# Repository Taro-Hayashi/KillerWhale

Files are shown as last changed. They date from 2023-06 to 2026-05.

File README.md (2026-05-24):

# Killer Whale ビルドガイド スタートページ（[English](doc/README_EN.md)）

1. スタートページ（このページ）
2. [ベースユニットの組み立て](doc/右手用/2_ベースユニット.md)
3. [側面ユニットの組み立て](doc/右手用/3_側面ユニット_トラックボール.md)
4. [天面ユニットの組み立て](doc/右手用/4_天面ユニット.md)
5. [追加ユニットの組み立て](doc/右手用/5_追加ユニット.md)
6. [全体の組み立て](doc/右手用/6_全体の組み立て.md)
7. [カスタマイズ](doc/右手用/7_カスタマイズ.md)
8. [その他](doc/右手用/8_その他.md)

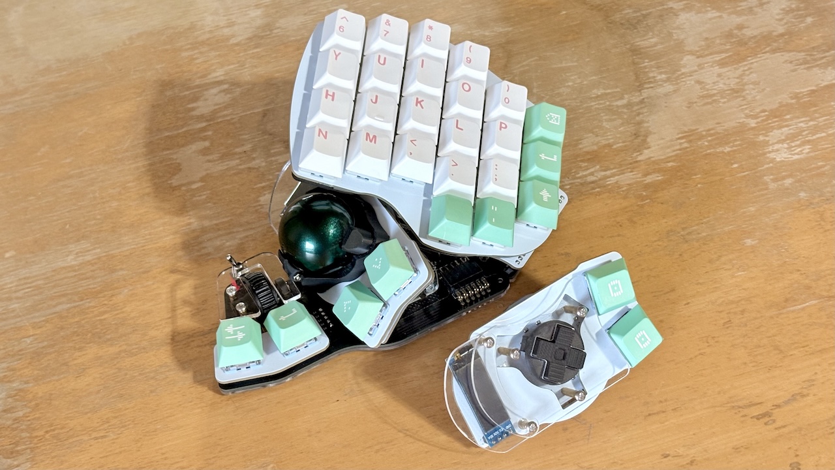
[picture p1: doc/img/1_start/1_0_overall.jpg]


> [!NOTE]
> 2025年5月下旬より一部の部品が3Dプリンター製に置き換わりました。写真や作例と差異がある場合があります。

大きな袋の中にスイッチプレートと6つの袋が入っています。
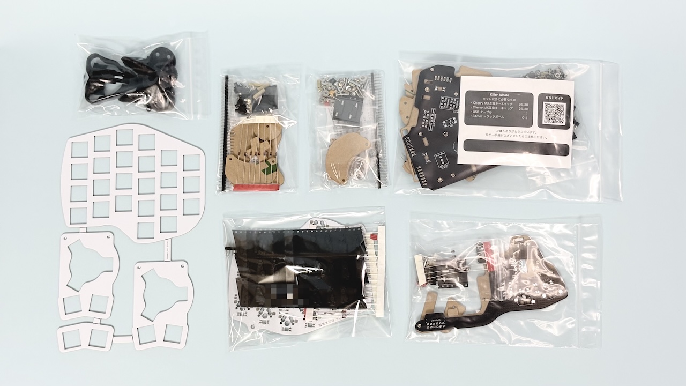
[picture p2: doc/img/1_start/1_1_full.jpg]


## キット以外に必要なもの（片手分）
|部品名|数||
|-|-|-|
|[キースイッチ](https://shop.yushakobo.jp/collections/all-switches)|26〜30|Cherry MX互換|
|[キーキャップ](https://shop.yushakobo.jp/collections/keycaps)|26〜30|Cherry MX互換|
|Type-C USBケーブル|1||
|34mm トラックボール|0~1|[遊舎工房](https://shop.yushakobo.jp/products/8020)、[Amazon](https://www.amazon.co.jp/gp/product/B07BDGSX5X)|

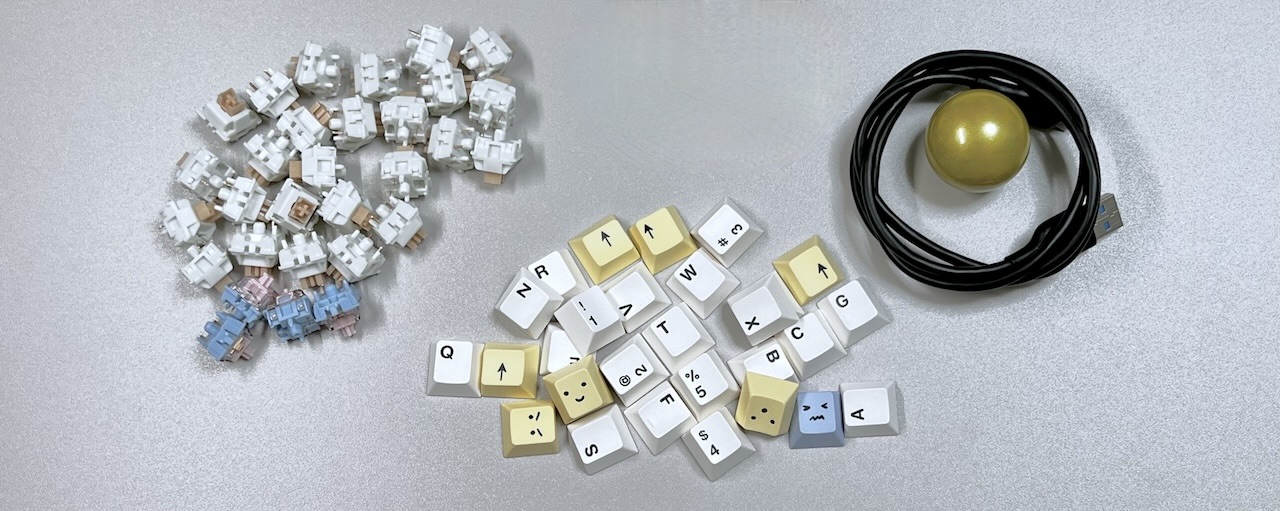
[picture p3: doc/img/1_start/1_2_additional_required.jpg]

### オプション（片手分）
<table>
    <tr>
      <td><a href="https://shop.yushakobo.jp/products/oled">OLEDモジュール</a></td>
      <td>1〜2</td>
      <td>通常は1個、予備の側面ユニットにも付けるならもう1個</td>
    </tr>
    <tr>
      <td>ピンソケット4ピン分</td>
      <td>1〜2</td>
      <td>OLEDモジュールを付け外しする場合</td>
    </tr>
    <tr>
      <td><a href="https://shop.yushakobo.jp/products/sk6812mini-e-10">LED（SK6812MINI-E)</a></td>
      <td>30〜36</td>
      <td>通常は33個、追加ユニットなしで30個、予備の側面ユニットに3個</td>
    </tr>
    <tr>
      <td><a href="https://shop.yushakobo.jp/products/trrs_cable">TRS、TRRSケーブル</a></td>
       <td>1</td>
      <td>2台を繋げて左右分割キーボードとして使用できます。  </td>
    </tr>
 </table>

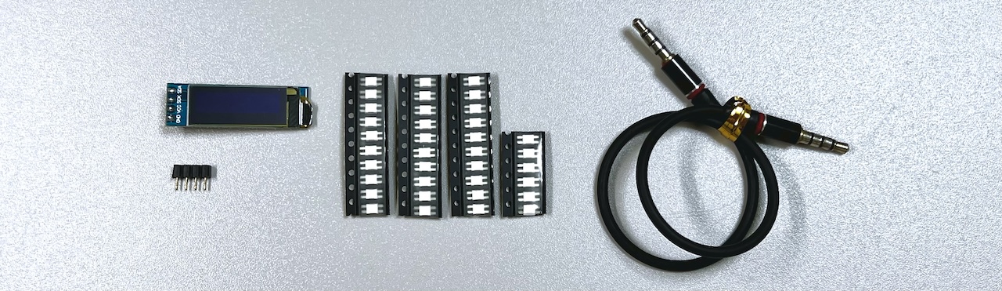
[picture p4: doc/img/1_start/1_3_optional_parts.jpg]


### 必要な工具
<table>
    <tr>
      <td>はんだごて</td>
    </tr>
    <tr>
      <td>はんだ</td>
    </tr>
    <tr>
      <td>ピンセット</td>
    </tr>
    <tr>
      <td>ニッパー</td>
    </tr>
    <tr>
      <td>カッター</td>
    </tr>
    <tr>
      <td>やすり</td>
    </tr>
    <tr>
      <td>精密ドライバー</td>
    </tr>
    <tr>
      <td>ナットをしめるもの（ラジオペンチ等）</td>
    </tr>
 </table>

### 別売ユニット
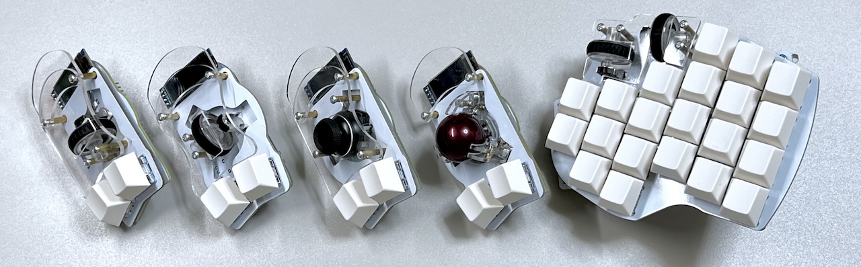
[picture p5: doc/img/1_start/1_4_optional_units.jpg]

- https://tarohayashi.booth.pm/items/4877491

### 別売3Dプリンター製部品
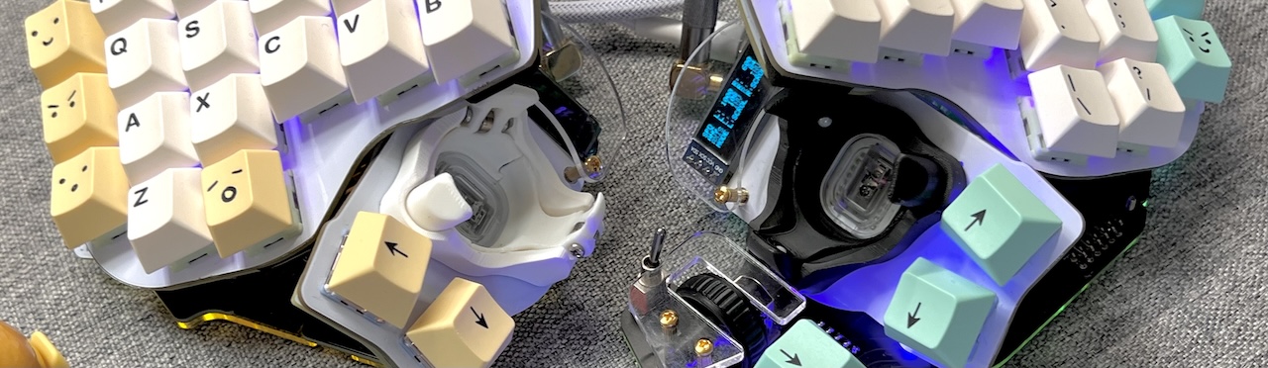
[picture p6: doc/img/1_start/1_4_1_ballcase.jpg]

- https://tarohayashi.booth.pm/items/6485486

### 3Dプリント品データ
- https://github.com/Taro-Hayashi/KillerWhale/blob/main/doc/3DP.md

### 色違いのアクリルプレート
<table>
    <tr>
        <td><a href="https://shop.yushakobo.jp/products/keyboard_acrylic_plate?variant=47873651245287">左手用</a></td>
        <td><a href="https://shop.yushakobo.jp/products/keyboard_acrylic_plate?variant=47873651278055">右手用</a></td>
        <td><a href="https://shop.yushakobo.jp/products/keyboard_acrylic_plate?variant=47873651310823">支柱</a></td>
    </tr>
 </table>

### そのほか対応しているもの
<table>
    <tr>
      <td><a href="https://shop.yushakobo.jp/products/31?variant=40815840067745">コンスルー20ピン 2.5mm</a></td>
    </tr>
    <tr>
      <td>ゲームボーイの十字キー</td>
    </tr>
    <tr>
      <td><a href="https://booth.pm/ja/items/5410034">3Dプリンター製ケース（Training&KBD様作）</a></td>
    </tr>
    <tr>
      <td><a href="https://nankatsukurouyo.myportfolio.com/killerwhale">トラックボールケース3Dプリントデータ（せう様作）</a></td>
    </tr>
    <tr>
      <td><a href="https://booth.pm/ja/items/5341402">Killer Whale Keyboard trackball case（NHRD様作）</a></td>
    </tr>
    <tr>
      <td><a href="https://booth.pm/ja/items/5676575">UndertowとUndertow Alterna</a></td>
    </tr>
 </table>

## 準備

### 3Dプリンター製部品の確認
以下の部品が入っている袋があることを確認します（ナット締め器が同梱されていることがあります）。
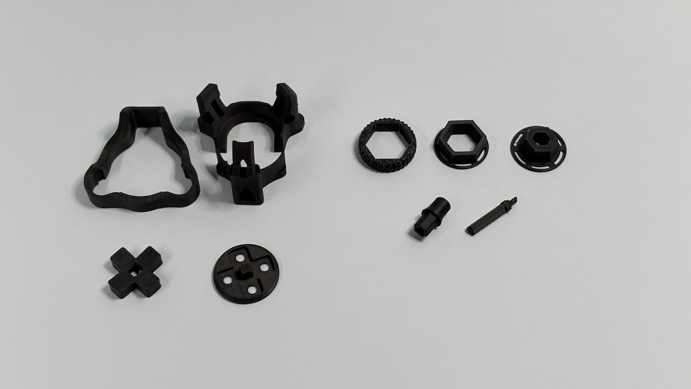
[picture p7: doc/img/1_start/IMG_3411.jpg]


### スイッチプレートの切り離し
スイッチプレートは繋がった状態で入っていて切り離して使います。
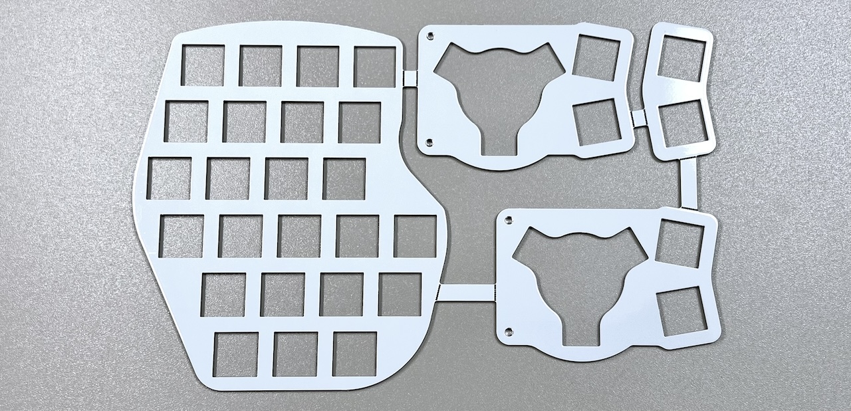
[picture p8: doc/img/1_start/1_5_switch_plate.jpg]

カッターで切れ目を入れ折って切り離します。
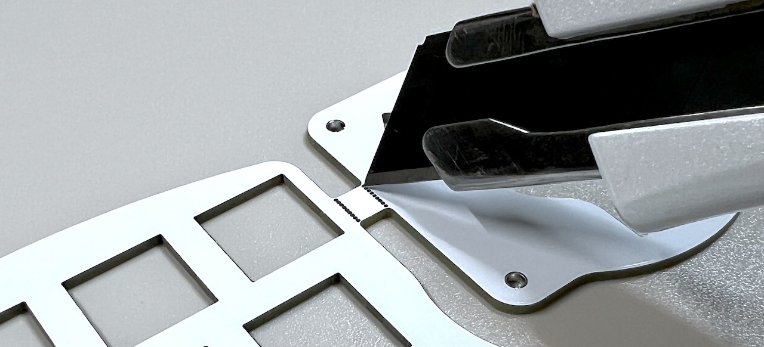
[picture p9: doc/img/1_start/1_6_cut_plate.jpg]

断面はやすりで綺麗にします。
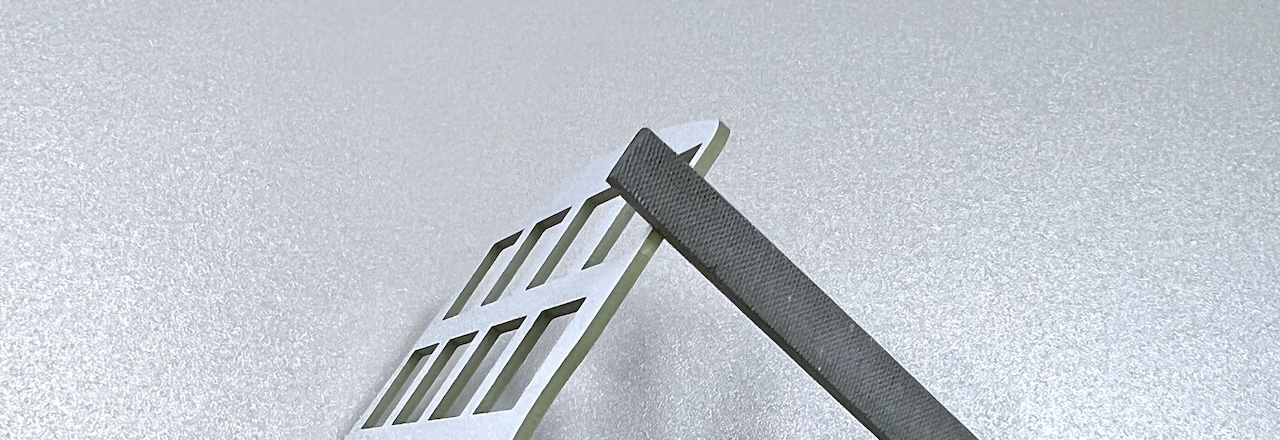
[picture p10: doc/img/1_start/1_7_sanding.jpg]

削った粉がコネクタ類やトラックボールのセンサーに入り込まないようにここで一度服を払ったり机の上の掃除をすると安心です。
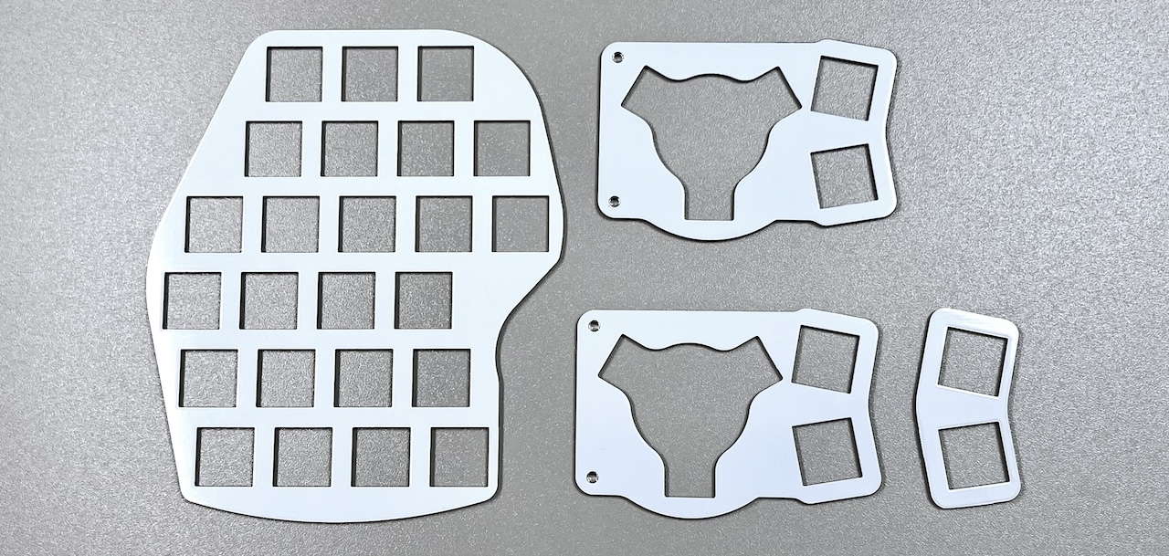
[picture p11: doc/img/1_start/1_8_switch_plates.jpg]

それぞれのユニットのビルドガイドでスイッチプレートとして使います。

## テスト用ファームウェアを書き込む
こちらのファイルをダウンロードしてください。
- [tarohayashi_killerwhale_solo_test.uf2
](https://github.com/Taro-Hayashi/KillerWhale/releases/latest/download/tarohayashi_killerwhale_solo_test.uf2)

Raspberry Pi PicoのBOOTSELボタン押しながらUSBケーブルでPCと接続すると、RPI-RP2というUSBメモリとして認識されます。
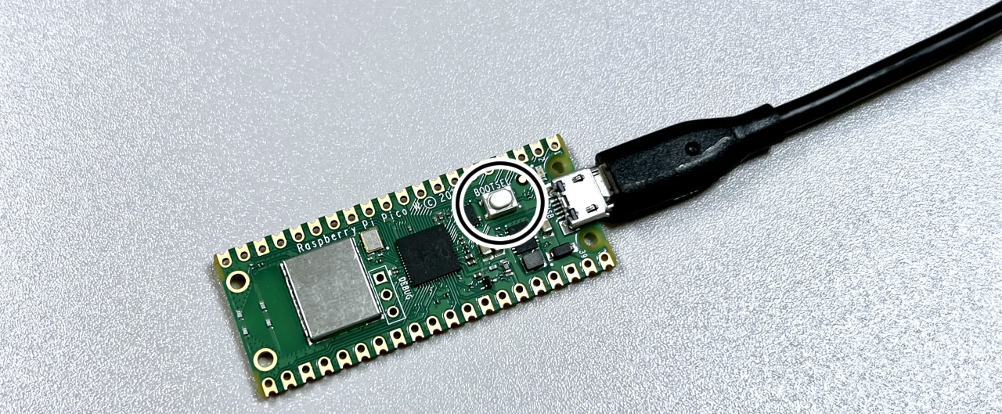
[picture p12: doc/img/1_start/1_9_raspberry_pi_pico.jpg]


ダウンロードしたファイルをドラッグ&ドロップしてドライブが自動的に消えたら成功です。
書き込みが終わったら一旦USBケーブルは外します。

### 左右を決める
キットを左右どちらで作るか決めてベースユニットの組み立てに進みます。
- [ベースユニット 左手用](doc/左手用/2_ベースユニット.md)
- [ベースユニット 右手用](doc/右手用/2_ベースユニット.md)

> [!NOTE]
> 左右のビルドガイドの違いは写真だけですが間違えやすいので合った側を見るのがおすすめです。

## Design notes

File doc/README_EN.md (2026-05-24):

# Killer Whale Build Manual First Page（[日本語](../README.md)）

1. Start Page
2. [BASE Unit](rightside/2_BASE.md)
3. [SIDE Unit](rightside/3_SIDE_TRACKBALL.md)
4. [TOP Unit](rightside/4_TOP.md)
5. [ADD Unit](rightside/5_ADD.md)
6. [Assemble](rightside/6_ASSEMBLE.md)
7. [Customize](rightside/7_CUSTOM.md)
8. [Misc](rightside/8_MISC.md)



> [!NOTE]
> Some parts have been replaced by 3D printer-made parts from late May 2025. There may be differences from photographs and examples.

There are 6 bag and switch plates included in the largest bag.


## Additionally Required (quantities for or one side)
<table>
    <tr>
      <td>MX switches</td>
       <td>between 26 and 30</td>
    </tr>
    <tr>
      <td>Keycaps</td>
      <td>between 26 and 30</td>
    </tr>
    <tr>
      <td>Type-C USB cable</td>
       <td>1</td>
    </tr>
    <tr>
      <td>34mm Trackball</td>
       <td>0 or 1</td>
    </tr>
 </table>


### Optional Parts (quantities for one side)
<table>
    <tr>
      <td>OLED Display module</td>
      <td>1 or 2</td>
      <td>Normally just one, but you can add one more to the side unit</td>
    </tr>
    <tr>
      <td>Pin socket 4pin</td>
      <td>1 or 2</td>
      <td>If you want to pull out OLED module.</td>
    </tr>
    <tr>
      <td>LEDs (SK6812MINI-E)</td>
      <td>Between 30 and 36</td>
      <td>Normally 33, or just 30 without the additional unit, and 3 more for the side unit</td>
    </tr>
    <tr>
      <td>TRS or TRRS Cable</td>
       <td>1</td>
       <td>Used to connect the left and right parts of the keyboard</td>
    </tr>
</table>



### Optional Units (sold separately)


https://tarohayashi.booth.pm/items/4877491

### Optional 3D Printed Parts (sold separately)


- https://tarohayashi.booth.pm/items/6485486

### 3D Printed Parts Data

https://github.com/Taro-Hayashi/KillerWhale/blob/main/doc/3DP_EN.md


https://github.com/Taro-Hayashi/KillerWhale/blob/main/doc/3DP_EN.md

### Optional Acrylic Plates
<table>
    <tr>
      <td><a href="https://shop.yushakobo.jp/products/keyboard_acrylic_plate?variant=47873651245287">LEFT Side</a></td>
    </tr>
    <tr>
      <td><a href="https://shop.yushakobo.jp/products/keyboard_acrylic_plate?variant=47873651278055">RIGHT Side</a></td>
    </tr>
    <tr>
      <td><a href="https://shop.yushakobo.jp/products/keyboard_acrylic_plate?variant=47873651310823">Pillars</a></td>
    </tr>
 </table>

### 3D Printed Cases (made by Training&KBD)
- https://booth.pm/ja/items/5410034

### 3D Printed Trackball Case  (made by thw)
- https://nankatsukurouyo.myportfolio.com/killerwhale

### Killer Whale Keyboard trackball case  (made by NHRD)
- https://nankatsukurouyo.myportfolio.com/killerwhale

### Undertow
- https://booth.pm/ja/items/5676575

### Required tools and consumables
<table>
    <tr>
      <td>Soldering iron</td>
    </tr>
    <tr>
      <td>Solder</td>
    </tr>
    <tr>
      <td>Tweezers</td>
    </tr>
    <tr>
      <td>Nipper</td>
    </tr>
    <tr>
      <td>Cutter</td>
    </tr>
    <tr>
      <td>File (for sanding)</td>
    </tr>
    <tr>
      <td>Precision screwdriver (cross/Philipps type)</td>
    </tr>
    <tr>
      <td>Tool for tightening nuts (radio pliers, M2 spanner)</td>
    </tr>
 </table>

## Preparations
### Confirmation of parts made by 3D printer
Make sure the following components are included in one of the bag.
]
### Detach the switch plates
Switch plates are initially attached, and must be separated.

Make a cut with a cutter, and separate by bending the plates.

Sand the side with a file.

After sanding, make sure to clean your bench and brush off residues from you clothes to prevent them from getting inside connectors or trackball sensor.

Switch plates will be used in the build guide of each unit.

## Write Testing firmware
Download the following uf2 file.
- [tarohayashi_killerwhale_solo_test.uf2
](https://github.com/Taro-Hayashi/KillerWhale/releases/latest/download/tarohayashi_killerwhale_solo_test.uf2)

Connect the Raspberry Pi Pico to the PC while holding down the BOOTSEL button, it will be recognized as a USB memory device called RPI-RP2.



After downloading the uf2 file, drag and drop the file to the USB drive. If the drive disappears, flashing was successful.
After flashing, disconnect the USB cable.

### Decide to build left or right side
Decide if you build the left or right side of the keyboard and proceed to BASE Unit page.
- [BASE Unit LEFT Side](leftside/2_BASE.md)
- [BASE Unit RIGHT Side](rightside/2_BASE.md)

> [!NOTE]
> The only differences between the left and right build guides are the pictures, but since it is easy to make mistakes, it is recommended to follow the right build guide.

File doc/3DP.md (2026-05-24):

# Killer Whale 3Dプリンター製パーツ（[English](3DP_EN.md)）

# ボールケース

印刷用のモデルと送付のために分割したモデルがあります。

## 組み立て方
ベアリングの場合は10mmのM2ネジとナットでベアリングを固定します。
メインボードに10mmのM3ネジとナットでケースを固定します。
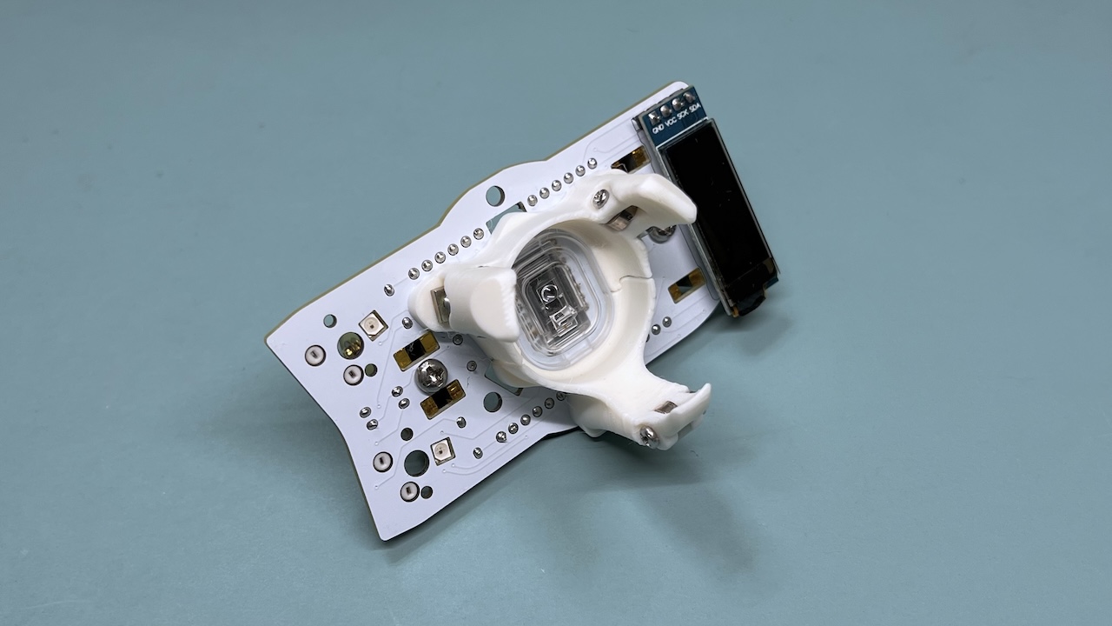
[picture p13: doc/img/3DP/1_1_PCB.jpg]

スイッチプレートを取り付けます。
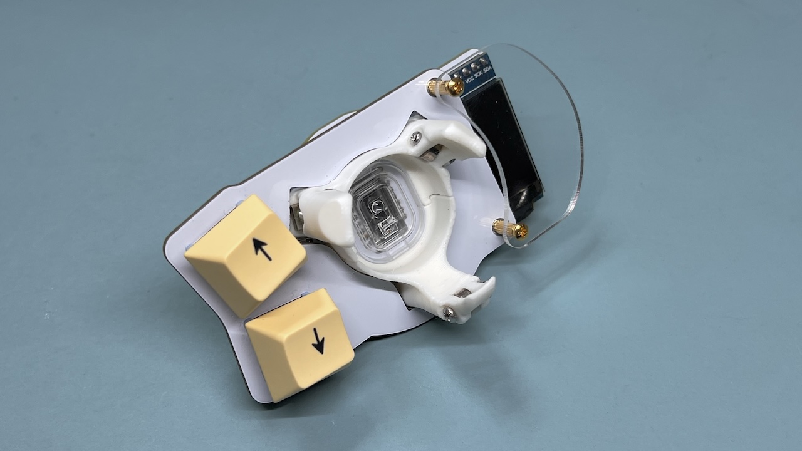
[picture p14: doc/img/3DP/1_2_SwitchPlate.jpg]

カバーを被せます。
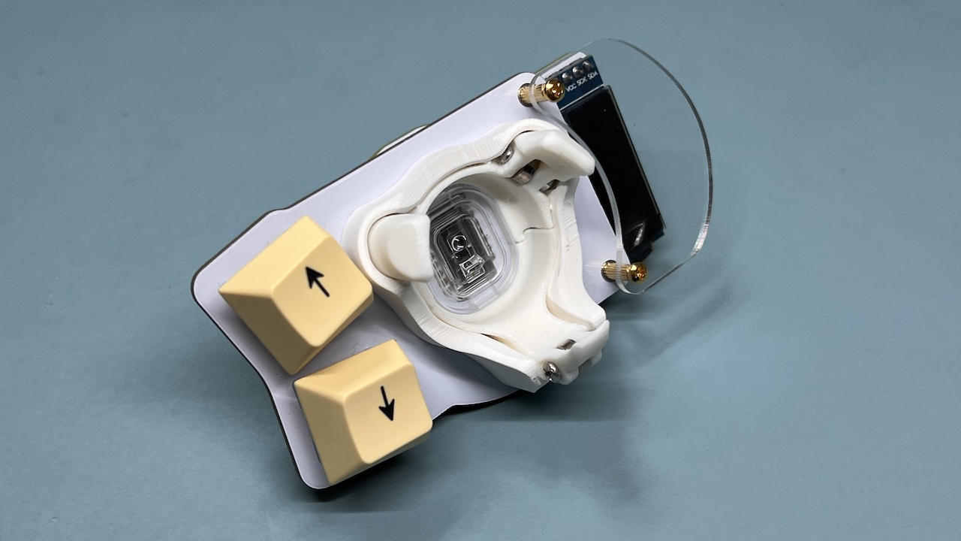
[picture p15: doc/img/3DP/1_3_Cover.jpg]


## ファイル内容
### ベアリング方式

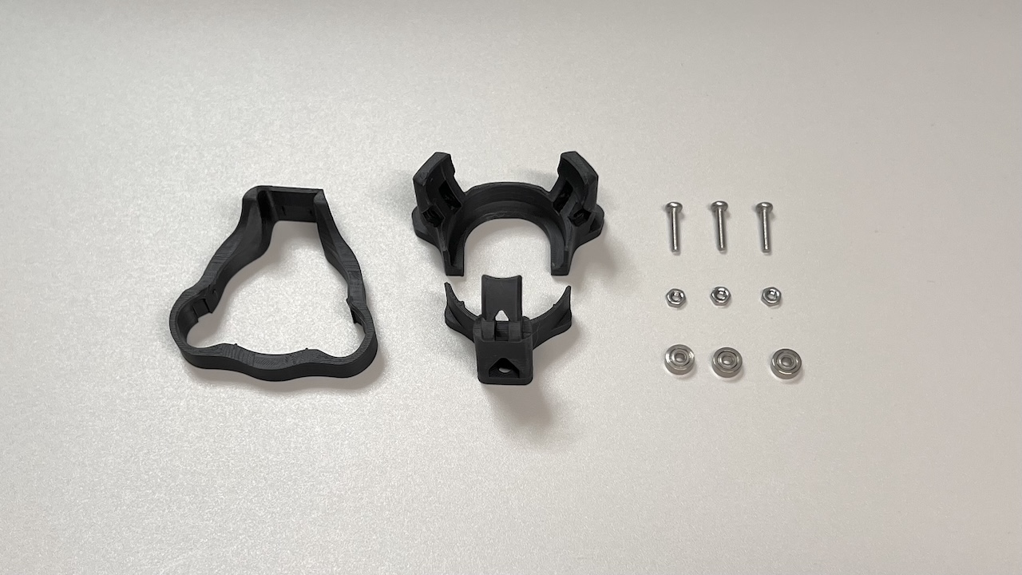
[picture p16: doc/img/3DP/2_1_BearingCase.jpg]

https://github.com/Taro-Hayashi/KillerWhale/tree/main/stl/Ballcase_34mm_Bearing
|ファイル名||
|-|-|
|Integrated.stl|一体型データ|
|Separated #1.stl|分割データ|
|Separated #2.stl||
|Cover.stl|スイッチプレートカバー|

|部品名||
|-|-|
|M2ねじ|10mm|
|M2ナット||
|ベアリング|2x6x2.5|

### 支持球方式

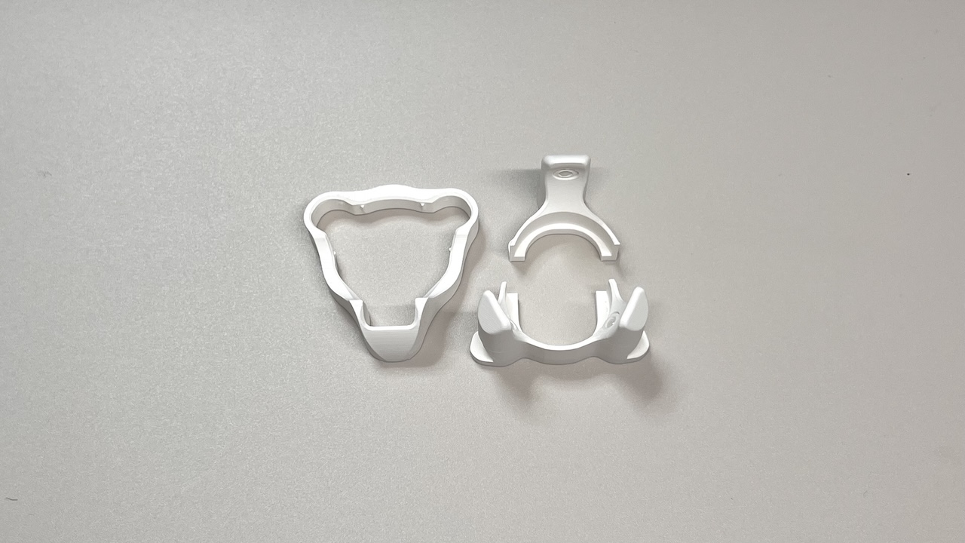
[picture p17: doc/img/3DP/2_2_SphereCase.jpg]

https://github.com/Taro-Hayashi/KillerWhale/tree/main/stl/Ballcase_34mm_Sphere

|ファイル名||
|-|-|
|Integrated.stl|一体型データ|
|Separated #1.stl|分割データ|
|Separated #2.stl||
|Cover.stl|スイッチプレートカバー|

### ボールユニット
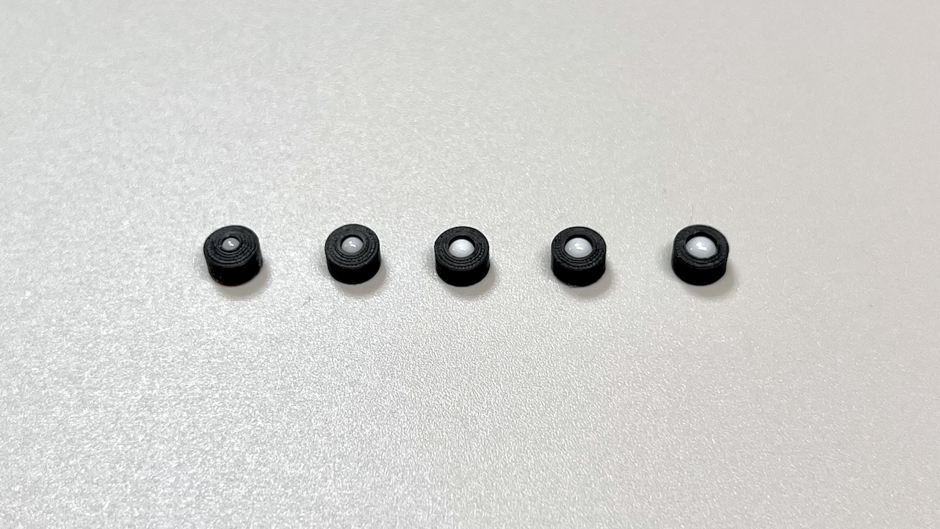
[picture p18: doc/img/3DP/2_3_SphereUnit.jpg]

https://github.com/Taro-Hayashi/KillerWhale/tree/main/stl/Sphere_Unit
|ファイル名||
|-|-|
|2mm.stl||
|2.5mm.stl||
|3mm.stl||
|3.175mm.stl||
|3.5mm 0.2mm nozzle.stl|0.2mmノズル向けモデル|
|3.5mm 0.4mm nozzle.stl|0.4mmノズル向けモデル|

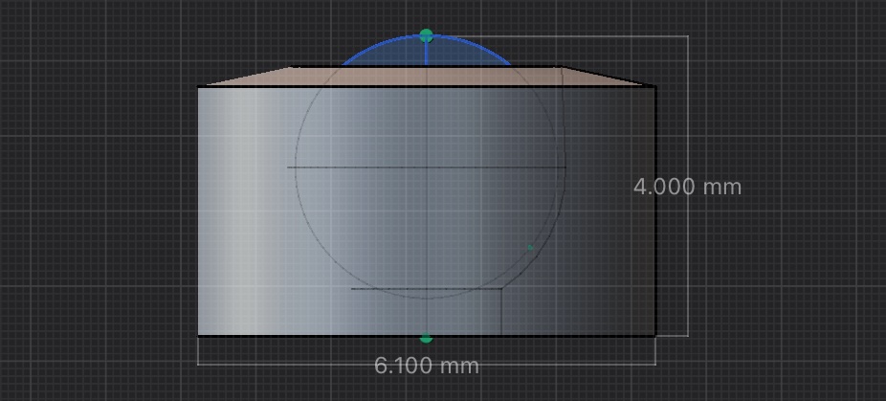
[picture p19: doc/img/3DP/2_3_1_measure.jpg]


# 十字キー
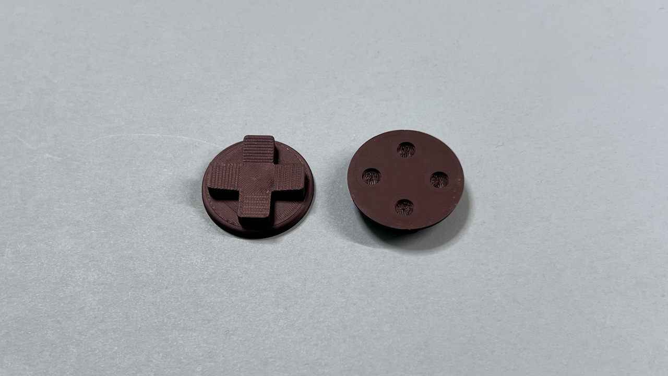
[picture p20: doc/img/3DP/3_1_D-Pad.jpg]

https://github.com/Taro-Hayashi/KillerWhale/tree/main/stl/D-Pad
|ファイル名||
|-|-|
|D-Pad.stl||

# ホイール
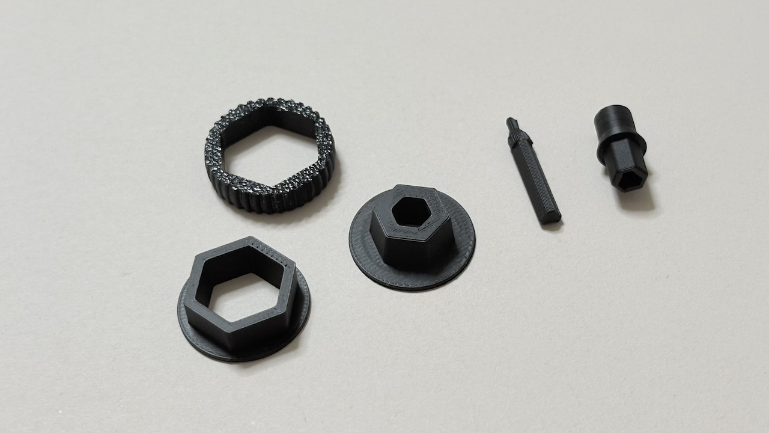
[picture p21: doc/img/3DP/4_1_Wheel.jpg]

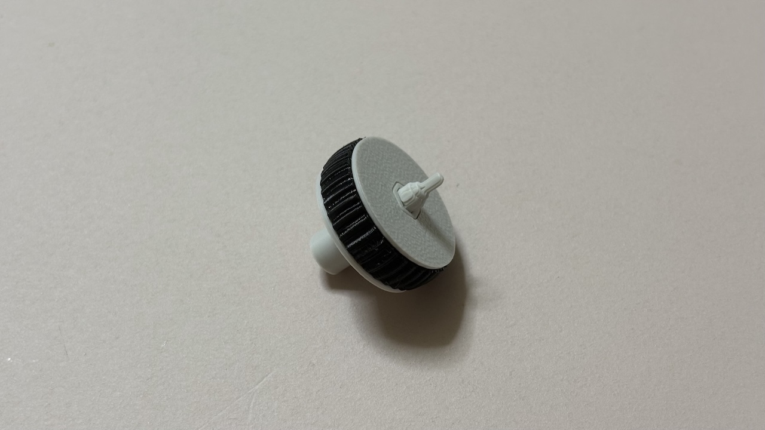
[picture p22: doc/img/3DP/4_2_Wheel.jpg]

https://github.com/Taro-Hayashi/KillerWhale/tree/main/stl/Wheel
|ファイル名||
|-|-|
|Wheel.stl||
|Shaft.stl||

# ジョイスティックキャップ
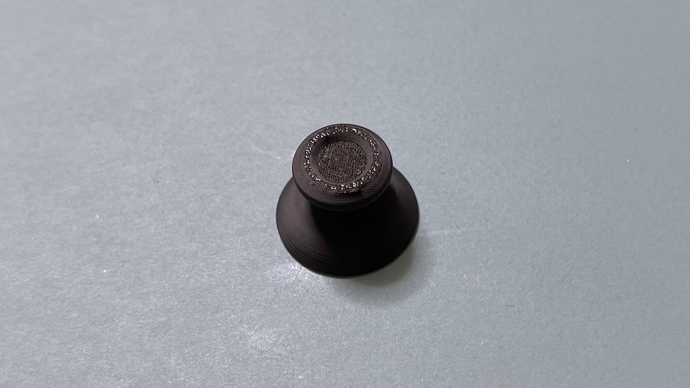
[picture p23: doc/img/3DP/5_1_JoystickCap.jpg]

https://github.com/Taro-Hayashi/KillerWhale/tree/main/stl/Joystick
|ファイル名||
|-|-|
|Joystick.stl||

## 販売サイト
- https://tarohayashi.booth.pm/items/6485619

<p xmlns:cc="http://creativecommons.org/ns#" xmlns:dct="http://purl.org/dc/terms/"><a property="dct:title" rel="cc:attributionURL" href="https://github.com/Taro-Hayashi/KillerWhale/tree/main/doc/3DP.md">Killer Whale 3Dプリント部品</a> by <a rel="cc:attributionURL dct:creator" property="cc:attributionName" href="https://x.com/w_vwbw">Taro Hayashi</a> is licensed under <a href="https://creativecommons.org/licenses/by/4.0/?ref=chooser-v1" target="_blank" rel="license noopener noreferrer" style="display:inline-block;">CC BY 4.0</a></p>

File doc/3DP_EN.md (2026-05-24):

# Killer Whale 3D Printed Parts（[日本語](3DP.md)）

# Ballcase
There are models for printing and split models for sending.

## How to assemble
Secure the bearing case with 10 mm M2 screws and nuts.
Secure the case to the mainboard with 10 mm M3 screws and nuts.

Install switch plate.

Covering.


## File contents
### Bearing case


https://github.com/Taro-Hayashi/KillerWhale/tree/main/stl/Ballcase_34mm_Bearing
|Filename|
|-|
|Integrated.stl|
|Separated #1.stl|
|Separated #2.stl|
|Cover.stl|

|Parts||
|-|-|
|M2 screws|10mm|
|M2 nuts||
|Bearings|2x6x2.5|

### Ceramic ball case


https://github.com/Taro-Hayashi/KillerWhale/tree/main/stl/Ballcase_34mm_Sphere

|Filename|
|-|
|Integrated.stl|
|Separated #1.stl|
|Separated #2.stl|
|Cover.stl|

### Sphere Unit

https://github.com/Taro-Hayashi/KillerWhale/tree/main/stl/Sphere_Unit
|Filename|
|-|
|2mm.stl|
|2.5mm.stl|
|3mm.stl|
|3.175mm.stl|
|3.5mm 0.2mm nozzle.stl|
|3.5mm 0.4mm nozzle.stl|

# D-Pad

https://github.com/Taro-Hayashi/KillerWhale/tree/main/stl/D-Pad
|Filename|
|-|
|D-Pad.stl|
# Wheel


https://github.com/Taro-Hayashi/KillerWhale/tree/main/stl/Wheel
|Filename|
|-|
|Wheel.stl|
|Shaft.stl|
# Joystick Cap

https://github.com/Taro-Hayashi/KillerWhale/tree/main/stl/Joystick
|Filename|
|-|
|Joystick.stl|

<p xmlns:cc="http://creativecommons.org/ns#" xmlns:dct="http://purl.org/dc/terms/"><a property="dct:title" rel="cc:attributionURL" href="https://github.com/Taro-Hayashi/KillerWhale/tree/main/doc/3DP_EN.md">Killer Whale 3D Printed Parts</a> by <a rel="cc:attributionURL dct:creator" property="cc:attributionName" href="https://x.com/w_vwbw">Taro Hayashi</a> is licensed under <a href="https://creativecommons.org/licenses/by/4.0/?ref=chooser-v1" target="_blank" rel="license noopener noreferrer" style="display:inline-block;">CC BY 4.0</a></p>

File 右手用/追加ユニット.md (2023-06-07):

# Killer Whale 追加ユニット 右手用ビルドガイド （[左手用](../左手用/ベースユニット.md)）

1. [スタートページ](../README.md)
2. [ベースユニットの組み立て](../右手用/ベースユニット.md)
3. 追加ユニットの組み立て（このページ）
5. [側面ユニットの組み立て](../右手用/側面ユニット.md)
6. [天面ユニットの組み立て](../右手用/天面ユニット.md)
7. [カスタマイズ](../右手用/カスタマイズ.md)

## 内容品
追加ユニットの袋に入っているものです。
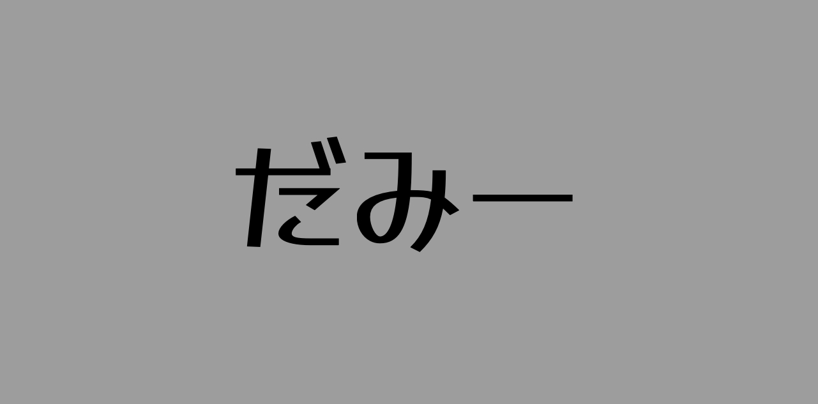
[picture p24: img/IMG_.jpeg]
ダミーキャプション ベース部品
  
||部品名|数||
|-|-|-|-|
|1|メインボード|1|FR4|
|2|ボトムプレート|1|アクリル|
|3|保護プレート|1|アクリル|
|4|M2バインドねじ|2|6mm|
|5|M2スペーサー（短）|1|8mm|
|6|M2スペーサー（長）|2|16mm|
|7|M2ネジ（黒）(短）|3|6mm|
|8|M2ネジ（黒）(長）|3|8mm|
|9|M2ワッシャー（黒）|||
|10|M2スプリングワッシャー（黒）|4|
|11|M2ナット（黒）|4|
|12|ダイオード|5||
|13|L字ピンヘッダ|1||
|14|ホイールエンコーダー|1||
|15|ホイール|1||
|16|トグルスイッチ|1||
|17|MXスイッチソケット|2||

## はんだ付け
追加ユニットは表裏両方に部品を実装するので気をつけてください。
表側にはんだ付けするもの: ホイールエンコーダー、トグルスイッチ、L字ピンヘッダ
裏側にはんだ付けするもの: ダイオード、MXスイッチソケット、（オプション）LED

### （オプション）LED部品のはんだ付け（裏側）
追加ユニットには3箇所、すべて裏側にはんだ付けします。基板の角のマークとLEDの足の切り欠きの方向が一致するようにします。
ダミーキャプション
2個は丸い発光面がが向こう向き、間の一つはこちら向きになります。
ダミーキャプション

### ダイオードのはんだ付け（裏側）
縦に並んだ5箇所にダイオードを差し、マスキングテープで固定します。
ダミーキャプション
裏返したらはんだ付けして足を切ります（自信がある人は先に足を切ってはんだ付けすると綺麗に仕上がります）。
ダミーキャプション

### MXスイッチソケットのはんだ付け（裏側）
ピンセットで固定してハンダごてに乗せたはんだを流し込みます。
ダミーキャプション
両側をはんだしてずれなくなったらピンセットからはんだに持ち替えて追加で流し込みしましょう。表面積が広く多めのはんだが必要です。

### L字ピンヘッダのはんだ付け（表側）
マスキングテープで固定して裏側をはんだ付けします。
ダミーキャプション

### ホイールエンコーダーのはんだ付け（表側）
エンコーダーの裾のプレートを少し広げます（ショートを防ぐため）。
ダミーキャプション
基板の四角マークに合わせてホイールを差し込みマスキングテープで垂直に固定したら、裏面をはんだ付けします。
ダミーキャプション
まず3つの細いピンをはんだ付けして、傾きを補正しながらクリップ状のピンをはんだ付けすると固定しやすいです。
ダミーキャプション

### トグルスイッチのはんだ付け
表から差して裏ではんだ付けします。手のひらと逆向きに傾けてオフの状態にしておくと安全です。

ダミーキャプション
追加ユニットのはんだ付けは以上です。

## 組み立て
### アクリルプレートの取り付け
M2ねじ（黒）計6本にワッシャー(黒）を通します。
ダミーキャプション
追加ユニットの裏にボトムプレートをあててM2ねじ（黒）（短）をホイールエンコーダーの反対側のネジ穴に通します。
ダミーキャプション
表はM2スペーサー（長）とM2スペーサー（短）で止めます。中央にM2スペーサー（短）を使ってください。
ダミーキャプション
ホイールをホイールエンコーダーに差し込み、保護プレートを載せてM2バインドネジで固定します。
ダミーキャプション

側面ユニットの組み立てに進んでください。
4. [側面ユニットの組み立て](../右手用/側面ユニット.md)

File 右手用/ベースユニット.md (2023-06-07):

# Killer Whale ベースユニット 右手用ビルドガイド （[左手用](../左手用/ベースユニット.md)）

1. [スタートページ](../README.md)
2. ベースユニットの組み立て（このページ）
3. [追加ユニットの組み立て](../右手用/追加ユニット.md)
4. [側面ユニットの組み立て](../右手用/側面ユニット_トラックボール.md)
5. [天面ユニットの組み立て](../右手用/天面ユニット.md)
6. [カスタマイズとトラブルシューティング](../右手用/カスタマイズとトラブルシューティング.md)

## 内容品
ベースユニットの袋に入っているものです。
ダミーキャプション ベース部品  
||部品名|数||
|-|-|-|-|
|1|メインボード|1|FR4|
|2|ボトムプレート|1|アクリル|
|3|側面ユニット支柱|4|アクリル|
|4|天面ユニット支柱|4|アクリル|
|5|M2なべネジ|12|10mm|
|6|M2ワッシャー|24||
|7|M2スプリングワッシャー|12||
|8|M2スペーサー|12|3mm|
|9|M2ネジ（黒）|4|8mm|
|10|M2ワッシャー（黒）|8||
|11|M2スプリングワッシャー（黒）|4|
|12|M2ナット（黒）|4|
|13|M3なべネジ|11|10mm|
|14|M3ワッシャー|11||
|15|M3四角ナット|11||
|16|TRRSジャック|2||
|17|ピンヘッダ|2||
|18|ピンソケット|2||
|19|L字ピンソケット|1||
|20|ジャンパー|6||

以下はLED用の小さい部品で専用の小袋に入っています
<table>
    <tr>
      <td>21</td>
      <td>MOSFET</td>
      <td>1</td>
      <td>BSS138</td>
    </tr>
    <tr>
      <td>22</td>
      <td>抵抗</td>
      <td>2</td>
      <td>10kΩ</td>
    </tr>
 </table>

ベースユニットには全ての部品を表面に実装します。
ダミーキャプション
### Raspberry Pi Picoのはんだ付け
ピンヘッダを20ピンずつニッパーで切り差し込みます。
ダミーキャプション
左右でRaspberry Pi Picoの裏表が変わるのでGP0,VBUSの位置を確認して合わせてください。
ダミーキャプション
表裏両面をはんだ付けします。
ダミーキャプション

### L字ピンソケットのハンダ付け
マスキングテープを使って水平になるように固定して、裏側をはんだ付けします。
ダミーキャプション

### TRRSジャックのはんだ付け
2箇所取り付け位置があり好きな方だけはんだ付けしても両方はんだ付けしても、2台を接続する予定がない場合は取り付けなくても問題ありません。
ダミーキャプション

### ジャンパーピンのはんだ付け
ジャンパーピンを3ピンを二つ、4ピンを二つ切り出し、枠で囲われたところにはんだ付けします。 
マスキングテープを突き破るように固定すると垂直に付けやすいです。
ダミーキャプション
ここは取り付けるサイドユニットの種類にはんだ付けしてください。  
ダミーキャプション
ピンヘッダーは余分に入っているので全部つけてしまっても問題ありません。  
ダミーキャプション
3箇所にジャンパーピンを6つ差し込み、どのように組み立てるかを選びます。  
右手側、追加ユニットを付け、側面ユニットがトラックボールの場合は以下のようになります。
ダミーキャプション

### （オプション）LED部品のはんだ付け
LED用小袋内のMOSFETと抵抗を取り付けます。部品が小さいのでピンセットを使いやけどをしないように注意してください。
ダミーキャプション BSS138  
LEDには向きがあります。丸い発光面が裏向きになり、基板の角のマークとLEDの足の切り欠きの方向が一致するようにします。
ダミーキャプション LED
ベースユニットには3箇所取り付けます。
ダミーキャプション LED場所
USBケーブルを接続して発光するかどうかチェックしましょう
ダミーキャプション

ベースユニットのはんだ付けは以上です。

## 支柱の取り付け

### 支柱の組み立て
支柱は8パーツ4組あります。
ダミーキャプション
前準備としてなべねじ12本にワッシャーを通します。切れ目が入っているのはスプリングワッシャーで、別の機会に使います。
ダミーキャプション
ワッシャー、スプリングワッシャーはナットがゆるむことを防止するために使っています。無くしてしまったりした場合は使わなくても組み立てには問題ありません。
  
ワッシャーを通したなべねじを支柱パーツの片側に通し、スペーサーで止めます。
ダミーキャプション
スリットに四角ナットを斜めにして立てます。小さいパーツは2箇所、中くらいのパーツは3箇所、大きいパーツは4箇所スリットがあります。
ダミーキャプション
反対側の支柱パーツをねじに通して、四角ナットをはさみこみます。
ダミーキャプション
ワッシャー、スプリングワッシャーの順にネジに入れ、ナットで固定します。
ダミーキャプション
最後にドライバーでネジを少し締めるとより強固になります。

### ベースユニットの組み立て
ねじ（黒）4本にワッシャー（黒）を通します。
ダミーキャプション
ベースユニットにボトムプレートをあてて、裏面からネジを差し込みます。
ダミーキャプション
表面にワッシャー、スプリングワッシャーの順に通し、ナットで締めます。
ダミーキャプション

### 支柱の取り付け
M3なべねじ5本にワッシャーを通します。
ダミーキャプション
表面に支柱を立てて裏面からねじ止めします。取り付ける場所、方向は画像を参考にしてください。
ダミーキャプション ベース、

残りの部品はこの後の工程で使うので小皿に入れる等して保管してください。  
追加ユニットは親指用のホイール、トグルスイッチ、キーを追加するユニットで、必須ではありません。取り付けない場合は側面ユニットの組み立てまで飛ばしてください。

3. [追加ユニットの組み立て](../右手用/追加ユニット.md)
4. [側面ユニットの組み立て](../右手用/側面ユニット.md)

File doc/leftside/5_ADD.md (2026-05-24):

# Killer Whale ADD Unit LEFT Side Build Manual （[RIGHT Side](../rightside/5_ADD.md)）

1. [Start Page](../README_EN.md)
2. [BASE Unit](../leftside/2_BASE.md)
3. [SIDE Unit](../leftside/3_SIDE_TRACKBALL.md)
4. [TOP Unit](../leftside/4_TOP.md)
5. ADD Unit LEFT Side
6. [Assembly](../leftside/6_ASSEMBLE.md)
7. [Customizations](../leftside/7_CUSTOM.md)
8. [Misc](../leftside/8_MISC.md)

## Contents

||types|quantities||
|-|-|-|-|
|1|Main board|1|FR4|
|2|Switch plate|1|FR4|
|3|Bottom plate|1|Acrylic|
|4|Cover plate|1|Acrylic|
|5|M2 middle screws|2|6mm|
|6|M2 short spacer|1|8mm|
|7|M2 long spacers|2|16mm|
|8|M2 short screws|2|4mm|
|9|M2 long screws|5|8mm|
|10|M2 black washers|6|
|11|M2 black spring washers|3|
|12|M2 black nuts|3|
|13|Diodes|5||
|14|Angle pin header|1||
|15|Wheel encoder|1||
|17|Toggle switch|1||
|18|MX Hotswap sockets|2||
|19|Rubber feet|2||

The following 3D printed parts are also used.
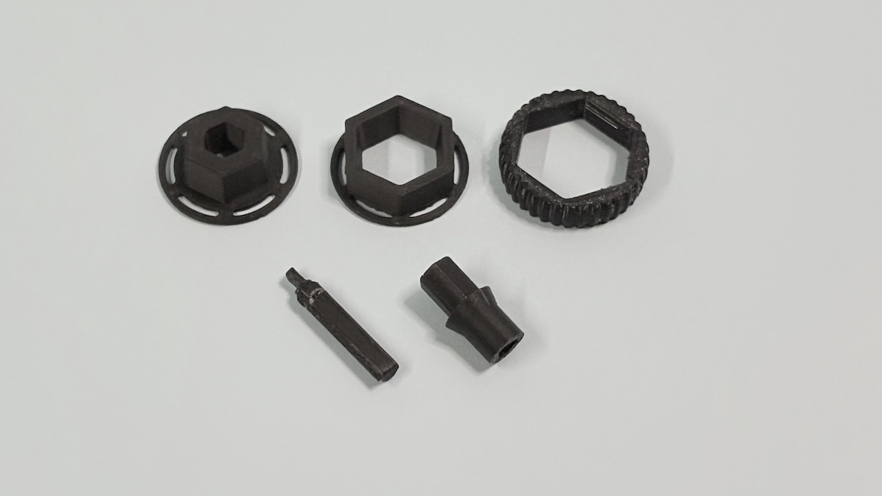
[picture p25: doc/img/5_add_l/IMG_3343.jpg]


## Soldering
Keep in mind that components will be placed on both sides of the ADD unit.


### Soldering of the LEDs (optional, back side)
On the ADD unit, LEDs are soldered from the back side of the PCB, at 3 different locations.

For 2 of the LEDs, the round LED should be facing away from the side where soldering is done, and the one in the middle has the opposite orientation.

### Soldering of the diodes (back side)
Insert the diodes from the back side of the PCB, solder from the front side and cut the legs.


### Soldering of MX hotswap socket (back side)
Solder the MX hotswap sockets while keeping them in place with tweezers.


### Soldering of the angle pin header (front side)
Insert the pin header from the front side of the PCB, solder from the back side of the PCB.

> [!WARNING]
> The side of the soldering has been changed.



### Soldering of the wheel encoder (front side)
 To avoid any short circuit slightly bend the plate at the base of the wheel encoder.

Align the printing on the board with the pin orientation and solder on the reverse side.


### Soldering of the toggle switch (front side)
Insert from the from the front side of the PCB and solder from the back side.


This is the last soldering step for the ADD unit.

## Assembly
### Assembly of the acrylic plate
Thread the M2 black washer onto 1 long M2 screw.


Place the bottom plate on the back of the additional unit and fasten the M2 short spacer with the M2 long screw.
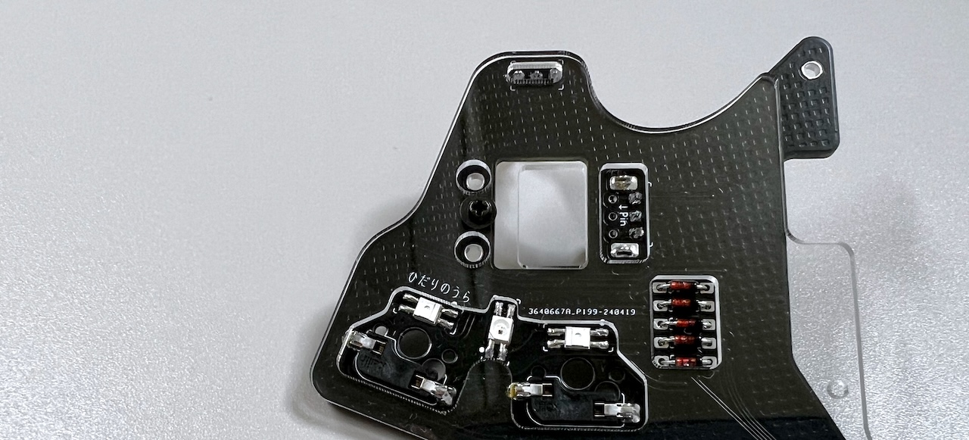
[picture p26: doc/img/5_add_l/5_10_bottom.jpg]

Fasten M2 long spacers with M2 short screws on either side of it.


Combine the wheel parts. Be careful with the direction of the axis of the thinner one.

It may require a little force. The medium axis can come from either direction.


Insert the wheel in the encoder, place the protective acrylic plate and secure it with M2 middle screws.

Attach the switches to the switch plate, and insert the assembly into the MX sockets.

Proceed with the overall assembly

6. [Overall assembly](../leftside/6_ASSEMBLE.md)

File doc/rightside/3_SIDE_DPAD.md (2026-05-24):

# Killer Whale SIDE Unit D-Pad RIGHT Side Build Manual （[LEFT SIDE](../leftside/3_SIDE_DPAD.md)）

1. [Start Page](../README_EN.md)
2. [BASE Unit](../rightside/2_BASE.md)
3. SIDE Unit
   - [Trackball](../rightside/3_SIDE_TRACKBALL.md)
   - D-Pad RIGHT Side
   - [Wheel (sold separately)](../rightside/3_SIDE_WHEEL.md)
   - [Joystick (sold separately)](../rightside/3_SIDE_JOYSTICK.md)
4. [TOP Unit](../rightside/4_TOP.md)
5. [ADD Unit](../rightside/5_ADD.md)
6. [Assembly](../rightside/6_ASSEMBLE.md)
7. [Customizations](../rightside/7_CUSTOM.md)
8. [Misc](../rightside/8_MISC.md)

## Contents

||types|quantities||
|-|-|-|-|
|1|Mainboard|1|FR4|
|2|Switch plate|1|FR4|
|3|Cover plate|2|Acrylic|
|5|M2 short screws|5|4mm|
|6|M2 middle screws|5|6mm|
|9|M2 short spacers|2|5mm|
|10|M2 long spacers|3|12mm|
|11|Diodes|8|1N4148|
|12|MX hotswap sockets|2||
|13|Mute switches|4|
|14|Pin header|1||

The following 3D printed parts are also used.


## Soldering
Note that components will be placed on both sides of the side unit.

The PCB side with text in Japanese is the back side.

### Soldering of the LEDs (optional)
Solder the 3 LEDs. The round LED should be facing away from the side where soldering is done.


### Soldering of MX hotswap socket (back side)
From the back side of the unit, solder the MX hotswap sockets while keeping them in place with tweezers.


### Soldering of the diodes (back side)
Diodes are directional components. Make sure to align the lines with markings on the PCB.

Insert the diodes in the 4 locations on the back side of the PCB, and solder from the front side of the PCB, and cut the diode legs.


### Soldering of pin headers (back side)
Cut out four sets of 6 pins from the 40 pin headers.


Insert the pin headers from the back side and solder.
> [!WARNING]
> Insert the long side of the pins. In case you did it the other way around, cut the long side in order to match the length of the short side.



### Soldering of OLED Display (optional, front side)
If you want to make the OLED module removable, solder a 4pin socket on the surface.


Solder the pin headers to the OLED module.

If the OLED module is to be soldered directly, solder it to the main board at this time.

### Mute switch
### Soldering of the Kailh mute switches (front side)
Insert the switches from the front side of the PCB and solder from the back side.



## Intermediate assembly and soldering of sockets

### Assembling the switch plate

If the switch plate is tagged, fold it and then sand it.

Attach the M2 long spacers and M2 short screws to the switch plate.
> [!NOTE]
> The switch plate has an orientation (lower and top part).



Attach the protection acrylic sheets to the spacers with M2 middle screws.

Put the large protection acrylic sheet on top.


### Connecting to the BASE unit
Attach long M2 spacers with M2 short screws to the SIDE unit.

> [!NOTE]
> There should be one spacer on the bottom side of the SIDE unit and two to the top, forming an equilateral triangle.



If this is the first SIDE unit that you have built, remove two sets of 6 pins from the remaining BASE unit pin headers, and insert them in the pin sockets of the SIDE unit.



Place the SIDE unit on the supports and secure it with the M3 screws excessed in base unit.
> [!CAUTION]
> Make sure that the legs of the pin sockets are inside the long through-holes of the BASE unit.



Solder the pin sockets from the back side of the BASE unit.

This is the last soldering step for the SIDE unit.

In case you plan on using the OLED module, insert it in the pin socket.


Attach MX switches to the switch plate, and insert them in the MX sockets, so that the D pad is in the middle.



Confirm that everything is working by connecting the unit to a computer with a USB cable.
> [!NOTE]
> The LEDs will not work until the TOP (and ADD) units are completed.

If the keys and ball are working, proceed with the TOP unit assembly
There are two types of top unit: the one included in the package, and a top unit with wheels sold separately.

4. [TOP Unit](../rightside/4_TOP.md)
   - [TOP Unit with wheel (sold separately)](../rightside/4_TOP_WHEEL.md)

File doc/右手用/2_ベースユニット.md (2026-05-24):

# Killer Whale ベースユニット 右手用ビルドガイド （[左手用](../左手用/2_ベースユニット.md)）

1. [スタートページ](../../README.md)
2. ベースユニットの組み立て（右手用）（このページ）
3. [側面ユニットの組み立て](../右手用/3_側面ユニット_トラックボール.md)
4. [天面ユニットの組み立て](../右手用/4_天面ユニット.md)
5. [追加ユニットの組み立て](../右手用/5_追加ユニット.md)
6. [全体の組み立て](../右手用/6_全体の組み立て.md)
7. [カスタマイズ](../右手用/7_カスタマイズ.md)
8. [その他](../右手用/8_その他.md)

## 内容品

||部品名|数||
|-|-|-|-|
|1|メインボード|1|FR4|
|2|ボトムプレート|1|アクリル|
|3|側面ユニット支柱|4|アクリル|
|4|天面ユニット支柱|4|アクリル|
|5|M2ネジ|12|10mm|
|6|M2ワッシャー|24||
|7|M2スプリングワッシャー|12||
|8|M2ナット|12||
|9|M2スペーサー|12|3mm|
|10|M3ネジ|11|10mm|
|11|M3四角ナット|11||
|12|M2ネジ（黒）|4|8mm|
|13|M2ワッシャー（黒）|8||
|14|M2スプリングワッシャー（黒）|4|
|15|M2ナット（黒）|4|
|16|TRRSジャック|2||
|17|ピンソケット|2||
|18|L字ピンソケット|1||
|19|ピンヘッダ|2||
|20|ジャンパー|6||
|21|ゴム足|4||
|22|MOSFET|1|BSS138|
|23|抵抗|2|10k|
|24|Raspberry Pico（Type-C、互換品）|1||

## はんだ付け
ベースユニットには全ての部品を表に実装します。

### Raspberry Pi Picoのはんだ付け
ピンヘッダを20ピンずつニッパーで切ります。

メインボードに差し込み、Raspberry Pi Picoをのせます。

> [!WARNING]
> 左右でRaspberry Pi Picoの裏表が変わるのでGP0,VBUSの位置を確認して合わせます。  
> ビルドガイドの写真はMicro-USBですがType-C版が同梱されています。




表裏両面をはんだ付けします。

長い方のピンはニッパーで短くします。

### L字ピンソケットのハンダ付け
L字ピンソケットを差し込み裏側ではんだ付けします。


### TRRSジャックのはんだ付け
TRRSジャックを差し込み裏側ではんだ付けします。


### ジャンパーピンの取り付け
ピンヘッダーを3ピンを2つ、4ピンを8つ切り出します。


短い方をホールに差して長い方を表側にします。

3箇所にジャンパーピンを6つ差し込み、どのように組み立てるかを選びます。

それぞれ左右どちらか、追加ユニットを接続するか、側面ユニットの種類がどれかに対応しています。

### （オプション）LED部品のはんだ付け
MOSFETと抵抗を取り付けます。部品が小さいのでピンセットを使いやけどをしないように注意します。
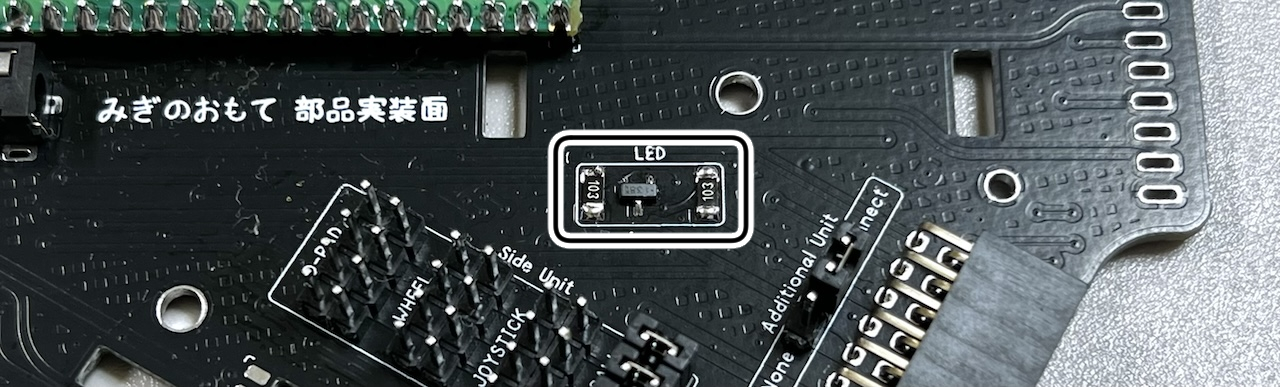
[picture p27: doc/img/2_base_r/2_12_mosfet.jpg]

LEDには向きがあります。  丸い発光面が向こう向きになり、基板の角のマークとLEDの足の切り欠きの方向が一致するようにします。

ベースユニットには3箇所取り付けます。

一度USBケーブルを接続して発光するかチェックします。

## 支柱の取り付け

### 支柱の組み立て
支柱は8パーツ4組あります。

前準備としてM2ネジ12本にワッシャーを通します。

ワッシャーを通したM2ネジを支柱パーツの片側に通し、スペーサーで止めます。
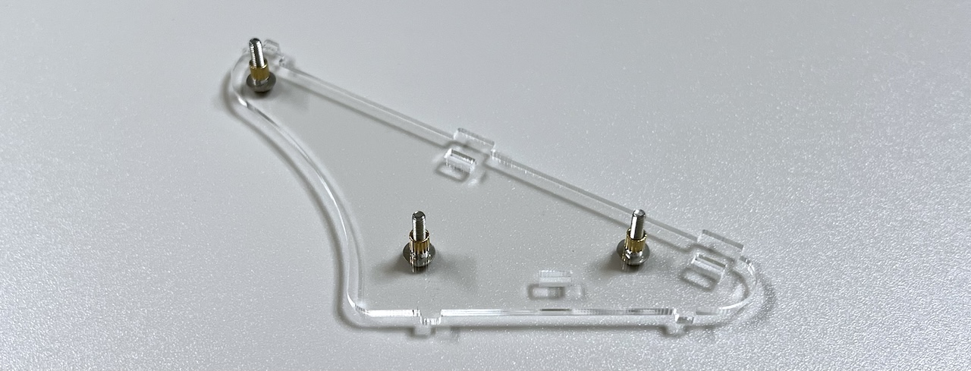
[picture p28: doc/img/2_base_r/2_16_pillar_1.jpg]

スリットに四角ナットを斜めにして立てます。  小さいパーツは2箇所、中くらいのパーツは3箇所、大きいパーツは4箇所スリットがあります。

反対側の支柱パーツをネジに通し、ワッシャー、スプリングワッシャーの順に入れてナットで固定します。

4種類作り終えたところです。


### 支柱の取り付け
表面に支柱を立てて裏面からM3ネジで止めます。
> [!NOTE]
> あとで一度外すので強く締めすぎないようにします。



組み立てる予定の側面ユニットの説明に進みます。
残りの部品はこの後の工程で使うので保管します。

3. 側面ユニットの組み立て
   - [トラックボール](../右手用/3_側面ユニット_トラックボール.md)
   - [十字キー](../右手用/3_側面ユニット_十字キー.md)
   - [（別売）ホイール 縦/横](../右手用/3_側面ユニット_ホイール.md)
   - [（別売）ジョイスティック](../右手用/3_側面ユニット_ジョイスティック.md)

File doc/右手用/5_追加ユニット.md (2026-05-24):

# Killer Whale 追加ユニット 右手用ビルドガイド （[左手用](../左手用/5_追加ユニット.md)）

1. [スタートページ](../../README.md)
2. [ベースユニットの組み立て](../右手用/2_ベースユニット.md)
3. [側面ユニットの組み立て](../右手用/3_側面ユニット_トラックボール.md)
4. [天面ユニットの組み立て](../右手用/4_天面ユニット.md)
5. 追加ユニットの組み立て（右手用）（このページ）
6. [全体の組み立て](../右手用/6_全体の組み立て.md)
7. [カスタマイズ](../右手用/7_カスタマイズ.md)
8. [その他](../右手用/8_その他.md)

## 内容品

||部品名|数||
|-|-|-|-|
|1|メインボード|1|FR4|
|2|スイッチプレート|1|FR4|
|3|ボトムプレート|1|アクリル|
|4|保護プレート|1|アクリル|
|5|M2ネジ（短）|2|4mm|
|6|M2ネジ（中）|2|6mm|
|7|M2ネジ（長）|5|8mm|
|8|M2ワッシャー（黒）|4|
|9|M2スプリングワッシャー（黒）|3|
|10|M2ナット（黒）|3|
|11|M2スペーサー（短）|1|8mm|
|12|M2スペーサー（長）|2|16mm|
|13|トグルスイッチ|1||
|14|L字ピンヘッダ|1||
|15|ホイールエンコーダー|1||
|17|MXスイッチソケット|2||
|18|ダイオード|5||
|19|ゴム足|2||

以下の3Dプリンター製部品も使います。


## はんだ付け
追加ユニットは表裏両方に部品をはんだ付けします。


### （オプション）LEDのはんだ付け（裏側）
追加ユニットには3箇所、すべて裏側にはんだ付けします。

2個は丸い発光面がが向こう向き、間の一つはこちら向きになります。

### ダイオードのはんだ付け（裏側）
裏面から差し、表ではんだ付けして足を切ります。


### MXスイッチソケットのはんだ付け（裏側）
ピンセットで押し付けながらハンダごてに乗せたはんだを流し込みます。


### L字ピンヘッダのはんだ付け（表側）
表面から差し、裏側をはんだ付けします。

> [!WARNING]
> ここまでのはんだ付けと裏表が変わっています。



### ホイールエンコーダーのはんだ付け（表側）
ショートを防ぐためエンコーダーの裾のプレートを少し広げます。

基板の印刷とピンの方向を合わせて裏面ではんだ付けします。


### トグルスイッチのはんだ付け
表から差して裏ではんだ付けします。



追加ユニットのはんだ付けは以上です。

## 組み立て
### アクリルプレートの取り付け
M2ネジ（長）1本にワッシャー（黒）を通します。


追加ユニットの裏にボトムプレートをあててM2スペーサー（短）をM2ネジ（長）で止めます。



その左右にM2ネジ（短）でM2スペーサー（長）を止めます。


ホイールの部品を組み合わせます。細い方の軸は方向に気をつけてください。

少し力が要ることがあります。中くらいの軸はどちらからでも大丈夫です。


ホイールをホイールエンコーダーに差し込み、保護プレートを載せてM2ネジ（中）で固定します。


キースイッチをスイッチプレートに取り付けて、追加ユニットのMXスイッチソケットに差し込みます。


全体の組立てに進みます。

6. [全体の組み立て](../右手用/6_全体の組み立て.md)

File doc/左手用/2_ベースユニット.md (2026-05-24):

# Killer Whale ベースユニット 左手用ビルドガイド （[右手用](../右手用/2_ベースユニット.md)）

1. [スタートページ](../../README.md)
2. ベースユニットの組み立て（左手用）（このページ）
3. [側面ユニットの組み立て](../左手用/3_側面ユニット_トラックボール.md)
4. [天面ユニットの組み立て](../左手用/4_天面ユニット.md)
5. [追加ユニットの組み立て](../左手用/5_追加ユニット.md)
6. [全体の組み立て](../左手用/6_全体の組み立て.md)
7. [カスタマイズ](../左手用/7_カスタマイズ.md)
8. [その他](../左手用/8_その他.md)

## 内容品

||部品名|数||
|-|-|-|-|
|1|メインボード|1|FR4|
|2|ボトムプレート|1|アクリル|
|3|側面ユニット支柱|4|アクリル|
|4|天面ユニット支柱|4|アクリル|
|5|M2ネジ|12|10mm|
|6|M2ワッシャー|24||
|7|M2スプリングワッシャー|12||
|8|M2ナット|12||
|9|M2スペーサー|12|3mm|
|10|M3ネジ|11|10mm|
|11|M3四角ナット|11||
|12|M2ネジ（黒）|4|8mm|
|13|M2ワッシャー（黒）|8||
|14|M2スプリングワッシャー（黒）|4|
|15|M2ナット（黒）|4|
|16|TRRSジャック|2||
|17|ピンソケット|2||
|18|L字ピンソケット|1||
|19|ピンヘッダ|2||
|20|ジャンパー|6||
|21|ゴム足|4||
|22|MOSFET|1|BSS138|
|23|抵抗|2|10k|
|24|Raspberry Pico（Type-C、互換品）|1||

## はんだ付け
ベースユニットには全ての部品を表に実装します。

### Raspberry Pi Picoのはんだ付け
ピンヘッダを20ピンずつニッパーで切ります。

メインボードに差し込み、Raspberry Pi Picoをのせます。
> [!WARNING]
> 左右でRaspberry Pi Picoの裏表が変わるのでGP0,VBUSの位置を確認して合わせます。  
> ビルドガイドの写真はMicro-USBですがType-C版が同梱されています。




表裏両面をはんだ付けします。

長い方のピンはニッパーで短くします。

### L字ピンソケットのハンダ付け
L字ピンソケットを差し込み裏側ではんだ付けします。


### TRRSジャックのはんだ付け
TRRSジャックを差し込み裏側ではんだ付けします。


### ジャンパーピンの取り付け
ピンヘッダーを3ピンを2つ、4ピンを8つ切り出します。


短い方をホールに差して長い方を表側にします。

3箇所にジャンパーピンを6つ差し込み、どのように組み立てるかを選びます。
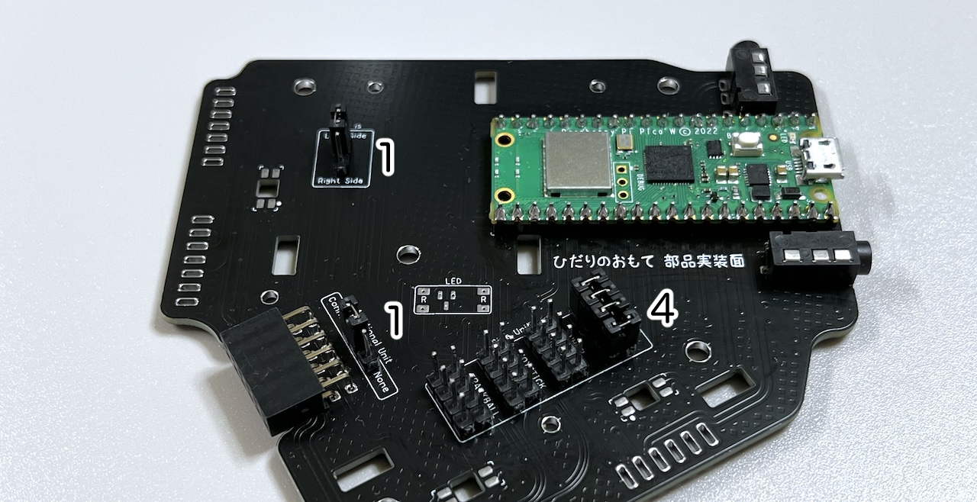
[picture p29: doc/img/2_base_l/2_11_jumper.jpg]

それぞれ左右どちらか、追加ユニットを接続するか、側面ユニットの種類がどれかに対応しています。

### （オプション）LED部品のはんだ付け
MOSFETと抵抗を取り付けます。部品が小さいのでピンセットを使いやけどをしないように注意します。

LEDには向きがあります。  丸い発光面が向こう向きになり、基板の角のマークとLEDの足の切り欠きの方向が一致するようにします。

ベースユニットには3箇所取り付けます。

一度USBケーブルを接続して発光するかチェックします。

## 支柱の取り付け

### 支柱の組み立て
支柱は8パーツ4組あります。

前準備としてM2ネジ12本にワッシャーを通します。

ワッシャーを通したM2ネジを支柱パーツの片側に通し、スペーサーで止めます。

スリットに四角ナットを斜めにして立てます。  小さいパーツは2箇所、中くらいのパーツは3箇所、大きいパーツは4箇所スリットがあります。

反対側の支柱パーツをネジに通し、ワッシャー、スプリングワッシャーの順に入れてナットで固定します。

4種類作り終えたところです。


### 支柱の取り付け
表面に支柱を立てて裏面からM3ネジで止めます。
> [!NOTE]
> あとで一度外すので強く締めすぎないようにします。



組み立てる予定の側面ユニットの説明に進みます。
残りの部品はこの後の工程で使うので保管します。

3. 側面ユニットの組み立て
   - [トラックボール](../左手用/3_側面ユニット_トラックボール.md)
   - [十字キー](../左手用/3_側面ユニット_十字キー.md)
   - [（別売）ホイール 縦/横](../左手用/3_側面ユニット_ホイール.md)
   - [（別売）ジョイスティック](../左手用/3_側面ユニット_ジョイスティック.md)

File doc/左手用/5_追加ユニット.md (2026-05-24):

# Killer Whale 追加ユニット 左手用ビルドガイド （[右手用](../右手用/5_追加ユニット.md)）

1. [スタートページ](../../README.md)
2. [ベースユニットの組み立て](../左手用/2_ベースユニット.md)
3. [側面ユニットの組み立て](../左手用/3_側面ユニット_トラックボール.md)
4. [天面ユニットの組み立て](../左手用/4_天面ユニット.md)
5. 追加ユニットの組み立て（左手用）（このページ）
6. [全体の組み立て](../左手用/6_全体の組み立て.md)
7. [カスタマイズ](../左手用/7_カスタマイズ.md)
8. [その他](../左手用/8_その他.md)

## 内容品

||部品名|数||
|-|-|-|-|
|1|メインボード|1|FR4|
|2|スイッチプレート|1|FR4|
|3|ボトムプレート|1|アクリル|
|4|保護プレート|1|アクリル|
|5|M2ネジ（短）|2|4mm|
|6|M2ネジ（中）|2|6mm|
|7|M2ネジ（長）|5|8mm|
|8|M2ワッシャー（黒）|4|
|9|M2スプリングワッシャー（黒）|3|
|10|M2ナット（黒）|3|
|11|M2スペーサー（短）|1|8mm|
|12|M2スペーサー（長）|2|16mm|
|13|トグルスイッチ|1||
|14|L字ピンヘッダ|1||
|15|ホイールエンコーダー|1||
|17|MXスイッチソケット|2||
|18|ダイオード|5||
|19|ゴム足|2||

以下の3Dプリンター製部品も使います。


## はんだ付け
追加ユニットは表裏両方に部品をはんだ付けします。


### （オプション）LEDのはんだ付け（裏側）
追加ユニットには3箇所、すべて裏側にはんだ付けします。

2個は丸い発光面がが向こう向き、間の一つはこちら向きになります。

### ダイオードのはんだ付け（裏側）
裏面から差し、表ではんだ付けして足を切ります。


### MXスイッチソケットのはんだ付け（裏側）
ピンセットで押し付けながらハンダごてに乗せたはんだを流し込みます。


### L字ピンヘッダのはんだ付け（表側）
表面から差し、裏側をはんだ付けします。

> [!WARNING]
> ここまでのはんだ付けと裏表が変わっています。



### ホイールエンコーダーのはんだ付け（表側）
ショートを防ぐためエンコーダーの裾のプレートを少し広げます。

基板の印刷とピンの方向を合わせて裏面ではんだ付けします。


### トグルスイッチのはんだ付け
表から差して裏ではんだ付けします。



追加ユニットのはんだ付けは以上です。

## 組み立て
### アクリルプレートの取り付け
M2ネジ（長）1本にワッシャー（黒）を通します。


追加ユニットの裏にボトムプレートをあててM2スペーサー（短）をM2ネジ（長）で止めます。



その左右にM2ネジ（短）でM2スペーサー（長）を止めます。


ホイールの部品を組み合わせます。細い方の軸は方向に気をつけてください。

少し力が要ることがあります。中くらいの軸はどちらからでも大丈夫です。


ホイールをホイールエンコーダーに差し込み、保護プレートを載せてM2ネジ（中）で固定します。


キースイッチをスイッチプレートに取り付けて、追加ユニットのMXスイッチソケットに差し込みます。


全体の組立てに進みます。

6. [全体の組み立て](../左手用/6_全体の組み立て.md)

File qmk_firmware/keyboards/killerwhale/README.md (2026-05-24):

# Killer Whale
- Manual: https://github.com/Taro-Hayashi/KillerWhale/blob/main/README.md
- Yushakobo: https://shop.yushakobo.jp/products/7948
  


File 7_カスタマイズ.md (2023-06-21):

## 2台を接続する
#### ※左右間のケーブルを着け外しする前にUSBケーブルを抜いてください

左手用、右手用を一つずつTRSケーブルかTRRSケーブルで繋げると左右分割キーボードとして使用できます。  
ダミーキャプション  
差し込み口は2つありますが、どちらを使用しても大丈夫です。  

##　トラックボールの方向、速度を変える

## キーマップのカスタマイズ
### 通常のキーの割り当て
### ホイールのキーの割り当て

### 特殊なキーの割り当て
#### Mod-Tap

#### Tap-Hold

#### トラックボールの方向、速度を変更するキー

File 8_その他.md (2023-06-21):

## ファームウェアまとめ（最終更新日: 2023/6/22）
完成後にファームウェアを入れ替えたくなった場合はこちらからもダウンロード可能です。  
- 単体使用 左右共用 [tarohayashi_killerwhale_solo_default.uf2
](https://github.com/Taro-Hayashi/KillerWhale/releases/download/0.21.3/tarohayashi_killerwhale_solo_default.uf2)
- 左右分割 左手ボール [tarohayashi_killerwhale_duo_ballleft.uf2
](https://github.com/Taro-Hayashi/KillerWhale/releases/download/0.21.3/tarohayashi_killerwhale_duo_ballleft.uf2)
- 左右分割 右手ボール [tarohayashi_killerwhale_duo_ballright.uf2
](https://github.com/Taro-Hayashi/KillerWhale/releases/download/0.21.3/tarohayashi_killerwhale_duo_ballright.uf2)
- 左右分割 両手ボール [tarohayashi_killerwhale_duo_default.uf2
](https://github.com/Taro-Hayashi/KillerWhale/releases/download/0.21.3/tarohayashi_killerwhale_duo_default.uf2)

## VIA用JSONファイル
- 単体使用向け [killer_whale_solo.json
](https://github.com/Taro-Hayashi/KillerWhale/releases/download/0.21.3/killer_whale_solo.json)
- 左右分割向け [killer_whale_duo.json
](https://github.com/Taro-Hayashi/KillerWhale/releases/download/0.21.3/killer_whale_duo.json)
### ファームウェアのコード（予定地）
- https://github.com/Taro-Hayashi/qmk_firmware/tree/tarohayashi/keyboards/tarohayashi/killerwhale/- 

### Q&A
- 側面/追加ユニットのLEDが光らない
- 側面ユニットのキー以外の機能が動かない
- キーマップが左右逆
  
    ジャンパーの指定が間違っている可能性がありますのでご確認ください。  
  
- ジョイスティックが動かない

    左右分割キーボードとして使う場合、ジョイスティックはUSBケーブルを繋いだ側だけが動作します。  

- カーソルがカクつく

    左右分割向けのファームウェアで片手のみの利用だとカーソルが飛ぶ現象を確認しています。  単体使用向けのファームウェアをダウンロードしてインストールしてください、

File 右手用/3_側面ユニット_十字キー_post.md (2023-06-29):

# Killer Whale 十字キー側面ユニット 右手用ビルドガイド （[左手用](../左手用/3_側面ユニット_十字キー.md)）

1. [スタートページ](../README.md)
2. [ベースユニットの組み立て](../右手用/2_ベースユニット.md)
3. 側面ユニットの組み立て
   - [トラックボール](../右手用/3_側面ユニット_トラックボール.md)
   - 十字キー（右手用）（このページ）
   - [（別売）ホイール 縦/横](../右手用/3_側面ユニット_ホイール.md)
   - [（別売）ジョイスティック](../右手用/3_側面ユニット_ジョイスティック.md)
4. [天面ユニットの組み立て](../右手用/4_天面ユニット.md)
5. [追加ユニットの組み立て](../右手用/5_追加ユニット.md)
6. [全体の組み立て](../右手用/6_全体の組み立て.md)
7. [カスタマイズ](../右手用/7_カスタマイズ.md)
8. [その他](../右手用/8_その他.md)

## 内容品 
    
||部品名|数||
|-|-|-|-|
|1|メインボード|1|FR4|
|2|スイッチプレート|1|FR4|
|3|保護プレート|2|アクリル|
|4|十字キー用プレート|2|アクリル|
|5|M2バインドネジ（短）|5|6mm|
|6|M2ネジ（長）|1|10mm|
|7|M2ワッシャー|1||
|8|M2スプリングワッシャー|1||
|9|M2ナット|1||
|10|M2ネジ（黒）|5|4mm|
|11|M2スペーサー（短）|2|5mm|
|12|M2スペーサー（長）|3|10（銀）or 12mm（茶）|
|13|ピンヘッダ|1||
|14|ダイオード|8|1N4148|
|15|Kailhミュートスイッチ|4|
|16|MXスイッチソケット|2||

メインボード、保護プレートには縦と横で違いがあります。  適宜読み替えてください。  
## はんだ付け
側面ユニットは表裏両方に部品を実装するので気をつけてください。  
  
左右の記載がある方が裏面です。
### （オプション）LEDのはんだ付け
LEDは3個取り付けます。すべてはんだ付けする面から見て丸い発光面が向こう向きです。  
  

### MXスイッチソケットのはんだ付け（裏面）
裏面にピンセットで押し付けながらハンダごてに乗せたはんだを流し込みます。  
  
両側をはんだしてずれなくなったらピンセットからはんだに持ち替えて追加で流し込みしましょう。  表面積が広く多めのはんだが必要です。  
### ダイオードのはんだ付け（裏面）
ダイオードには向きがあります。線と基板のマークの方向を合わせてください。 
 
8箇所に裏からダイオードを差し、マスキングテープで固定します。  
  
表ではんだ付けして足を切ります。  
  

### ピンヘッダーのはんだ付け（裏面）
40ピンヘッダーから6ピンを4本切り出し、裏面にピンヘッダーを立ててはんだ付けします。
長い方を差し込んでください。反対にした場合は短い方と同程度まで切ってください。
  
### （オプション）OLEDモジュールのはんだ付け（表面）
表面にOLED用ソケットをはんだ付けします。  
  
付け外しを考えないのであれば、OLEDモジュールを直接はんだ付けしてしまうのも良いと思います。

OLEDモジュールにはOLED用ピンヘッダをはんだ付けします。  
  
まだ差し込まず別々に保管してください。  
### 十字キーのスイッチのはんだ付け（表面）
表面から差し込んで裏面ではんだ付けします。  
  

## 組み立て
側面ユニットには上下があります。  右手用はOLED用ソケットが下側、左手用は上側です。  
  
### スイッチプレートの組み立て
スイッチプレートにM2スペーサー（短2）をM2ネジ（黒）で取り付けます。  
  
スイッチプレートも上下があるので気をつけてください。  
  
スペーサーに保護プレート2種を、M2バインドネジで取り付けます。 
  
付属のスペーサーが銀色の場合は穴が空いている大きい方が下で、スペ
  

### ベースユニットへの取り付け
側面ユニットにM2スペーサー（長）をM2ネジ（黒）で取り付けます。  
  
下側はスペーサーが一本、上側に2本で正三角形を作るように立てます。  
   
初めて側面ユニットを作る場合、ベースユニットで余ったピンソケットから6ピンを2つ切り出して側面ユニットのピンソケットに差し込みます。
  
ベースユニットのM3ネジ２本にワッシャーを通します。  
   
支柱に側面ユニットを差し込み、M3ネジで止めます。  ベースユニットの縦長のスルーホールにピンソケットの足が入るようにしてください。  
ダミーキャプション  
ベースユニットの裏面でピンソケットをはんだ付けします。  多めにはんだを流して表面までしっかりはんだ付けされるようにしてください。  
  
これで側面ユニットのはんだ付けは終わりです。  

OLEDモジュールを使う場合はここでピンソケットに差し込みます。  
  

十字キー用プレートをM2ネジ（長）とワッシャー、スプリングワッシャー、ナットで固定します。  
  

十字キーを挟み込むようにして、スイッチプレートにキースイッチを取り付けてMXソケットに差し込みます。  
  
保護プレートをM2バインドネジで固定したら完成です。  
 
USBケーブルを差し動作確認してみましょう。  LEDは天面ユニットを取り付けるまで光りません。  
問題がなくキーが反応したら天面ユニットの組み立てに進んでください。  

同梱されているものと、別売のホイール付きの2種類があります。  
  
4. [天面ユニットの組み立て](../右手用/4_天面ユニット.md)
   - [（別売）ホイール付き天面ユニット](../右手用/4_ホイール付き天面ユニット.md)

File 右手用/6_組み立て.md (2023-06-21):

# Killer Whal　組み立て 右手用ビルドガイド （[左手用](../左手用/6_組み立て.md)）

1. [スタートページ](../README.md)
2. [ベースユニットの組み立て](../右手用/2_ベースユニット.md)
3. [追加ユニットの組み立て](../右手用/3_追加ユニット.md)
4. [側面ユニットの組み立て](../右手用/4_側面ユニット_トラックボール.md)
5. 天面ユニットの組み立て（右手用）（このページ）
   - [（別売予定）ホイール付き天面ユニットの組み立て](../右手用/5_ホイール付き天面ユニット.md)
6. [カスタマイズ](../右手用/7_カスタマイズ.md)
7. [その他](../右手用/8_その他.md)

##　組み立て
### ボトムプレートの取り付け
底面のM3ネジをはずして天面ユニットを一度外します。  
同様に側面ユニットも取り外します。  
ダミーキャプション  

表面でピンソケットのはんだ付けを少し盛ります。  
ダミーキャプション  

ねじ（黒）4本にワッシャー（黒）を通します。  
ダミーキャプション  
ベースユニットにボトムプレートをあてて、裏面からネジを差し込みます。  
ダミーキャプション  
表面にワッシャー、スプリングワッシャーの順に通し、ナットで締めます。  
ダミーキャプション  
ゴム足を4つ貼りました。  

### 追加ユニットの取り付け
M2ねじ（黒）（長）にワッシャー（黒）を通します。  
ダミーキャプション  
画像のようにスライドさせてL字ピンヘッダをL字ピンソケットに差し込みます。  
ダミーキャプション 矢印あり  
アクリルとFR4のプレートがうまく噛み合うはずなので無理に力を加えないようにします。  
3箇所のネジ穴にM2ねじ（黒）（長）を通してワッシャー黒、スプリングワッシャー黒、ナットの順で止めます。  
ダミーキャプション 矢印あり  
ゴム足を貼りました。  
ダミーキャプション ベース、  
USBを繋いで動作を確認します。  LEDは天面ユニットを取り付けるまで光りません。  ホイールのスクロール方向は後から変更できます。  

### 天面ユニットの取り付け
スイッチプレートの四角にキースイッチを取り付けてMXソケットに差し込みます。  
ダミーキャプション  
全てのスイッチを取り付けたらキーキャップを取り付けて完成です。  
ダミーキャプション  
お疲れ様でした。  

USBケーブルを差し動作確認してみましょう。  標準では以下のようなキーマップになっています。  
ダミーキャプション  

ゴム足を貼りました。  
ダミーキャプション ベース、

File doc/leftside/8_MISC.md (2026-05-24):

# Killer Whale Misc

1. [First Page](../README_EN.md)
2. [BASE Unit](../leftside/2_BASE.md)
3. [SIDE Unit](../leftside/3_SIDE_TRACKBALL.md)
4. [TOP Unit](../leftside/4_TOP.md)
5. [ADD Unit](../leftside/5_ADD.md)
6. [Assemble](../leftside/6_ASSEMBLE.md)
7. [Customize](../leftside/7_CUSTOM.md)
8. Misc

## Firmware

- SOLO [tarohayashi_killerwhale_solo_via.uf2
](https://github.com/Taro-Hayashi/KillerWhale/releases/latest/download/tarohayashi_killerwhale_solo_via.uf2)
- DUO [tarohayashi_killerwhale_duo_ballleft.uf2
](https://github.com/Taro-Hayashi/KillerWhale/releases/latest/download/tarohayashi_killerwhale_duo_via.uf2)

- SOLO for testing [tarohayashi_killerwhale_solo_default.uf2
](https://github.com/Taro-Hayashi/KillerWhale/releases/latest/download/tarohayashi_killerwhale_solo_default.uf2)
- DUO for testing [tarohayashi_killerwhale_duo_default.uf2
](https://github.com/Taro-Hayashi/KillerWhale/releases/latest/download/tarohayashi_killerwhale_duo_default.uf2)

## Special Keys
|Key name on remap|Function|
|-|-|
|CMD / CTL|Control key for Windows, Command key for Apple products|
|Undo|Ctrl/Cmd + Z|
|Redo|Shift + Ctrl/Cmd + Z|
|Copy|Ctrl/Cmd + C|
|Cut|Ctrl/Cmd + X|
|Paste|Ctrl/Cmd + V|
|Scale Up|Ctrl/Cmd + +|
|Scale Down|Ctrl/Cmd + -|
|Scale Reset|Ctrl/Cmd + 0|
|Captcha|Shift + Win + S / Shift + Cmd + 4|
|Save|Ctrl/Cmd + S|
|Save As|Shift + Ctrl/Cmd + S|
|Next Tab|Ctrl + Tab|
|Prev Tab|Shift + Ctrl + Tab|
|Close Tab|Ctrl/Cmd + W|
|Restore Tab|Shift + Ctrl/Cmd + T|
|Speed + Left|Increase speed and sensitivity on the left hand side|
|Speed - Left|Decrease speed and sensitivity on the left hand side|
|Speed + Right|Increase speed and sensitivity on the right hand side|
|Speed - Right|Decrease speed and sensitivity on the right hand side|
|Angle + Left|Increase angle on the left hand side|
|Angle - Left|Decrease angle on the left hand side|
|Invert X Left|Invert one axis on the left hand side|
|Mode Change Left|Change input mode on the left hand side|
|Angle + Right|Increase angle on the right hand side|
|Angle - Right|Decrease angle on the right hand side|
|Invert X Right|Invert one axis on the right hand side|
|Mode Change Right|Change input mode on the right hand side|
|Invert Scroll|Invert Scroll Direction|
|Scroll Mode|Scrolling with trackball/joystick only as long as it is pressed|
|Toggle Auto Mouse|Toggle auto mouse function|
|OLED Mode|Switching OLED display content|
|USER 0|ESC when tapped, scroll when hold|
|USER 1|Tab when tapped, scroll when hold|
|USER 2|lang1 when tapped, scroll when hold|
|USER 3|lang2 when tapped, scroll when hold|
|USER 4|Slowdown trackball/joystick only as long as it is pressed|
|USER 5|ESC when tapped, slowdown trackball/joystick when hold|
|USER 6|Tab when tapped, slowdown trackball/joystick when hold|
|USER 7|lang1 when tapped, slowdown trackball/joystick when hold|
|USER 8|lang2 when tapped, slowdown trackball/joystick when hold|
|USER 9|Left click when tapped, slowdown trackball/joystick when hold|
|USER 10|Right click when tapped, slowdown trackball/joystick when hold|
|USER 11|Center click when tapped, slowdown trackball/joystick when hold|
|USER 12|Trackball/joystick moves cursor only as long as it is pressed|
|USER 13|Trackball/joystick input keys only as long as it is pressed|
|USER 14|Exclude diagonal input on D-Pad and input key mode|
|USER 15|Toggle RGB layer function|
|USER 16|Reset joystick calibration|
|USER 17|Key to Input Gamepad Up|
|USER 18|Key to Input Gamepad Down|
|USER 19|Key to Input Gamepad Left|
|USER 20|Key to Input Gamepad Right|
|USER 21|Game mode when hold|
|USER 22|Reduce range to ignore small values (default: 50)||
|USER 23|Expand range to ignore small values (max: 200)|
|USER 24|Reduce range to ignore large values (default: 0)|
|USER 25|Expand range to ignore large values (max: 200)|

## Firmware Codes
- [qmk_firmware](../../qmk_firmware/keyboards/killerwhale)

## Acrylic and switch plates
- https://github.com/Taro-Hayashi/KillerWhale/releases/download/0.27.1/killer_whale_plates.zip

## Sales
- Yushakobo https://shop.yushakobo.jp/en/products/7948
- BOOTH https://tarohayashi.booth.pm/items/5771739

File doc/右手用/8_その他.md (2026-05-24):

# Killer Whale その他 右手用ビルドガイド （[左手用](../左手用/8_その他.md)）

1. [スタートページ](../../README.md)
2. [ベースユニットの組み立て](../右手用/2_ベースユニット.md)
3. [側面ユニットの組み立て](../右手用/3_側面ユニット_トラックボール.md)
4. [天面ユニットの組み立て](../右手用/4_天面ユニット.md)
5. [追加ユニットの組み立て](../右手用/5_追加ユニット.md)
6. [全体の組み立て](../右手用/6_全体の組み立て.md)
7. [カスタマイズ](../右手用/7_カスタマイズ.md)
8. その他（このページ）

## ファームウェアまとめ
- 単体テスト用 [tarohayashi_killerwhale_solo_test.uf2
](https://github.com/Taro-Hayashi/KillerWhale/releases/latest/download/tarohayashi_killerwhale_solo_test.uf2)
- 単体用 [tarohayashi_killerwhale_solo_default.uf2
](https://github.com/Taro-Hayashi/KillerWhale/releases/latest/download/tarohayashi_killerwhale_solo_default.uf2)
- 左右分割テスト用 [tarohayashi_killerwhale_duo_test.uf2
](https://github.com/Taro-Hayashi/KillerWhale/releases/latest/download/tarohayashi_killerwhale_duo_test.uf2)
- 左右分割用 [tarohayashi_killerwhale_duo_default.uf2
](https://github.com/Taro-Hayashi/KillerWhale/releases/latest/download/tarohayashi_killerwhale_duo_default.uf2)

## 特別なキー一覧
### ショートカット
|Remap|||
|-|-|-|
|CMD / CTL|CMD_CTL|WindowsではControlキー、Apple製品ではCommandキー|
|Undo|UNDO|Ctrl/Cmd + Z|
|Redo|REDO|Shift + Ctrl/Cmd + Z|
|Copy|COPY|Ctrl/Cmd + C|
|Cut|CUT|Ctrl/Cmd + X|
|Paste|PASTE|Ctrl/Cmd + V|
|Scale Up|SC_UP|Ctrl/Cmd + +|
|Scale Down|SC_DOWN|Ctrl/Cmd + -|
|Scale Reset|SC_RESET|Ctrl/Cmd + 0|
|Captcha|CAPTCHA|Shift + Win + S / Shift + Cmd + 4|
|Save|SAVE|Ctrl/Cmd + S|
|Save As|SAVEAS|Shift + Ctrl/Cmd + S|
|Next Tab|NEXTTAB|Ctrl + Tab|
|Prev Tab|PREVTAB|Shift + Ctrl + Tab|
|Close Tab|CLOSETAB|Ctrl/Cmd + W|
|Restore Tab|RSTRTAB|Shift + Ctrl/Cmd + T|

### 設定キー
|Remap|||
|-|-|-|
|Speed + Left|L_SPD_I|左手側の速度、感度を上げる|
|Speed - Left|L_SPD_D|左手側の速度、感度を下げる|
|Speed + Right|R_SPD_I|右手側の速度、感度を上げる|
|Speed - Right|R_SPD_D|右手側の速度、感度を下げる|
|Angle + Left|L_ANG_I|左手側の角度を増やす|
|Angle - Left|L_ANG_D|左手側の角度を減らす|
|Invert X Left|L_INV|左手側の軸を片方反転させる|
|Mode Change Left|L_CHMOD|左手側の入力モードを変える|
|Angle + Right|R_ANG_I|右手側の角度を増やす|
|Angle - Right|R_ANG_D|右手側の角度を減らす|
|Invert X Right|R_INV|右手側の軸を片方反転させる|
|Mode Change Right|R_CHMOD|右手側の入力モードを変える|
|Invert Scroll|INV_SCRL|スクロール方向を反転する|
|Scroll Mode|MOD_SCRL|押している間だけトラックボール/ジョイスティックでスクロールできる|
|Toggle Auto Mouse|AUTO_MOUSE|オートマウス機能の切り替え|
|OLED Mode|OLED_MOD|OLEDの機能の切り替え|
|USER 0|QK_USER_0|短押しでESC、押している間スクロールモード|
|USER 1|QK_USER_1|短押しでTab、押している間スクロールモード|
|USER 2|QK_USER_2|短押しでかな、押している間スクロールモード|
|USER 3|QK_USER_3|短押しで英数、押している間スクロールモード|
|USER 4|QK_USER_4|押している間だけ減速モード|
|USER 5|QK_USER_5|短押しでESC、押している間減速モード|
|USER 6|QK_USER_6|短押しでTab、押している間減速モード|
|USER 7|QK_USER_7|短押しでかな、押している間減速モード|
|USER 8|QK_USER_8|短押しで英数、押している間減速モード|
|USER 9|QK_USER_9|短押しで左クリック、押している間減速モード|
|USER 10|QK_USER_10|短押しで右クリック、押している間減速モード|
|USER 11|QK_USER_11|短押しで中クリック、押している間減速モード|
|USER 12|QK_USER_12|押している間だけカーソル移動モード|
|USER 13|QK_USER_13|押している間だけ十字キー入力モード|
|USER 14|QK_USER_14|斜め入力防止のオンオフ|
|USER 15|QK_USER_15|RGBレイヤー機能のオンオフ|
|USER 16|QK_USER_16|ジョイスティックのキャリブレーションをリセット|
|USER 17|QK_USER_17|キーでゲームパッドの上を入力|
|USER 18|QK_USER_18|キーでゲームパッドの下を入力|
|USER 19|QK_USER_19|キーでゲームパッドの左を入力|
|USER 20|QK_USER_20|キーでゲームパッドの右を入力|
|USER 21|QK_USER_21|押している間だけゲームモード|
|USER 22|QK_USER_22|小さい値を無視する範囲を縮小（初期設定：50）|
|USER 23|QK_USER_23|小さい値を無視する範囲を拡大（最大値：200）|
|USER 24|QK_USER_24|大きい値を無視する範囲を縮小（ゲームモードのみ）（初期設定：0）|
|USER 25|QK_USER_25|大きい値を無視する範囲を拡大（ゲームモードのみ）（最大値：200）|

### ファームウェアのコード
- [qmk_firmware](../../qmk_firmware/keyboards/killerwhale)

### アクリルプレートとスイッチプレートのデータ
- https://github.com/Taro-Hayashi/KillerWhale/releases/download/0.27.1/killer_whale_plates.zip

### 保守部品の入手先
|部品名|入手先|
|-|-|
|ネジ、ワッシャー、ナット類|ホームセンター等|
|ゴム足|100円ショップ等|
|スペーサー|[札幌貿易](https://item.rakuten.co.jp/sapporo-boueki/c/0000000681/)|
|TRRSジャック|[秋月電子通商](https://akizukidenshi.com/catalog/g/gC-06070/)|
|ピンヘッダ|[秋月電子通商](https://akizukidenshi.com/catalog/g/gC-00167/)|
|ピンソケット|[秋月電子通商](https://akizukidenshi.com/catalog/g/gC-03138/)|
|L字ピンソケット|[秋月電子通商](https://akizukidenshi.com/catalog/g/gC-16795/)|
|L字ピンヘッダ|[秋月電子通商](https://akizukidenshi.com/catalog/g/gC-16794/)|
|ジャンパー|[秋月電子通商](https://akizukidenshi.com/catalog/g/gP-03687/)|
|ダイオード|[秋月電子通商](https://akizukidenshi.com/catalog/g/gI-00941/)|
|コンデンサーC1,C2|[秋月電子通商](https://akizukidenshi.com/catalog/g/gP-08155/)|
|コンデンサーC3|[秋月電子通商](https://akizukidenshi.com/catalog/g/gP-08154/)|
|レギュレーター|[秋月電子通商](https://akizukidenshi.com/catalog/g/gI-10491/)|
|トグルスイッチ|[秋月電子通商](https://akizukidenshi.com/catalog/g/gP-02399/)|
|ジョイスティック|[秋月電子通商](https://akizukidenshi.com/catalog/g/gP-15951/)|
|MOSFET|[秋月電子通商](https://akizukidenshi.com/catalog/g/gI-04232/)|
|抵抗R|[秋月電子通商](https://akizukidenshi.com/catalog/g/gR-11802/)|
|MXスイッチソケット|[遊舎工房](https://shop.yushakobo.jp/products/4291)|
|ホイールエンコーダー|[Amazon](https://www.amazon.co.jp/s?k=ホイールエンコーダー+11mm)|
|ベアリング|[モノタロウ](https://www.monotaro.com/s/?c=&q=Mr62zz)|

※書かれていないものはAli Expressで探すか、余らせていることがあるのでご連絡ください。

## Q&A
- 側面/追加ユニットのLEDが光らない
  - LEDは組み立て終わった状態で初めてすべて発光します。完成後に側面ユニットのみ発光しない場合はジャンパーの指定が間違っている可能性があります。
- 天面ユニットで3か所だけLEDの色が違う
  - RGBレイヤーありのファームウェアを使うとCapsLock、NumLock、ScrollLockやレイヤーの切り替えで発光パターンが変わります。
- 天面ユニットのLEDが一部しか発光しない。
   - LEDのはんだ付けが足りない可能性があります。光るLEDも含めて見直してみてください。
- 側面ユニットのキー以外の機能が動かない
- 分割キーボードでキーマップが左右逆
  - ジャンパーの指定が間違っている可能性があります。
- 分割キーボードでUSBを繋げない側が動かない
   - Raspberry Pi Picoの左右通信用のピンが壊れている可能性があります。
     こちらのテスト用ファームウェアを導入して画像の青どうし、黄色どうしをピンセット等で繋いでみて、"A"と入力されたら正常に動作しています。入力されなかった場合は故障していますので交換していただくか、左右別々にUSBに繋いでご利用いただくこともできます。
      - [tarohayashi_killerwhale_trrstest_test.uf2](https://github.com/Taro-Hayashi/KillerWhale/releases/download/0.23.0/tarohayashi_killerwhale_trrstest_default.uf2)
        
- ジョイスティックが動かない
  - 左右分割キーボードとして使う場合、ジョイスティックはUSBケーブルを繋いだ側だけが動作します。
- カーソルがカクつく
  - 左右分割向けのファームウェアで片手のみの利用だとカーソルが飛ぶ現象を確認しています。  単体使用向けのファームウェアをダウンロードしてインストールしてください。
- ファームウェアを入れ替えたらキーマップがおかしくなった
  - 前のファームウェアのキーマップが保存されている可能性があります。保存したキーマップやサンプルのキーマップを読み込んでください。
- 各種キーが効かない
- 設定が保存されない
- 発光パターンがおかしい
   - こちらのページの一番下の flash_nuke.uf2 を使うとRaspberry Pi Picoをリセットできるのでお試しください。
      - https://www.raspberrypi.com/documentation/microcontrollers/raspberry-pi-pico.html

## 販売サイト
- 遊舎工房 https://shop.yushakobo.jp/en/products/7948
- BOOTH https://tarohayashi.booth.pm/items/5771739

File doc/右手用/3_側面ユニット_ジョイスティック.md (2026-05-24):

# Killer Whale ジョイスティック側面ユニット 右手用ビルドガイド （[左手用](../左手用/3_側面ユニット_ジョイスティック.md)）

1. [スタートページ](../../README.md)
2. [ベースユニットの組み立て](../右手用/2_ベースユニット.md)
3. 側面ユニットの組み立て
   - [トラックボール](../右手用/3_側面ユニット_トラックボール.md)
   - [十字キー](../右手用/3_側面ユニット_十字キー.md)
   - [（別売）ホイール 縦/横](../右手用/3_側面ユニット_ホイール.md)
   - （別売）ジョイスティック（右手用）（このページ）
4. [天面ユニットの組み立て](../右手用/4_天面ユニット.md)
5. [追加ユニットの組み立て](../右手用/5_追加ユニット.md)
6. [全体の組み立て](../右手用/6_全体の組み立て.md)
7. [カスタマイズ](../右手用/7_カスタマイズ.md)
8. [その他](../右手用/8_その他.md)

## ご注意
左右分割キーボードとして使用する時、ジョイスティックはUSBを接続している側のみ動作します。
## 内容品

||部品名|数||
|-|-|-|-|
|1|メインボード|1|FR4|
|2|スイッチプレート|1|FR4|
|3|保護プレート|2|アクリル|
|4|M2ネジ（短）|5|4mm|
|5|M2ネジ（中）|5|6mm|
|6|M2スペーサー（短）|2|9mm|
|7|M2スペーサー（長）|3|16mm|
|8|ダイオード|5|1N4148|
|9|MXスイッチソケット|2||
|10|ジョイスティック|1||
|11|キャップ|1||
|12|ピンヘッダ|1||

### キット以外に必要なもの
|部品名|数||
|-|-|-|
|[キースイッチ](https://shop.yushakobo.jp/collections/all-switches)|2|Cherry MX互換|
|[キーキャップ](https://shop.yushakobo.jp/collections/keycaps)|2|Cherry MX互換|
|幅1cm以下の棒やすり||処理済みで必要ないことがあります|

### オプション
<table>
    <tr>
      <td><a href="https://shop.yushakobo.jp/products/oled">OLEDモジュール</a></td>
      <td>1</td>
    </tr>
    <tr>
      <td>ピンソケット4ピン</a></td>
      <td>1</td>
    </tr>
    <tr>
      <td><a href="https://shop.yushakobo.jp/products/sk6812mini-e-10">LED（SK6812MINI-E)</a></td>
      <td>3</td>
    </tr>
 </table>

## はんだ付け
側面ユニットは表裏両方に部品をはんだ付けします。

左右の記載がある方が裏面です。
### （オプション）LEDのはんだ付け
LEDは3個取り付けます。すべてはんだ付けする面から見て丸い発光面が向こう向きです。

### MXスイッチソケットのはんだ付け（裏面）
裏面にピンセットで押し付けながらハンダごてに乗せたはんだを流し込みます。


### ダイオードのはんだ付け（裏面）
ダイオードには向きがあります。線とメインボードのマークの方向を合わせます。

4箇所に裏からダイオードを差し、表ではんだ付けして足を切ります。


### ピンヘッダーのはんだ付け（裏面）
40ピンヘッダーから6ピンを4本切り出します。


裏面から差し込み、表面ではんだ付けして足を切ります。
> [!WARNING]
> 長い方を差し込みます。反対にした場合は短い方と同程度まで切ります。



### （オプション）OLEDモジュールのはんだ付け（表面）
OLEDモジュールを着脱可能にする場合は表面に4ピンソケットをはんだ付けします。


OLEDモジュールにはOLED用ピンヘッダをはんだ付けします。

直接はんだ付けする場合はここでメインボードにはんだ付けします。
### ジョイスティックのはんだ付け（表面）
表から差し込んで裏ではんだ付けします。


## 仮組みとソケットのはんだ付け
### スイッチプレートの組み立て

スイッチプレートにタグが付いている場合は折ってからやすりで削ります。



スイッチプレートにM2スペーサー（短）をM2ネジ（短）で取り付けます。
> [!NOTE]
> スイッチプレートには上下があります。



スペーサーに保護プレート2種をM2ネジ（中）で取り付けます。

大きい方を上にします。

### ベースユニットへの取り付け
側面ユニットにM2スペーサー（長）をM2ネジ（短）で取り付けます。

> [!NOTE]
> 下側に一つ、上側に2つ付け正三角形にします。



初めて側面ユニットを作る場合、ベースユニットで余ったピンソケットから6ピンを2つ切り出して側面ユニットのピンソケットに差し込みます。


支柱に側面ユニットを差し込み、ベースユニットのM3ネジで止めます。
> [!CAUTION]
> ベースユニットの縦長のスルーホールにピンソケットの足が入るようにします。


ベースユニットの裏面でピンソケットをはんだ付けします。

これで側面ユニットのはんだ付けは終わりです。

OLEDモジュールを使う場合はここでピンソケットに差し込みます。


ジョイスティックにキャップをはめて、スイッチプレートにキースイッチを取り付けてMXソケットに差し込みます。

保護プレートをM2ネジ（中）で固定します。

USBケーブルを差し動作を確認します。
> [!NOTE]
> 側面ユニットのLEDは天面ユニット（と追加ユニット）を取り付けるまで光りません。

## ゲームパッドのアナログスティックとしての利用について
ジョイスティック側面ユニットを使っている場合、従来の3つのモード（カーソル移動、スクロール、キー入力）に加えてゲームモードに切り替えガできます。

DirectInputのコントローラーとして認識されるのでXInputへの対応のゲームではXbox 360 Controller Emulator等をお使いください。

ゲームモードでもスティックが認識される角度の変更をすることができます。回転とX軸の反転を組み合わせて好みの方向に変えてください。また、スティックが反応する傾きの範囲も変更できるので感度や斜め入力のしやすさもある程度調整できます。

ゲームモードでのジョイスティックは自動でキャリブレーションを行っています。USBケーブルの接続後は大きく一周回すとすぐに正確な方向が入力できるようになります。

問題がなければ天面ユニットの組み立てに進みます。
同梱されているものと、別売のホイール付きの2種類があります。

4. [天面ユニットの組み立て](../右手用/4_天面ユニット.md)
   - [（別売）ホイール付き天面ユニット](../右手用/4_ホイール付き天面ユニット.md)

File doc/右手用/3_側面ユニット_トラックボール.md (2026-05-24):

# Killer Whale トラックボール側面ユニット 右手用ビルドガイド （[左手用](../左手用/3_側面ユニット_トラックボール.md)）

1. [スタートページ](../../README.md)
2. [ベースユニットの組み立て](../右手用/2_ベースユニット.md)
3. 側面ユニットの組み立て
   - トラックボール（右手用）（このページ）
   - [十字キー](../右手用/3_側面ユニット_十字キー.md)
   - [（別売）ホイール 縦/横](../右手用/3_側面ユニット_ホイール.md)
   - [（別売）ジョイスティック](../右手用/3_側面ユニット_ジョイスティック.md)
4. [天面ユニットの組み立て](../右手用/4_天面ユニット.md)
5. [追加ユニットの組み立て](../右手用/5_追加ユニット.md)
6. [全体の組み立て](../右手用/6_全体の組み立て.md)
7. [カスタマイズ](../右手用/7_カスタマイズ.md)
8. [その他](../右手用/8_その他.md)

## 内容品

||部品名|数||
|-|-|-|-|
|1|メインボード|1|FR4|
|2|スイッチプレート|1|FR4|
|3|保護プレート|1|アクリル|
|4|M2ネジ（短）|2|4mm|
|5|M2ネジ（中）|2|6mm|
|6|M2ネジ（長）|3|10mm|
|7|M3ネジ|3|10mm|
|8|M2ナット|3|
|9|M3四角ナット|3||
|10|M2スペーサー（長）|2|7mm or 8mm|
|11|ベアリング|3|2x6x2.5|
|12|コンデンサーC3|1|4.7uF|
|13|コンデンサーC1,C2|2|10uF|
|14|レギュレーター|1|UT7500L-18|
|15|MXスイッチソケット|2||
|16|ダイオード|4|1N4148|
|17|センサーとレンズ|1|PMW3360DM-T2QU / LM19-LSI|
|18|ピンヘッダ|1||

以下の3Dプリンター製部品も使います。


## はんだ付け
側面ユニットは表裏両方に部品をはんだ付けします。


左右の記載がある方が裏面です。
### （オプション）LEDのはんだ付け
LEDは3個取り付けます。すべてはんだ付けする面から見て丸い発光面が向こう向きです。


### MXスイッチソケットのはんだ付け（裏面）
裏面にピンセットで押し付けながらハンダごてに乗せたはんだを流し込みます。


### ダイオードのはんだ付け（裏面）
ダイオードには向きがあります。線とメインボードのマークの方向を合わせます。

4箇所に裏からダイオードを差し、表ではんだ付けして足を切ります。


### センサー類のはんだ付け（裏面）
裏面でメインボードの丸マークとチップの丸の位置を合わせて表面ではんだ付けします。
> [!NOTE]
> センサーのシールはまだ剥がさない方が安全です。



コンデンサーをはんだ付けします。106と書いてあるのがC1,C2で475がC3です。



レギュレーターを裏面から差し、メインボードの印刷どおり平面が下になるように折り曲げてはんだ付けします。


### ピンヘッダーのはんだ付け（裏面）
40ピンヘッダーから6ピンを4本切り出します。


裏面から差し込み、表面ではんだ付けして足を切ります。
> [!WARNING]
> 長い方を差し込みます。反対にした場合は短い方と同程度まで切ります。



### （オプション）OLEDモジュールのはんだ付け（表面）
OLEDモジュールを着脱可能にする場合は表面に4ピンソケットをはんだ付けします。


OLEDモジュールにはOLED用ピンヘッダをはんだ付けします。

直接はんだ付けする場合はここでメインボードにはんだ付けします。

## 仮組みとソケットのはんだ付け
### スイッチプレートの組み立て
スイッチプレートにタグが付いている場合は折ってからやすりで削ります。


スイッチプレートにM2スペーサー（長）をM2ネジ（短）で取り付けます。
> [!NOTE]
> スイッチプレートには上下があります。



スペーサーに保護プレートを、M2ネジ（中）で取り付けます。


### トラックボールケースの取り付け
センサーの保護フィルムをはがし、レンズを取り付けます。
> [!IMPORTANT]
> レンズには取り付け方向があります。



裏面に出ているレンズの足をはんだごてで熱して固定します。


ボールケース支柱の3箇所にベアリングを3本のネジと3個のナットで固定します。


ボールケース支柱を立て、スリットにM3角ナットを当てたら裏面からM3ネジで止めます。
> [!NOTE]
> 下側は支柱が一本、上側に2本で正三角形を作るように立てます。



### ベースユニットへの取り付け
初めて側面ユニットを作る場合、ベースユニットのピンソケットから6ピンを2つ切り出して側面ユニットのピンソケットに差し込みます。


支柱に側面ユニットを差し込み、ベースユニットのM3ネジで止めます。
> [!CAUTION]
> ベースユニットの縦長のスルーホールにピンソケットの足が入るようにします。


ベースユニットの裏面でピンソケットをはんだ付けします。

これで側面ユニットのはんだ付けは終わりです。

OLEDモジュールを使う場合はここでピンソケットに差し込みます。


スイッチプレートにキースイッチを取り付けてMXソケットに差し込み、カバーを取り付けます。


USBケーブルを差し動作を確認します。


> [!NOTE]
> 側面ユニットのLEDは天面ユニット（と追加ユニット）を取り付けるまで光りません。
> カーソルの方向や速度は後で調節できます。

問題がなければ天面ユニットの組み立てに進みます。
同梱されているものと、別売のホイール付きの2種類があります。

4. [天面ユニットの組み立て](../右手用/4_天面ユニット.md)
   - [（別売）ホイール付き天面ユニット](../右手用/4_ホイール付き天面ユニット.md)

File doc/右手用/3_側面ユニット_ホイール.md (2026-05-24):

# Killer Whale ホイール側面ユニット 縦/横 右手用ビルドガイド （[左手用](../左手用/3_側面ユニット_ホイール.md)）

1. [スタートページ](../../README.md)
2. [ベースユニットの組み立て](../右手用/2_ベースユニット.md)
3. 側面ユニットの組み立て
   - [トラックボール](../右手用/3_側面ユニット_トラックボール.md)
   - [十字キー](../右手用/3_側面ユニット_十字キー.md)
   - （別売）ホイール 縦/横（右手用）（このページ）
   - [（別売）ジョイスティック](../右手用/3_側面ユニット_ジョイスティック.md)
4. [天面ユニットの組み立て](../右手用/4_天面ユニット.md)
5. [追加ユニットの組み立て](../右手用/5_追加ユニット.md)
6. [全体の組み立て](../右手用/6_全体の組み立て.md)
7. [カスタマイズ](../右手用/7_カスタマイズ.md)
8. [その他](../右手用/8_その他.md)

## 内容品

||部品名|数||
|-|-|-|-|
|1|メインボード|1|FR4|
|2|スイッチプレート|1|FR4|
|3|保護プレート|2|アクリル|
|4|M2ネジ（短）|5|4mm|
|5|M2ネジ（中）|4|6mm|
|6|M2スペーサー（短1）|1|8mm|
|6|M2スペーサー（短2）|2|9mm|
|7|M2スペーサー（長）|2|16mm|
|8|MXスイッチソケット|2||
|9|ホイールエンコーダー|1||
|11|ダイオード|4|1N4148|
|12|ピンヘッダ|1||

以下の3Dプリンター製部品も使います。


※ホイールの縦と横でメインボード、保護プレートの違いがありますが大きく違いはありませんので適宜読み替えてください。

### キット以外に必要なもの
|部品名|数||
|-|-|-|
|[キースイッチ](https://shop.yushakobo.jp/collections/all-switches)|2|Cherry MX互換|
|[キーキャップ](https://shop.yushakobo.jp/collections/keycaps)|2|Cherry MX互換|
|幅1cm以下の棒やすり||整形済みで必要ないことがあります|

### オプション
<table>
    <tr>
      <td><a href="https://shop.yushakobo.jp/products/oled">OLEDモジュール</a></td>
      <td>1</td>
    </tr>
    <tr>
      <td>ピンソケット4ピン</a></td>
      <td>1</td>
    </tr>
    <tr>
      <td><a href="https://shop.yushakobo.jp/products/sk6812mini-e-10">LED（SK6812MINI-E)</a></td>
      <td>3</td>
    </tr>
 </table>

## はんだ付け
側面ユニットは表裏両方に部品をはんだ付けします。

左右の記載がある方が裏面です。
### （オプション）LEDのはんだ付け
LEDは3個取り付けます。すべてはんだ付けする面から見て丸い発光面が向こう向きです。

### MXスイッチソケットのはんだ付け（裏面）
裏面にピンセットで押し付けながらハンダごてに乗せたはんだを流し込みます。


### ダイオードのはんだ付け（裏面）
ダイオードには向きがあります。線とメインボードのマークの方向を合わせます。

4箇所に裏からダイオードを差し、表ではんだ付けして足を切ります。


### ピンヘッダーのはんだ付け（裏面）
40ピンヘッダーから6ピンを4本切り出します。


裏面から差し込み、表面ではんだ付けして足を切ります。
> [!WARNING]
> 長い方を差し込みます。反対にした場合は短い方と同程度まで切ります。



### （オプション）OLEDモジュールのはんだ付け（表面）
OLEDモジュールを着脱可能にする場合は表面に4ピンソケットをはんだ付けします。


OLEDモジュールにはOLED用ピンヘッダをはんだ付けします。    長い場合は短くカットしてください。

直接はんだ付けする場合はここでメインボードにはんだ付けします。

### ホイールエンコーダーのはんだ付け（表面）
ホイールエンコーダーを差し込み裏面をはんだ付けします。


## 仮組みとソケットのはんだ付け
### スイッチプレートの組み立て

スイッチプレートにタグが付いている場合は折ってからやすりで削ります。



スイッチプレートにM2スペーサー（短）をM2ネジ（短）で取り付けます。
> [!NOTE]
> スイッチプレートには上下があります。



スペーサーに保護プレート2種をM2ネジ（中）で取り付けます。

大きい方を上にします。
### ベースユニットへの取り付け
側面ユニットにM2スペーサー（長）をM2ネジ（短）で取り付けます。

> [!NOTE]
> 下側に一つ、上側に2つ付け正三角形にします。



初めて側面ユニットを作る場合、ベースユニットで余ったピンソケットから6ピンを2つ切り出して側面ユニットのピンソケットに差し込みます。


支柱に側面ユニットを差し込み、ベースユニットのM3ネジで止めます。
> [!CAUTION]
> ベースユニットの縦長のスルーホールにピンソケットの足が入るようにします。


ベースユニットの裏面でピンソケットをはんだ付けします。

これで側面ユニットのはんだ付けは終わりです。

OLEDモジュールを使う場合はここでピンソケットに差し込みます。


ホイールの部品を組み合わせます。細い方の軸は方向に気をつけてください。

少し力が要ることがあります。中くらいの軸はどちらからでも大丈夫です。


ホイールをはめて、スイッチプレートにキースイッチを取り付けてMXソケットに差し込みます。

保護プレートをM2ネジ（中）で固定します。

USBケーブルを差し動作を確認します。
> [!NOTE]
> 側面ユニットのLEDは天面ユニット（と追加ユニット）を取り付けるまで光りません。

問題がなければ天面ユニットの組み立てに進みます。
同梱されているものと、別売のホイール付きの2種類があります。

4. [天面ユニットの組み立て](../右手用/4_天面ユニット.md)
   - [（別売）ホイール付き天面ユニット](../右手用/4_ホイール付き天面ユニット.md)

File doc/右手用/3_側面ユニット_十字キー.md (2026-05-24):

# Killer Whale 十字キー側面ユニット 右手用ビルドガイド （[左手用](../左手用/3_側面ユニット_十字キー.md)）

1. [スタートページ](../../README.md)
2. [ベースユニットの組み立て](../右手用/2_ベースユニット.md)
3. 側面ユニットの組み立て
   - [トラックボール](../右手用/3_側面ユニット_トラックボール.md)
   - 十字キー（右手用）（このページ）
   - [（別売）ホイール 縦/横](../右手用/3_側面ユニット_ホイール.md)
   - [（別売）ジョイスティック](../右手用/3_側面ユニット_ジョイスティック.md)
4. [天面ユニットの組み立て](../右手用/4_天面ユニット.md)
5. [追加ユニットの組み立て](../右手用/5_追加ユニット.md)
6. [全体の組み立て](../右手用/6_全体の組み立て.md)
7. [カスタマイズ](../右手用/7_カスタマイズ.md)
8. [その他](../右手用/8_その他.md)

## 内容品

||部品名|数||
|-|-|-|-|
|1|メインボード|1|FR4|
|2|スイッチプレート|1|FR4|
|3|保護プレート|2|アクリル|
|5|M2ネジ（短）|5|4mm|
|6|M2ネジ（中）|5|6mm|
|9|M2スペーサー（短）|2|5mm
|10|M2スペーサー（長）|3|12mm|
|11|ダイオード|8|1N4148|
|12|MXスイッチソケット|2||
|13|ミュートスイッチ|4|
|14|ピンヘッダ|1||

以下の3Dプリンター製部品も使います。


## はんだ付け
側面ユニットは表裏両方に部品をはんだ付けします。

左右の記載がある方が裏面です。
### （オプション）LEDのはんだ付け
LEDは3個取り付けます。すべてはんだ付けする面から見て丸い発光面が向こう向きです。


### MXスイッチソケットのはんだ付け（裏面）
裏面にピンセットで押し付けながらハンダごてに乗せたはんだを流し込みます。


### ダイオードのはんだ付け（裏面）
ダイオードには向きがあります。線とメインボードのマークの方向を合わせます。

8箇所に裏からダイオードを差し、表ではんだ付けして足を切ります。


### ピンヘッダーのはんだ付け（裏面）
40ピンヘッダーから6ピンを4本切り出します。

裏面から差し込み、表面ではんだ付けして足を切ります。
> [!WARNING]
> 長い方を差し込みます。反対にした場合は短い方と同程度まで切ります。


### （オプション）OLEDモジュールのはんだ付け（表面）
OLEDモジュールを着脱可能にする場合は表面に4ピンソケットをはんだ付けします。

OLEDモジュールにはOLED用ピンヘッダをはんだ付けします。    長い場合は短くカットしてください

直接はんだ付けする場合はここでメインボードにはんだ付けします。。

### 十字キーのスイッチのはんだ付け（表面）
ミュートスイッチを表面から差し込んで裏面ではんだ付けします。


## 仮組みとソケットのはんだ付け
### スイッチプレートの組み立て

スイッチプレートにタグが付いている場合は折ってからやすりで削ります。



スイッチプレートにM2スペーサー（短）をM2ネジ（短）で取り付けます。
> [!NOTE]
> スイッチプレートには上下があります。



スペーサーに保護プレート2種をM2ネジ（中）で取り付けます。

大きい方を上にします。


### ベースユニットへの取り付け
側面ユニットにM2スペーサー（長）をM2ネジ（短）で取り付けます。

> [!NOTE]
> 下側に一つ、上側に2つ付け正三角形にします。



初めて側面ユニットを作る場合、ベースユニットで余ったピンソケットから6ピンを2つ切り出して側面ユニットのピンソケットに差し込みます。


支柱に側面ユニットを差し込み、ベースユニットのM3ネジで止めます。
> [!CAUTION]
> ベースユニットの縦長のスルーホールにピンソケットの足が入るようにします。


ベースユニットの裏面でピンソケットをはんだ付けします。

これで側面ユニットのはんだ付けは終わりです。

OLEDモジュールを使う場合はここでピンソケットに差し込みます。


十字キー用3Dプリンター部品を組み合わせます。


十字キーを挟み込むようにして、スイッチプレートにキースイッチを取り付けてMXソケットに差し込みます。

保護プレートをM2ネジ（中）で固定します。

USBケーブルを差し動作を確認します。
> [!NOTE]
> 側面ユニットのLEDは天面ユニット（と追加ユニット）を取り付けるまで光りません。

問題がなければ天面ユニットの組み立てに進みます。
同梱されているものと、別売のホイール付きの2種類があります。

4. [天面ユニットの組み立て](../右手用/4_天面ユニット.md)
   - [（別売）ホイール付き天面ユニット](../右手用/4_ホイール付き天面ユニット.md)

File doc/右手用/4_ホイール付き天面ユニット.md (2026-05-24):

# Killer Whale ホイール付き天面ユニット 右手用ビルドガイド （[左手用](../左手用/4_ホイール付き天面ユニット.md)）

1. [スタートページ](../../README.md)
2. [ベースユニットの組み立て](../右手用/2_ベースユニット.md)
3. [側面ユニットの組み立て](../右手用/3_側面ユニット_トラックボール.md)
4. [天面ユニットの組み立て](../右手用/4_天面ユニット.md)
   - （別売）ホイール付き天面ユニットの組み立て（右手用）（このページ）
5. [追加ユニットの組み立て](../右手用/5_追加ユニット.md)
6. [全体の組み立て](../右手用/6_全体の組み立て.md)
7. [カスタマイズ](../右手用/7_カスタマイズ.md)
8. [その他](../右手用/8_その他.md)
## 内容品

||部品名|数||
|-|-|-|-|
|1|メインボード|1|FR4|
|2|スイッチプレート|1|FR4|
|3|保護プレート|2|アクリル|
|4|M2ネジ（短）|6|4mm|
|5|M2ネジ（中）|4|6mm|
|6|M2スペーサー（短）|2|8mm|
|7|M2スペーサー（長）|4|16mm|
|8|ピンヘッダ|1||
|9|MXスイッチソケット|21||
|10|ダイオード|27||
|11|ホイールエンコーダー|2||

以下の3Dプリンター製部品も使います。
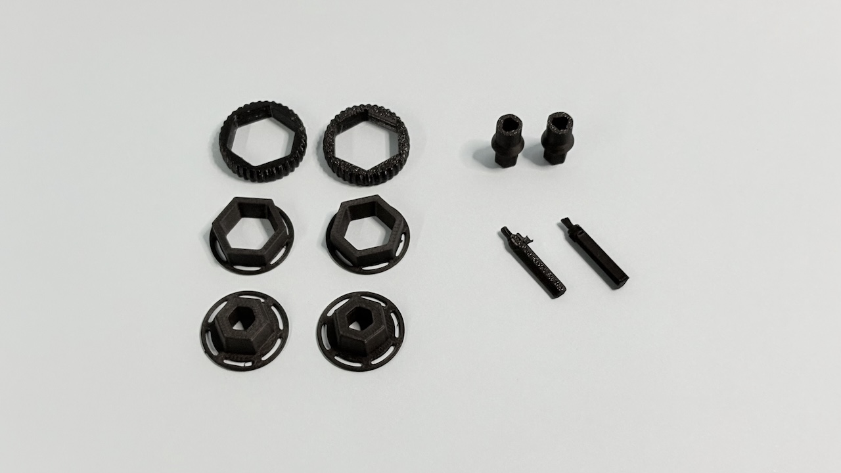
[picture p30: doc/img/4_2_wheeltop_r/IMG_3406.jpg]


### キット以外に必要なもの
|部品名|数||
|-|-|-|
|[キースイッチ](https://shop.yushakobo.jp/collections/all-switches)|21|Cherry MX互換|
|[キーキャップ](https://shop.yushakobo.jp/collections/keycaps)|21|Cherry MX互換|

## はんだ付け
ホイール付き天面ユニットは表裏両方に部品をはんだ付けします。


### （オプション）LEDのはんだ付け（裏面）
すべて発光面が向こう向きになります。

> [!CAUTION]
> 場所により向きが異なります。

### ダイオードのはんだ付け（裏面）
裏面にD1からD27までダイオードを差し、表ではんだ付けして足を切ります。

### MXスイッチソケットのはんだ付け（裏面）
裏面にピンセットで押し付けながらハンダごてに乗せたはんだを流し込みます。

両側をはんだしてずれなくなったらピンセットからはんだに持ち替えて追加で流し込みしましょう。  表面積が広く多めのはんだが必要です。

### ピンヘッダーのはんだ付け（裏面）
40ピンヘッダーから7ピンを2本切り出して裏面に立ててはんだ付けします。長い方を差し込みます。



### ホイールエンコーダーのはんだ付け（表面）
エンコーダーの裾のプレートを少し広げます（ショートを防ぐため）。

基板の四角マークに合わせてホイールエンコーダーを差し込み裏面をはんだ付けします。

M2ネジ（短）でスペーサー6つを止めます。真ん中に短いスペーサーを使います。


## 仮組みとソケットのはんだ付け
ベースユニットにピンソケットを取り付けていない場合、ベースユニットで余ったピンソケットから7ピンを2つ切り出して側面ユニットのピンソケットに差し込みます。


支柱に天面ユニットを差し込み、M3ネジで止めます。  ベースユニットの横長のスルーホールにピンソケットの足が入るようにします。

ベースユニットの裏面でピンソケットをはんだ付けします。

スイッチプレートを挟み込むようにキースイッチを取り付けます。


ホイールの部品を組み合わせます。細い方の軸は方向に気をつけてください。

少し力が要ることがあります。中くらいの軸はどちらからでも大丈夫です。


ホイールをホイールエンコーダーに差し込み、保護プレートをM2ネジ（中）で固定します。

USBを繋いで動作確認をします。

追加ユニットは必須ではありません。取り付ける場合は追加ユニットの説明に、取り付けない場合は全体の組立てに進みます。

5. [追加ユニットの組み立て](../右手用/5_追加ユニット.md)
6. [全体の組み立て](../右手用/6_全体の組み立て.md)

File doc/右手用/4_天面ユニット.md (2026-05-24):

# Killer Whale　天面ユニット 右手用ビルドガイド （[左手用](../左手用/4_天面ユニット.md)）

1. [スタートページ](../../README.md)
2. [ベースユニットの組み立て](../右手用/2_ベースユニット.md)
3. [側面ユニットの組み立て](../右手用/3_側面ユニット_トラックボール.md)
4. 天面ユニットの組み立て（右手用）（このページ）
   - [（別売）ホイール付き天面ユニットの組み立て](../右手用/4_ホイール付き天面ユニット.md)
5. [追加ユニットの組み立て](../右手用/5_追加ユニット.md)
6. [全体の組み立て](../右手用/6_全体の組み立て.md)
7. [カスタマイズ](../右手用/7_カスタマイズ.md)
8. [その他](../右手用/8_その他.md)

## 内容品
    
||部品名|数||
|-|-|-|-|
|1|メインボード|1|FR4|
|2|スイッチプレート|1|FR4|
|3|ダイオード|30||
|4|ピンヘッダ|1||
|5|MXスイッチソケット|24||

## はんだ付け
天面ユニットは全ての部品を裏に実装します。  
  

### （オプション）LEDのはんだ付け 

> [!CAUTION]
> 場所により向きが異なります。

  

### ダイオードのはんだ付け
D1からD30までダイオードを裏から差し、表ではんだ付けして足を切ります。  
 
### MXスイッチソケットのはんだ付け
ピンセットで押し付けながらハンダごてに乗せたはんだを流し込みます。  
 

### ピンヘッダーのはんだ付け
40ピンヘッダーから7ピンを2本切り出し、裏面に立ててはんだ付けします。長い方を差し込みます。   
   
 

### 仮組みとソケットのはんだ付け
初めて天面ユニットを作る場合、ベースユニットで余ったピンソケットから7ピンを2つ切り出して天面ユニットのピンソケットに差し込みます。  
   
 
支柱に天面ユニットを差し込み、M3ネジで止めます。

> [!NOTE]
> ベースユニットの横長のスルーホールにピンソケットの足が入るようにします。

 
ベースユニットの裏面でピンソケットをはんだ付けします。
 
スイッチプレートを挟み込むようにスイッチを取り付けたらUSBを繋いで動作確認をします。
  

追加ユニットは必須ではありません。取り付ける場合は追加ユニットの説明に、取り付けない場合は全体の組立てに進みます。  

5. [追加ユニットの組み立て](../右手用/5_追加ユニット.md)
6. [全体の組み立て](../右手用/6_全体の組み立て.md)

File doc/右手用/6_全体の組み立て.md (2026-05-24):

# Killer Whale　全体の組み立て 右手用ビルドガイド （[左手用](../左手用/6_全体の組み立て.md)）

1. [スタートページ](../../README.md)
2. [ベースユニットの組み立て](../右手用/2_ベースユニット.md)
3. [側面ユニットの組み立て](../右手用/3_側面ユニット_トラックボール.md)
4. [天面ユニットの組み立て](../右手用/4_天面ユニット.md)
5. [追加ユニットの組み立て](../右手用/5_追加ユニット.md)
6. 全体の組み立て（右手用）（このページ）
7. [カスタマイズ](../右手用/7_カスタマイズ.md)
8. [その他](../右手用/8_その他.md)

##　組み立て
### ボトムプレートの取り付け
底面のM3ネジをはずして、ピンソケットからピンヘッダーを抜きながら天面ユニットを外します。  
同様に側面ユニットも取り外します。  
  

ネジ（黒）4本にワッシャー（黒）を通します。  
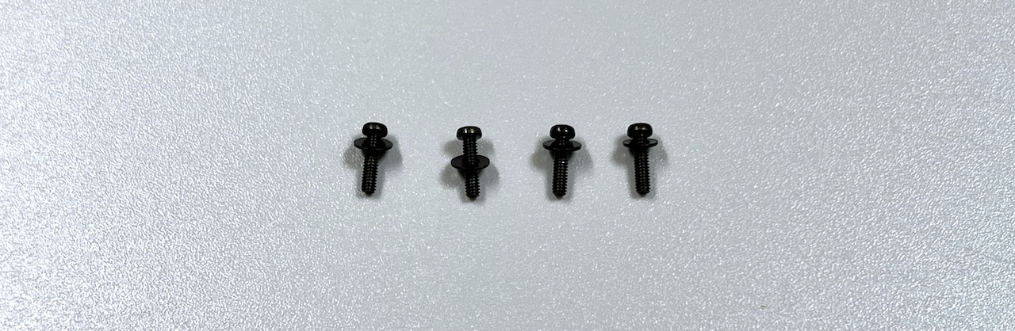
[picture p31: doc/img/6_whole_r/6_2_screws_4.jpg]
  
ベースユニットにボトムプレートをあてて裏面からネジを差し込み、表面でワッシャー黒、スプリングワッシャー黒、ナット黒で締めます。  
  
ゴム足を4つ貼りました。  
 

### （オプション）追加ユニットの取り付け
ネジ（黒）3本にワッシャー（黒）を通します。 
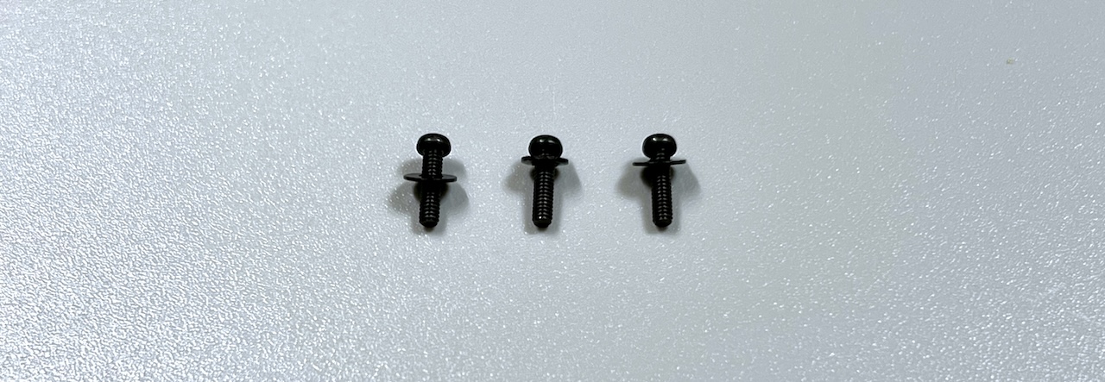
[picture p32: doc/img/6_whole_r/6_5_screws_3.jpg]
  
追加ユニットをスライドさせてL字ピンヘッダをL字ピンソケットに差し込みます。
  
3箇所のネジ穴にM2ネジ（黒）を通してワッシャー黒、スプリングワッシャー黒、ナットの順で止めます。  
  
ゴム足を貼ります。
  
USBを繋いで動作を確認します。
> [!NOTE]
> LEDは天面ユニットを取り付けるまで光りません。
> ホイールのスクロール方向は後から変更できます。  

### 仕上げ
側面ユニット、天面ユニットの順で付け直します。
  
キーキャップを付ければ完成です。
  
お疲れ様でした。

次のページはキー設定の解説です。

7. [カスタマイズ](../右手用/7_カスタマイズ.md)

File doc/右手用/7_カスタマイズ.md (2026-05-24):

# Killer Whale カスタマイズ 右手用ビルドガイド （[左手用](../左手用/7_カスタマイズ.md)）

1. [スタートページ](../../README.md)
2. [ベースユニットの組み立て](../右手用/2_ベースユニット.md)
3. [側面ユニットの組み立て](../右手用/3_側面ユニット_トラックボール.md)
4. [天面ユニットの組み立て](../右手用/4_天面ユニット.md)
5. [追加ユニットの組み立て](../右手用/5_追加ユニット.md)
6. [全体の組み立て](../右手用/6_全体の組み立て.md)
7. カスタマイズ（このページ）
8. [その他](../右手用/8_その他.md)

## Remap用ファームウェアを書き込む
全てのキーの反応を確かめたら使用方法に合ったファームウェアをこちらからダウンロードします。
- 単体用 [tarohayashi_killerwhale_solo_default.uf2
](https://github.com/Taro-Hayashi/KillerWhale/releases/latest/download/tarohayashi_killerwhale_solo_default.uf2)
- 左右分割用 [tarohayashi_killerwhale_duo_default.uf2
](https://github.com/Taro-Hayashi/KillerWhale/releases/latest/download/tarohayashi_killerwhale_duo_default.uf2)

#### ※左右間のケーブルを着け外しする時は必ずUSBケーブルを抜いてください。
※追加ユニットのトグルスイッチは手のひら側に倒した状態にします。

Raspberry Pi Picoのボタンか画像のキーを押しながらUSBケーブルを接続するとRPI-RP2フォルダが出てくるのでuf2ファイルをドラッグアンドドロップします。

- 左右分割キーボードとして使う場合は両手とも更新します。
- 左右を繋ぐケーブルの差込口は2つありますがどちらを使っても大丈夫です。

## 左右を切り替える（単体使用時）
標準では左手用のQWERTYの配列になっています。右手用のキーマップにはトグルスイッチで切り替え可能です。
画像のキーの組み合わせで追加ユニットを使わない場合でも左右のキーマップを切り替えることが可能です。


## マウスのボタンとオートマウスについて
トラックボールの側面ユニットを使った場合、ボールを動かした直後はF（J）キーがマウスのクリックになり、D（K）キーが右クリックになります（オートマウス機能）。


- 側面ユニットに一番近いキーを長押ししている間はボールを動かしてスクロールすることができます。
- 追加ユニットのキーにもクリックが割り当てられています。ホイールはスクロールです。

オートマウス機能は以下でオンオフできます。
## トラックボール（ジョイスティック）の方向、速度、モードを変える
角から2番目のキー（4、7）を押しながら画像のキーを押すとトラックボールの設定を変更できます。

- 角度の変更と軸の反転を組み合わせて好みの角度に設定します。
- ジョイスティックやトラックボールのカーソル移動/スクロール/十字キー入力をモード変更で切り替えることができます。

## キーマップのカスタマイズ
ジョイスティクやホイールを含めて全てのキーは、RemapというWebサイトで好きなように変更することができます。

Google Chrome（Microsoft Edge）を利用して下記webサイトにアクセスします。
- Remap https://remap-keys.app





### 保存と復元
こちらからキーマップの保存と復元ができます。

キーマップの共有もできるので良かったら公開してみてください。

### 左右の変更（単体使用時）、縮小モード（両手使用時）
こちらからRemapの見た目を変更することができます。


### キーの割り当て
ドラッグアンドドロップしてFLASHを押すとキーを変更できます。

下のEnglish(US)のプルダウンをJapaneseに変更すると日本語キーボード（JIS）のキーに対応できます。OSの設定を確認して合わせます。

### LEDの調整
このボタンで発光方法を変更することができます。


### 特殊なキーの割り当て
FUNCTIONSタブのVIA USER KEYにOSに関わらず使えるショートカットやトラックボール、OLEDなどの設定をするキーがあります。


最後のページはファームウェア、JSONファイル、トラブルシューティングの簡単なまとめです。

8. [その他](../右手用/8_その他.md)

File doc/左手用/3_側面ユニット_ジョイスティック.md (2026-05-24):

# Killer Whale ジョイスティック側面ユニット 左手用ビルドガイド （[右手用](../右手用/3_側面ユニット_ジョイスティック.md)）

1. [スタートページ](../../README.md)
2. [ベースユニットの組み立て](../左手用/2_ベースユニット.md)
3. 側面ユニットの組み立て
   - [トラックボール](../左手用/3_側面ユニット_トラックボール.md)
   - [十字キー](../左手用/3_側面ユニット_十字キー.md)
   - [（別売）ホイール 縦/横](../左手用/3_側面ユニット_ホイール.md)
   - （別売）ジョイスティック（左手用）（このページ）
4.  [天面ユニットの組み立て](../左手用/4_天面ユニット.md)
5. [追加ユニットの組み立て](../左手用/5_追加ユニット.md)
6. [全体の組み立て](../左手用/6_全体の組み立て.md)
7. [カスタマイズ](../左手用/7_カスタマイズ.md)
8. [その他](../左手用/8_その他.md)

## ご注意
左右分割キーボードとして使用する時、ジョイスティックはUSBを接続している側のみ動作します。
## 内容品

||部品名|数||
|-|-|-|-|
|1|メインボード|1|FR4|
|2|スイッチプレート|1|FR4|
|3|保護プレート|2|アクリル|
|4|M2ネジ（短）|5|4mm|
|5|M2ネジ（中）|5|6mm|
|6|M2スペーサー（短）|2|9mm|
|7|M2スペーサー（長）|3|16mm|
|8|ダイオード|5|1N4148|
|9|MXスイッチソケット|2||
|10|ジョイスティック|1||
|11|キャップ|1||
|12|ピンヘッダ|1||

### キット以外に必要なもの
|部品名|数||
|-|-|-|
|[キースイッチ](https://shop.yushakobo.jp/collections/all-switches)|2|Cherry MX互換|
|[キーキャップ](https://shop.yushakobo.jp/collections/keycaps)|2|Cherry MX互換|
|幅1cm以下の棒やすり||処理済みで必要ないことがあります|

### オプション
<table>
    <tr>
      <td><a href="https://shop.yushakobo.jp/products/oled">OLEDモジュール</a></td>
      <td>1</td>
    </tr>
    <tr>
      <td>ピンソケット4ピン</a></td>
      <td>1</td>
    </tr>
    <tr>
      <td><a href="https://shop.yushakobo.jp/products/sk6812mini-e-10">LED（SK6812MINI-E)</a></td>
      <td>3</td>
    </tr>
 </table>

## はんだ付け
側面ユニットは表裏両方に部品をはんだ付けします。

左右の記載がある方が裏面です。
### （オプション）LEDのはんだ付け
LEDは3個取り付けます。すべてはんだ付けする面から見て丸い発光面が向こう向きです。

### MXスイッチソケットのはんだ付け（裏面）
裏面にピンセットで押し付けながらハンダごてに乗せたはんだを流し込みます。


### ダイオードのはんだ付け（裏面）
ダイオードには向きがあります。線とメインボードのマークの方向を合わせます。

4箇所に裏からダイオードを差し、表ではんだ付けして足を切ります。


### ピンヘッダーのはんだ付け（裏面）
40ピンヘッダーから6ピンを4本切り出します。


裏面から差し込み、表面ではんだ付けして足を切ります。
> [!WARNING]
> 長い方を差し込みます。反対にした場合は短い方と同程度まで切ります。



### （オプション）OLEDモジュールのはんだ付け（表面）
OLEDモジュールを着脱可能にする場合は表面に4ピンソケットをはんだ付けします。


OLEDモジュールにはOLED用ピンヘッダをはんだ付けします。  長い場合は短くカットしてください。

直接はんだ付けする場合はここでメインボードにはんだ付けします。
### ジョイスティックのはんだ付け（表面）
表から差し込んで裏ではんだ付けします。


## 仮組みとソケットのはんだ付け
### スイッチプレートの組み立て

スイッチプレートにタグが付いている場合は折ってからやすりで削ります。



スイッチプレートにM2スペーサー（短）をM2ネジ（短）で取り付けます。
> [!NOTE]
> スイッチプレートには上下があります。



スペーサーに保護プレート2種をM2ネジ（中）で取り付けます。

大きい方を上にします。

### ベースユニットへの取り付け
側面ユニットにM2スペーサー（長）をM2ネジ（短）で取り付けます。

> [!NOTE]
> 下側に一つ、上側に2つ付け正三角形にします。



初めて側面ユニットを作る場合、ベースユニットで余ったピンソケットから6ピンを2つ切り出して側面ユニットのピンソケットに差し込みます。


支柱に側面ユニットを差し込み、ベースユニットのM3ネジで止めます。
> [!CAUTION]
> ベースユニットの縦長のスルーホールにピンソケットの足が入るようにします。


ベースユニットの裏面でピンソケットをはんだ付けします。

これで側面ユニットのはんだ付けは終わりです。

OLEDモジュールを使う場合はここでピンソケットに差し込みます。


ジョイスティックにキャップをはめて、スイッチプレートにキースイッチを取り付けてMXソケットに差し込みます。

保護プレートをM2ネジ（中）で固定したら完成です。

USBケーブルを差し動作を確認します。
> [!NOTE]
> 側面ユニットのLEDは天面ユニット（と追加ユニット）を取り付けるまで光りません。

## ゲームパッドのアナログスティックとしての利用について
ジョイスティック側面ユニットを使っている場合、従来の3つのモード（カーソル移動、スクロール、キー入力）に加えてゲームモードに切り替えガできます。

DirectInputのコントローラーとして認識されるのでXInputへの対応のゲームではXbox 360 Controller Emulator等をお使いください。

ゲームモードでもスティックが認識される角度の変更をすることができます。回転とX軸の反転を組み合わせて好みの方向に変えてください。また、スティックが反応する傾きの範囲も変更できるので感度や斜め入力のしやすさもある程度調整できます。

ゲームモードでのジョイスティックは自動でキャリブレーションを行っています。USBケーブルの接続後は大きく一周回すとすぐに正確な方向が入力できるようになります。

問題がなければ天面ユニットの組み立てに進みます。
同梱されているものと、別売のホイール付きの2種類があります。

1. [天面ユニットの組み立て](../左手用/4_天面ユニット.md)
   - [（別売）ホイール付き天面ユニット](../左手用/4_ホイール付き天面ユニット.md)

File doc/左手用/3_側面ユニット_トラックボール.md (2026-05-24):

# Killer Whale トラックボール側面ユニット 左手用ビルドガイド （[右手用](../右手用/3_側面ユニット_トラックボール.md)）

1. [スタートページ](../../README.md)
2. [ベースユニットの組み立て](../左手用/2_ベースユニット.md)
3. 側面ユニットの組み立て
   - トラックボール（左手用）（このページ）
   - [十字キー](../左手用/3_側面ユニット_十字キー.md)
   - [（別売）ホイール 縦/横](../左手用/3_側面ユニット_ホイール.md)
   - [（別売）ジョイスティック](../左手用/3_側面ユニット_ジョイスティック.md)
4.  [天面ユニットの組み立て](../左手用/4_天面ユニット.md)
5. [追加ユニットの組み立て](../左手用/5_追加ユニット.md)
6. [全体の組み立て](../左手用/6_全体の組み立て.md)
7. [カスタマイズ](../左手用/7_カスタマイズ.md)
8. [その他](../左手用/8_その他.md)
## 内容品

||部品名|数||
|-|-|-|-|
|1|メインボード|1|FR4|
|2|スイッチプレート|1|FR4|
|3|保護プレート|1|アクリル|
|4|M2ネジ（短）|2|4mm|
|5|M2ネジ（中）|2|6mm|
|6|M2ネジ（長）|3|10mm|
|7|M3ネジ|3|10mm|
|8|M2ナット|3|
|9|M3四角ナット|3||
|10|M2スペーサー（長）|2|7mm or 8mm|
|11|ベアリング|3|2x6x2.5|
|12|コンデンサーC3|1|4.7uF|
|13|コンデンサーC1,C2|2|10uF|
|14|レギュレーター|1|UT7500L-18|
|15|MXスイッチソケット|2||
|16|ダイオード|4|1N4148|
|17|センサーとレンズ|1|PMW3360DM-T2QU / LM19-LSI|
|18|ピンヘッダ|1||

以下の3Dプリンター製部品も使います。


## はんだ付け
側面ユニットは表裏両方に部品をはんだ付けします。


左右の記載がある方が裏面です。
### （オプション）LEDのはんだ付け
LEDは3個取り付けます。すべてはんだ付けする面から見て丸い発光面が向こう向きです。


### MXスイッチソケットのはんだ付け（裏面）
裏面にピンセットで押し付けながらハンダごてに乗せたはんだを流し込みます。


### ダイオードのはんだ付け（裏面）
ダイオードには向きがあります。線とメインボードのマークの方向を合わせます。

4箇所に裏からダイオードを差し、表ではんだ付けして足を切ります。


### センサー類のはんだ付け（裏面）
裏面でメインボードの丸マークとチップの丸の位置を合わせて表面ではんだ付けします。
> [!NOTE]
> センサーのシールはまだ剥がさない方が安全です。



コンデンサーをはんだ付けします。106と書いてあるのがC1,C2で475がC3です。



レギュレーターを裏面から差し、メインボードの印刷どおり平面が下になるように折り曲げてはんだ付けします。


### ピンヘッダーのはんだ付け（裏面）
40ピンヘッダーから6ピンを4本切り出します。


裏面から差し込み、表面ではんだ付けして足を切ります。
> [!WARNING]
> 長い方を差し込みます。反対にした場合は短い方と同程度まで切ります。



### （オプション）OLEDモジュールのはんだ付け（表面）
OLEDモジュールを着脱可能にする場合は表面に4ピンソケットをはんだ付けします。


OLEDモジュールにはOLED用ピンヘッダをはんだ付けします。    長い場合は短くカットしてください。

直接はんだ付けする場合はここでメインボードにはんだ付けします。

## 仮組みとソケットのはんだ付け
### スイッチプレートの組み立て
スイッチプレートにタグが付いている場合は折ってからやすりで削ります。


スイッチプレートにM2スペーサー（長）をM2ネジ（短）で取り付けます。
> [!NOTE]
> スイッチプレートには上下があります。



スペーサーに保護プレートを、M2ネジ（中）で取り付けます。
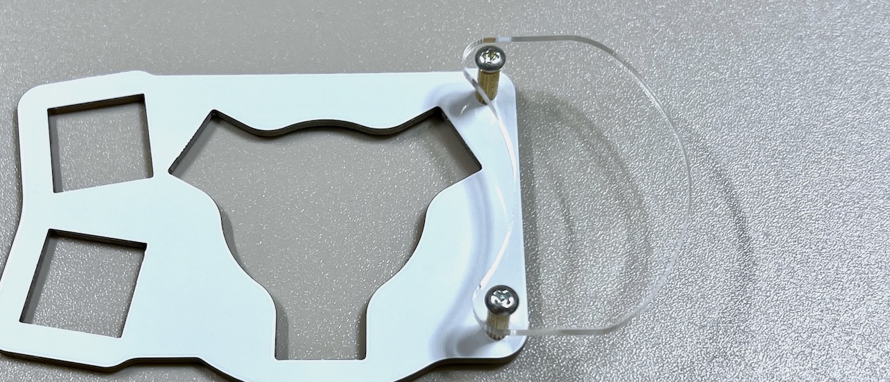
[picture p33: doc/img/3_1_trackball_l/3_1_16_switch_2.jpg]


### トラックボールケースの取り付け
センサーの保護フィルムをはがし、レンズを取り付けます。
> [!IMPORTANT]
> レンズには取り付け方向があります。



裏面に出ているレンズの足をはんだごてで熱して固定します。


ボールケース支柱の3箇所にベアリングを3本のネジと3個のナットで固定します。


ボールケース支柱を立て、スリットにM3角ナットを当てたら裏面からネジ止めします。
> [!NOTE]
> 下側は支柱が一本、上側に2本で正三角形を作るように立てます。



### ベースユニットへの取り付け
初めて側面ユニットを作る場合、ベースユニットのピンソケットから6ピンを2つ切り出して側面ユニットのピンソケットに差し込みます。


支柱に側面ユニットを差し込み、ベースユニットのM3ネジで止めます。
> [!CAUTION]
> ベースユニットの縦長のスルーホールにピンソケットの足が入るようにします。


ベースユニットの裏面でピンソケットをはんだ付けします。

これで側面ユニットのはんだ付けは終わりです。

OLEDモジュールを使う場合はここでピンソケットに差し込みます。


スイッチプレートにキースイッチを取り付けてMXソケットに差し込み、カバーを取り付けます。


USBケーブルを差し動作を確認します。


> [!NOTE]
> 側面ユニットのLEDは天面ユニット（と追加ユニット）を取り付けるまで光りません。
> カーソルの方向や速度は後で調節できます。

問題がなければ天面ユニットの組み立てに進みます。
同梱されているものと、別売のホイール付きの2種類があります。

4. [天面ユニットの組み立て](../左手用/4_天面ユニット.md)
   - [（別売）ホイール付き天面ユニット](../左手用/4_ホイール付き天面ユニット.md)

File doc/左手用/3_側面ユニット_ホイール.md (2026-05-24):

# Killer Whale ホイール側面ユニット 縦/横 左手用ビルドガイド （[右手用](../右手用/3_側面ユニット_ホイール.md)）

1. [スタートページ](../../README.md)
2. [ベースユニットの組み立て](../左手用/2_ベースユニット.md)
3. 側面ユニットの組み立て
   - [トラックボール](../左手用/3_側面ユニット_トラックボール.md)
   - [十字キー](../左手用/3_側面ユニット_十字キー.md)
   - （別売）ホイール 縦/横（左手用）（このページ）
   - [（別売）ジョイスティック](../左手用/3_側面ユニット_ジョイスティック.md)
4. [天面ユニットの組み立て](../左手用/4_天面ユニット.md)
5. [追加ユニットの組み立て](../左手用/5_追加ユニット.md)
6. [全体の組み立て](../左手用/6_全体の組み立て.md)
7. [カスタマイズ](../左手用/7_カスタマイズ.md)
8. [その他](../左手用/8_その他.md)

## 内容品

||部品名|数||
|-|-|-|-|
|1|メインボード|1|FR4|
|2|スイッチプレート|1|FR4|
|3|保護プレート|2|アクリル|
|4|M2ネジ（短）|5|4mm|
|5|M2ネジ（中）|4|6mm|
|6|M2スペーサー（短1）|1|8mm|
|6|M2スペーサー（短2）|2|9mm|
|7|M2スペーサー（長）|2|16mm|
|8|MXスイッチソケット|2||
|9|ホイールエンコーダー|1||
|11|ダイオード|4|1N4148|
|12|ピンヘッダ|1||

以下の3Dプリンター製部品も使います。


※ホイールの縦と横でメインボード、保護プレートの違いがありますが大きく違いはありませんので適宜読み替えてください。

### キット以外に必要なもの
|部品名|数||
|-|-|-|
|[キースイッチ](https://shop.yushakobo.jp/collections/all-switches)|2|Cherry MX互換|
|[キーキャップ](https://shop.yushakobo.jp/collections/keycaps)|2|Cherry MX互換|
|幅1cm以下の棒やすり||整形済みで必要ないことがあります|

### オプション
<table>
    <tr>
      <td><a href="https://shop.yushakobo.jp/products/oled">OLEDモジュール</a></td>
      <td>1</td>
    </tr>
    <tr>
      <td>ピンソケット4ピン</a></td>
      <td>1</td>
    </tr>
    <tr>
      <td><a href="https://shop.yushakobo.jp/products/sk6812mini-e-10">LED（SK6812MINI-E)</a></td>
      <td>3</td>
    </tr>
 </table>

## はんだ付け
側面ユニットは表裏両方に部品をはんだ付けします。

左右の記載がある方が裏面です。
### （オプション）LEDのはんだ付け
LEDは3個取り付けます。すべてはんだ付けする面から見て丸い発光面が向こう向きです。

### MXスイッチソケットのはんだ付け（裏面）
裏面にピンセットで押し付けながらハンダごてに乗せたはんだを流し込みます。


### ダイオードのはんだ付け（裏面）
ダイオードには向きがあります。線とメインボードのマークの方向を合わせます。

4箇所に裏からダイオードを差し、表ではんだ付けして足を切ります。


### ピンヘッダーのはんだ付け（裏面）
40ピンヘッダーから6ピンを4本切り出します。


裏面から差し込み、表面ではんだ付けして足を切ります。
> [!WARNING]
> 長い方を差し込みます。反対にした場合は短い方と同程度まで切ります。



### （オプション）OLEDモジュールのはんだ付け（表面）
OLEDモジュールを着脱可能にする場合は表面に4ピンソケットをはんだ付けします。


OLEDモジュールにはOLED用ピンヘッダをはんだ付けします。    長い場合は短くカットしてください。

直接はんだ付けする場合はここでメインボードにはんだ付けします。

### ホイールエンコーダーのはんだ付け（表面）
ホイールエンコーダーを差し込み裏面をはんだ付けします。


## 仮組みとソケットのはんだ付け
### スイッチプレートの組み立て

スイッチプレートにタグが付いている場合は折ってからやすりで削ります。



スイッチプレートにM2スペーサー（短）をM2ネジ（短）で取り付けます。
> [!NOTE]
> スイッチプレートには上下があります。



スペーサーに保護プレート2種をM2ネジ（中）で取り付けます。

大きい方を上にします。
### ベースユニットへの取り付け
側面ユニットにM2スペーサー（長）をM2ネジ（短）で取り付けます。

> [!NOTE]
> 下側に一つ、上側に2つ付け正三角形にします。



初めて側面ユニットを作る場合、ベースユニットで余ったピンソケットから6ピンを2つ切り出して側面ユニットのピンソケットに差し込みます。


支柱に側面ユニットを差し込み、ベースユニットのM3ネジで止めます。
> [!CAUTION]
> ベースユニットの縦長のスルーホールにピンソケットの足が入るようにします。


ベースユニットの裏面でピンソケットをはんだ付けします。

これで側面ユニットのはんだ付けは終わりです。

OLEDモジュールを使う場合はここでピンソケットに差し込みます。


ホイールの部品を組み合わせます。細い方の軸は方向に気をつけてください。

少し力が要ることがあります。中くらいの軸はどちらからでも大丈夫です。


ホイールをはめて、スイッチプレートにキースイッチを取り付けてMXソケットに差し込みます。

保護プレートをM2ネジ（中）で固定します。

USBケーブルを差し動作を確認します。
> [!NOTE]
> 側面ユニットのLEDは天面ユニット（と追加ユニット）を取り付けるまで光りません。

問題がなければ天面ユニットの組み立てに進みます。
同梱されているものと、別売のホイール付きの2種類があります。

4. [天面ユニットの組み立て](../左手用/4_天面ユニット.md)
   - [（別売）ホイール付き天面ユニット](../左手用/4_ホイール付き天面ユニット.md)

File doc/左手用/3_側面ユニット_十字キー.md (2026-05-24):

# Killer Whale 十字キー側面ユニット 左手用ビルドガイド （[右手用](../右手用/3_側面ユニット_十字キー.md)）

1. [スタートページ](../../README.md)
2. [ベースユニットの組み立て](../左手用/2_ベースユニット.md)
3. 側面ユニットの組み立て
   - [トラックボール](../左手用/3_側面ユニット_トラックボール.md)
   - 十字キー（左手用）（このページ）
   - [（別売）ホイール 縦/横](../左手用/3_側面ユニット_ホイール.md)
   - [（別売）ジョイスティック](../左手用/3_側面ユニット_ジョイスティック.md)
4. [天面ユニットの組み立て](../左手用/4_天面ユニット.md)
5. [追加ユニットの組み立て](../左手用/5_追加ユニット.md)
6. [全体の組み立て](../左手用/6_全体の組み立て.md)
7. [カスタマイズ](../左手用/7_カスタマイズ.md)
8. [その他](../左手用/8_その他.md)

## 内容品

||部品名|数||
|-|-|-|-|
|1|メインボード|1|FR4|
|2|スイッチプレート|1|FR4|
|3|保護プレート|2|アクリル|
|5|M2ネジ（短）|5|4mm|
|6|M2ネジ（中）|5|6mm|
|9|M2スペーサー（短）|2|5mm
|10|M2スペーサー（長）|3|12mm|
|11|ダイオード|8|1N4148|
|12|MXスイッチソケット|2||
|13|ミュートスイッチ|4|
|14|ピンヘッダ|1||

以下の3Dプリンター製部品も使います。


## はんだ付け
側面ユニットは表裏両方に部品をはんだ付けします。

左右の記載がある方が裏面です。
### （オプション）LEDのはんだ付け
LEDは3個取り付けます。すべてはんだ付けする面から見て丸い発光面が向こう向きです。


### MXスイッチソケットのはんだ付け（裏面）
裏面にピンセットで押し付けながらハンダごてに乗せたはんだを流し込みます。


### ダイオードのはんだ付け（裏面）
ダイオードには向きがあります。線とメインボードのマークの方向を合わせます。

8箇所に裏からダイオードを差し、表ではんだ付けして足を切ります。
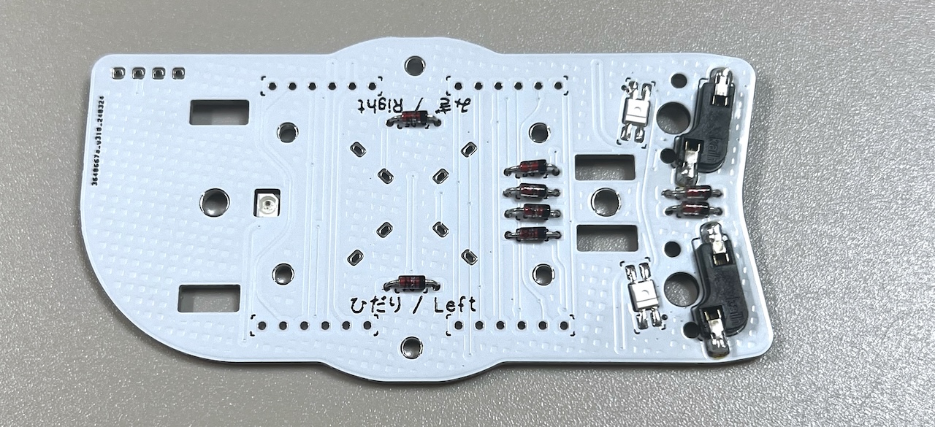
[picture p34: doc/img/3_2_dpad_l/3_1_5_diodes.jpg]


### ピンヘッダーのはんだ付け（裏面）
40ピンヘッダーから6ピンを4本切り出します。

裏面から差し込み、表面ではんだ付けして足を切ります。
> [!WARNING]
> 長い方を差し込みます。反対にした場合は短い方と同程度まで切ります。


### （オプション）OLEDモジュールのはんだ付け（表面）
OLEDモジュールを着脱可能にする場合は表面に4ピンソケットをはんだ付けします。

OLEDモジュールにはOLED用ピンヘッダをはんだ付けします。    長い場合は短くカットしてください。

直接はんだ付けする場合はここでメインボードにはんだ付けします。

### 十字キーのスイッチのはんだ付け（表面）
ミュートスイッチを表面から差し込んで裏面ではんだ付けします。


## 仮組みとソケットのはんだ付け
### スイッチプレートの組み立て

スイッチプレートにタグが付いている場合は折ってからやすりで削ります。



スイッチプレートにM2スペーサー（短）をM2ネジ（短）で取り付けます。
> [!NOTE]
> スイッチプレートには上下があります。



スペーサーに保護プレート2種をM2ネジ（中）で取り付けます。

大きい方を上にします。


### ベースユニットへの取り付け
側面ユニットにM2スペーサー（長）をM2ネジ（短）で取り付けます。

> [!NOTE]
> 下側に一つ、上側に2つ付け正三角形にします。



初めて側面ユニットを作る場合、ベースユニットで余ったピンソケットから6ピンを2つ切り出して側面ユニットのピンソケットに差し込みます。


支柱に側面ユニットを差し込み、ベースユニットのM3ネジで止めます。
> [!CAUTION]
> ベースユニットの縦長のスルーホールにピンソケットの足が入るようにします。


ベースユニットの裏面でピンソケットをはんだ付けします。

これで側面ユニットのはんだ付けは終わりです。

OLEDモジュールを使う場合はここでピンソケットに差し込みます。


十字キー用3Dプリンター部品を組み合わせます。


十字キーを挟み込むようにして、スイッチプレートにキースイッチを取り付けてMXソケットに差し込みます。

保護プレートをM2ネジ（中）で固定します。

USBケーブルを差し動作を確認します。
> [!NOTE]
> 側面ユニットのLEDは天面ユニット（と追加ユニット）を取り付けるまで光りません。

問題がなければ天面ユニットの組み立てに進みます。
同梱されているものと、別売のホイール付きの2種類があります。

4. [天面ユニットの組み立て](../左手用/4_天面ユニット.md)
   - [（別売）ホイール付き天面ユニット](../左手用/4_ホイール付き天面ユニット.md)

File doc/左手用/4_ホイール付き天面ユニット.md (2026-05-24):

# Killer Whale ホイール付き天面ユニット 左手用ビルドガイド （[右手用](../右手用/4_ホイール付き天面ユニット.md)）

1. [スタートページ](../../README.md)
2. [ベースユニットの組み立て](../左手用/2_ベースユニット.md)
3. [側面ユニットの組み立て](../左手用/3_側面ユニット_トラックボール.md)
4. [天面ユニットの組み立て](../左手用/4_天面ユニット.md)
   - （別売）ホイール付き天面ユニットの組み立て（左手用）（このページ）
5. [追加ユニットの組み立て](../左手用/5_追加ユニット.md)
6. [全体の組み立て](../左手用/6_全体の組み立て.md)
7. [カスタマイズ](../左手用/7_カスタマイズ.md)
8. [その他](../左手用/8_その他.md)

## 内容品

||部品名|数||
|-|-|-|-|
|1|メインボード|1|FR4|
|2|スイッチプレート|1|FR4|
|3|保護プレート|2|アクリル|
|4|M2ネジ（短）|6|4mm|
|5|M2ネジ（中）|4|6mm|
|6|M2スペーサー（短）|2|8mm|
|7|M2スペーサー（長）|4|16mm|
|8|ピンヘッダ|1||
|9|MXスイッチソケット|21||
|10|ダイオード|27||
|11|ホイールエンコーダー|2||

以下の3Dプリンター製部品も使います。


### キット以外に必要なもの
|部品名|数||
|-|-|-|
|[キースイッチ](https://shop.yushakobo.jp/collections/all-switches)|21|Cherry MX互換|
|[キーキャップ](https://shop.yushakobo.jp/collections/keycaps)|21|Cherry MX互換|

## はんだ付け
ホイール付き天面ユニットは表裏両方に部品をはんだ付けします。


### （オプション）LEDのはんだ付け（裏面）
すべて発光面が向こう向きになります。

> [!CAUTION]
> 場所により向きが異なります。

### ダイオードのはんだ付け（裏面）
裏面にD1からD27までダイオードを差し、表ではんだ付けして足を切ります。

### MXスイッチソケットのはんだ付け（裏面）
裏面にピンセットで押し付けながらハンダごてに乗せたはんだを流し込みます。

両側をはんだしてずれなくなったらピンセットからはんだに持ち替えて追加で流し込みしましょう。  表面積が広く多めのはんだが必要です。

### ピンヘッダーのはんだ付け（裏面）
40ピンヘッダーから7ピンを2本切り出して裏面に立ててはんだ付けします。長い方を差し込みます。



### ホイールエンコーダーのはんだ付け（表面）
エンコーダーの裾のプレートを少し広げます（ショートを防ぐため）。

基板の四角マークに合わせてホイールエンコーダーを差し込み裏面をはんだ付けします。

M2ネジ（短）でスペーサー6つを止めます。真ん中に短いスペーサーを使います。


## 仮組みとソケットのはんだ付け
ベースユニットにピンソケットを取り付けていない場合、ベースユニットで余ったピンソケットから7ピンを2つ切り出して側面ユニットのピンソケットに差し込みます。


支柱に天面ユニットを差し込み、M3ネジで止めます。  ベースユニットの横長のスルーホールにピンソケットの足が入るようにします。

ベースユニットの裏面でピンソケットをはんだ付けします。

スイッチプレートを挟み込むようにキースイッチを取り付けます。


ホイールの部品を組み合わせます。細い方の軸は方向に気をつけてください。

少し力が要ることがあります。中くらいの軸はどちらからでも大丈夫です。


ホイールをホイールエンコーダーに差し込み、保護プレートをM2ネジ（中）で固定します。

USBを繋いで動作確認をします。

追加ユニットは必須ではありません。取り付ける場合は追加ユニットの説明に、取り付けない場合は全体の組立てに進みます。

5. [追加ユニットの組み立て](../左手用/5_追加ユニット.md)
6. [全体の組み立て](../左手用/6_全体の組み立て.md)

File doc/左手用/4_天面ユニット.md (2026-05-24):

# Killer Whale　天面ユニット 左手用ビルドガイド （[右手用](../右手用/4_天面ユニット.md)）

1. [スタートページ](../../README.md)
2. [ベースユニットの組み立て](../左手用/2_ベースユニット.md)
3. [側面ユニットの組み立て](../左手用/3_側面ユニット_トラックボール.md)
4. 天面ユニットの組み立て（左手用）（このページ）
   - [（別売）ホイール付き天面ユニットの組み立て](../左手用/4_ホイール付き天面ユニット.md)
5. [追加ユニットの組み立て](../左手用/5_追加ユニット.md)
6. [全体の組み立て](../左手用/6_全体の組み立て.md)
7. [カスタマイズ](../左手用/7_カスタマイズ.md)
8. [その他](../左手用/8_その他.md)

## 内容品
    
||部品名|数||
|-|-|-|-|
|1|メインボード|1|FR4|
|2|スイッチプレート|1|FR4|
|3|ダイオード|30||
|4|ピンヘッダ|1||
|5|MXスイッチソケット|24||

## はんだ付け
天面ユニットは全ての部品を裏に実装します。  
  

### （オプション）LEDのはんだ付け 

> [!CAUTION]
> 場所により向きが異なります。

  

### ダイオードのはんだ付け
D1からD30までダイオードを裏から差し、表ではんだ付けして足を切ります。  
 
### MXスイッチソケットのはんだ付け
ピンセットで押し付けながらハンダごてに乗せたはんだを流し込みます。  
 

### ピンヘッダーのはんだ付け
40ピンヘッダーから7ピンを2本切り出し、裏面に立ててはんだ付けします。長い方を差し込みます。   
   
 

### 仮組みとソケットのはんだ付け
初めて天面ユニットを作る場合、ベースユニットで余ったピンソケットから7ピンを2つ切り出して天面ユニットのピンソケットに差し込みます。  
   
 
支柱に天面ユニットを差し込み、M3ネジで止めます。

> [!NOTE]
> ベースユニットの横長のスルーホールにピンソケットの足が入るようにします。

 
ベースユニットの裏面でピンソケットをはんだ付けします。
 
スイッチプレートを挟み込むようにスイッチを取り付けたらUSBを繋いで動作確認をします。
  

追加ユニットは必須ではありません。取り付ける場合は追加ユニットの説明に、取り付けない場合は全体の組立てに進みます。  

5. [追加ユニットの組み立て](../左手用/5_追加ユニット.md)
6. [全体の組み立て](../左手用/6_全体の組み立て.md)

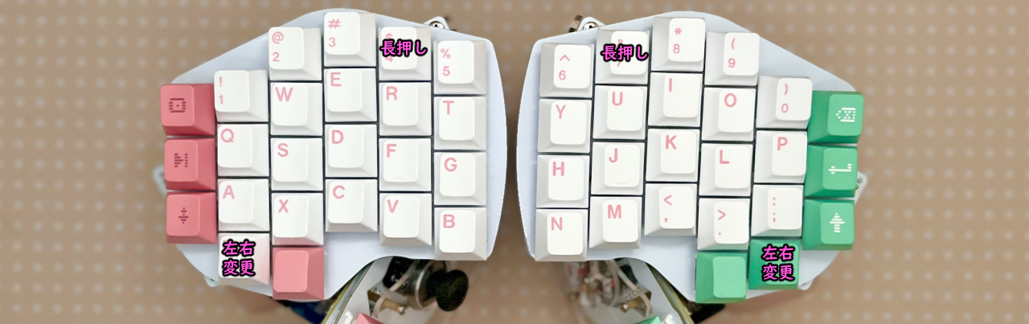
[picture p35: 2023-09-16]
doc/img/custom/lr.png

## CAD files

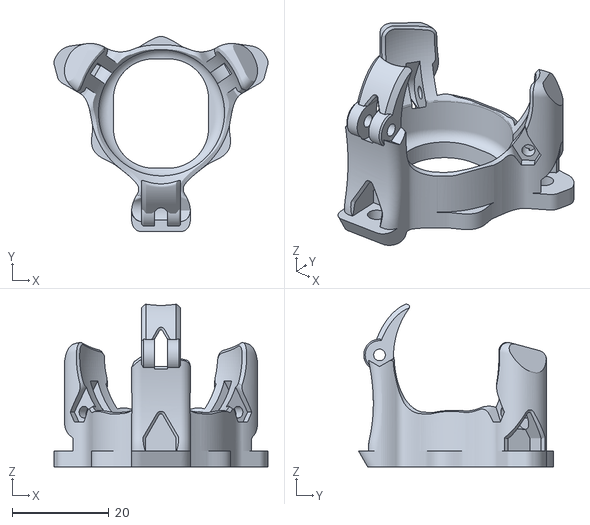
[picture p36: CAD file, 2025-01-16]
stl/Ballcase_34mm_Bearing/Integrated.stl
44.1 x 40.3 x 33.6

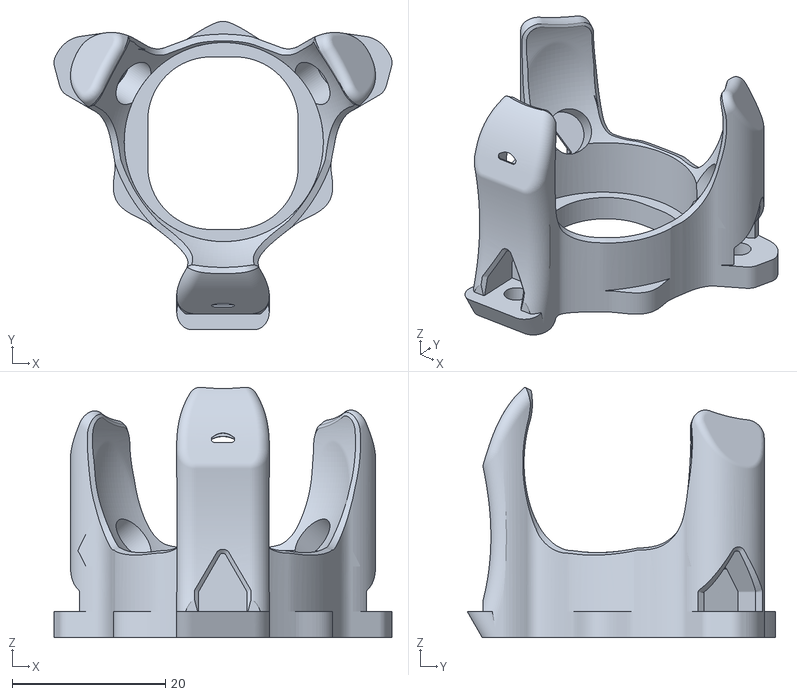
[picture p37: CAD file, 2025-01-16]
stl/Ballcase_34mm_Sphere/Integrated.stl
44.1 x 40.3 x 32.7

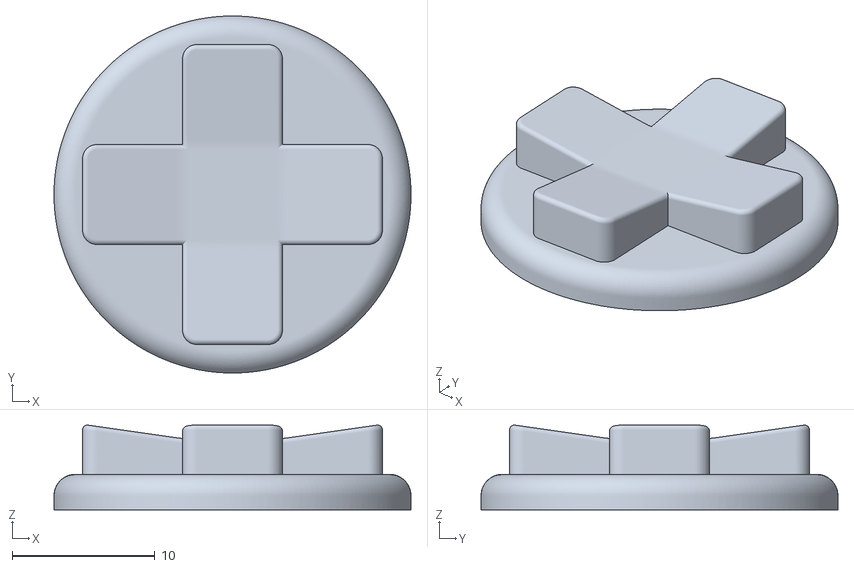
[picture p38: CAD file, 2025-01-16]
stl/D-Pad/D-Pad.stl
25.0 x 25.0 x 5.95

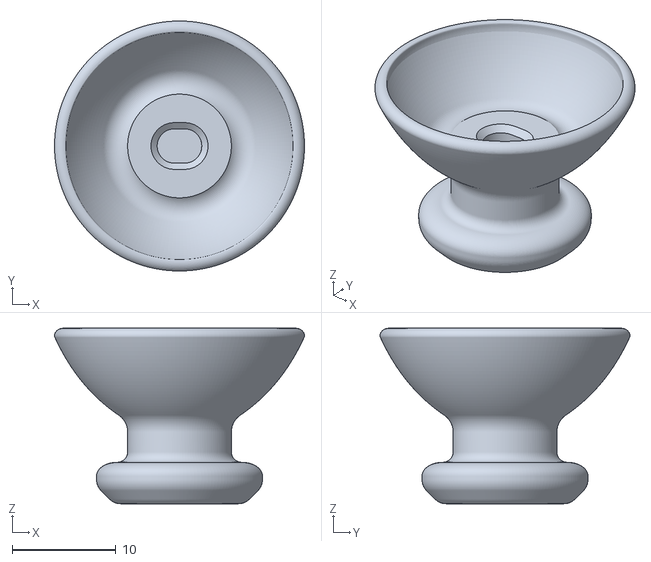
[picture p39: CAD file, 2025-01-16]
stl/Joystick/Joystick.stl
24.1 x 24.1 x 16.9

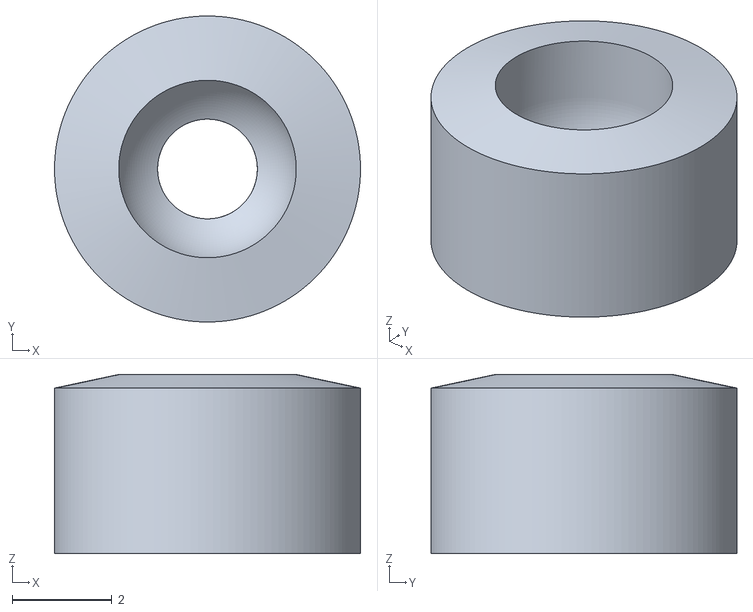
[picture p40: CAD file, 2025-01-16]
stl/Sphere_Unit/3.5mm 0.2mm nozzle.stl
6.14 x 6.14 x 3.59

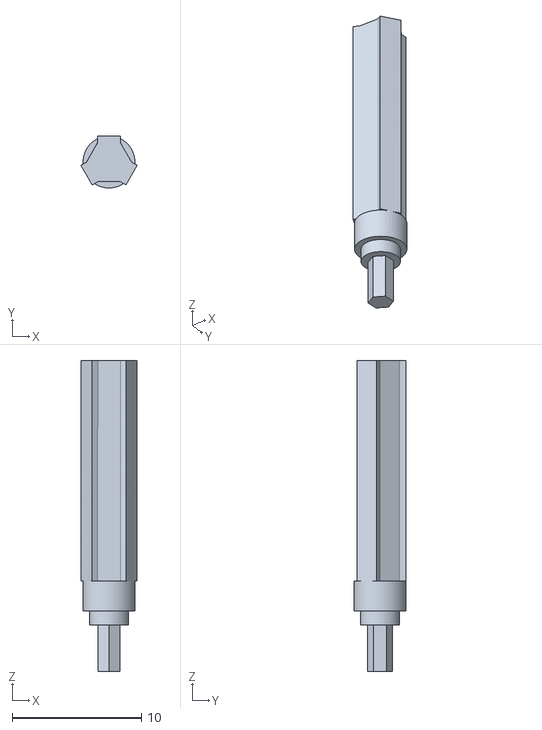
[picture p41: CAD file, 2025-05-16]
stl/Wheel/shaft1.stl
4.37 x 4.02 x 24.1

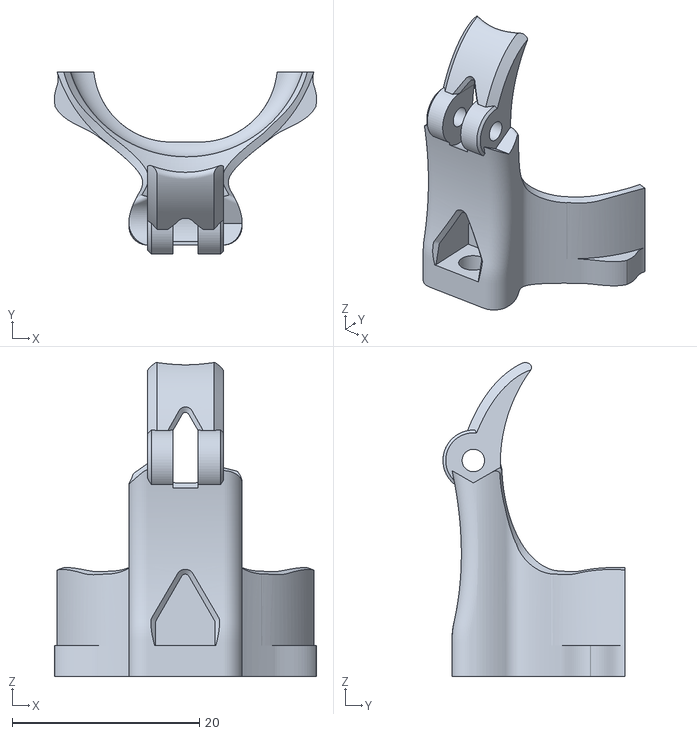
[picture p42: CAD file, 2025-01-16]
stl/Ballcase_34mm_Bearing/Separated #2.stl
28.0 x 19.5 x 33.6

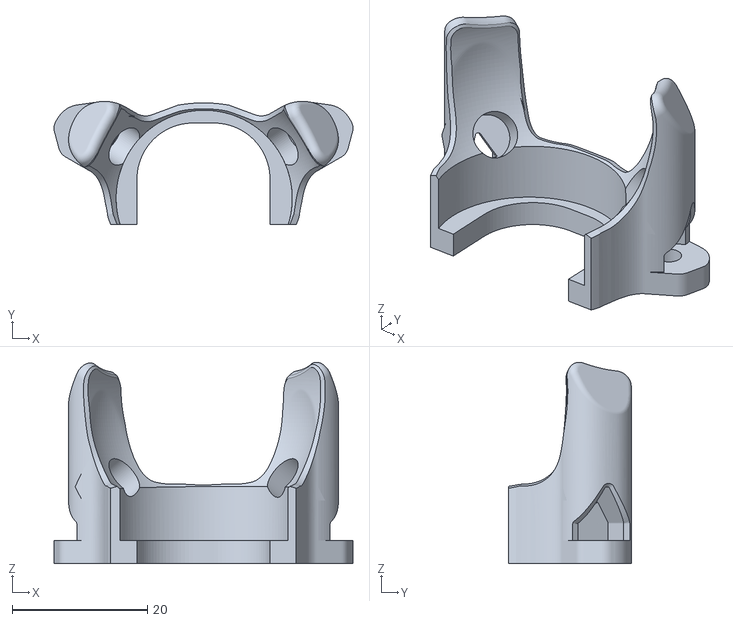
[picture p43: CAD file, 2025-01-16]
stl/Ballcase_34mm_Sphere/Separate #1.stl
44.1 x 18.2 x 29.7

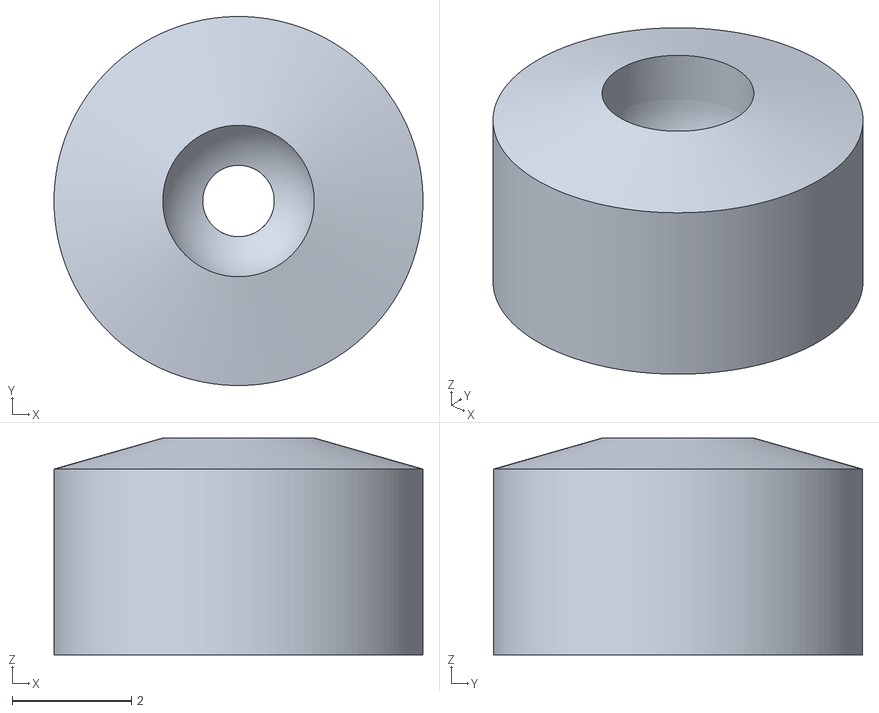
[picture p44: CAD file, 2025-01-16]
stl/Sphere_Unit/0.25mm.stl
6.20 x 6.20 x 3.64

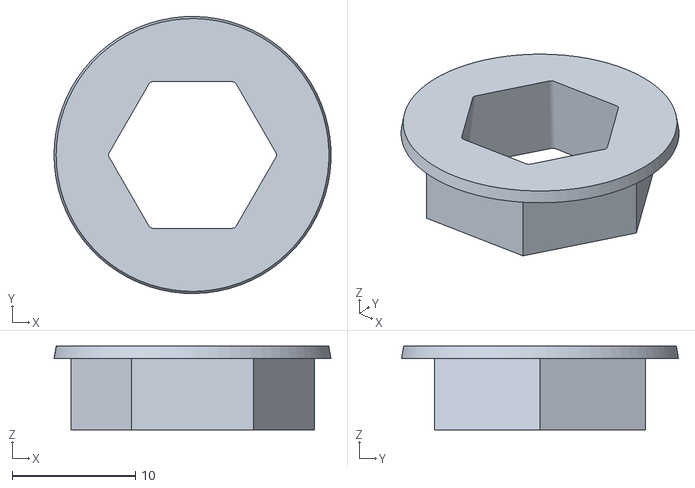
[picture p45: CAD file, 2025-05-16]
stl/Wheel/Wheel1.stl
22.5 x 22.5 x 6.80

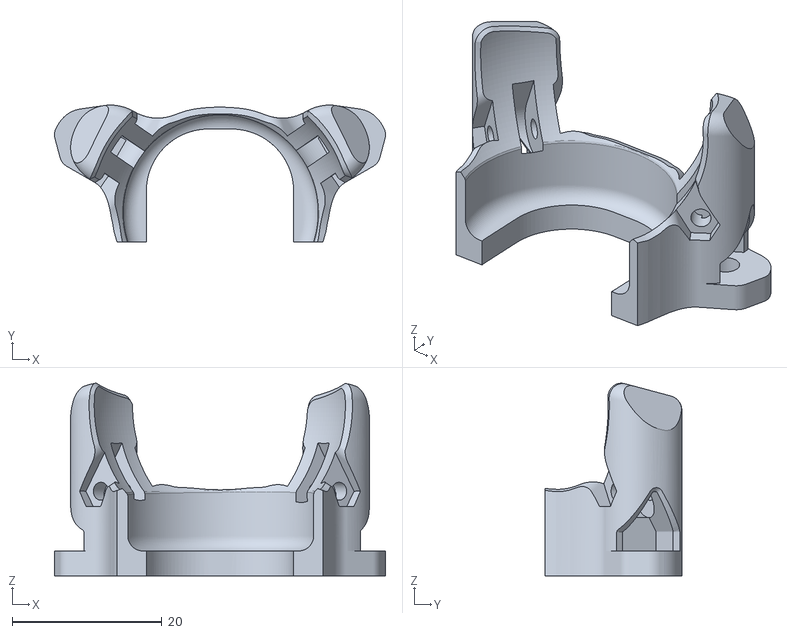
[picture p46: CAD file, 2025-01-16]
stl/Ballcase_34mm_Bearing/Separated #1.stl
44.1 x 18.3 x 25.7

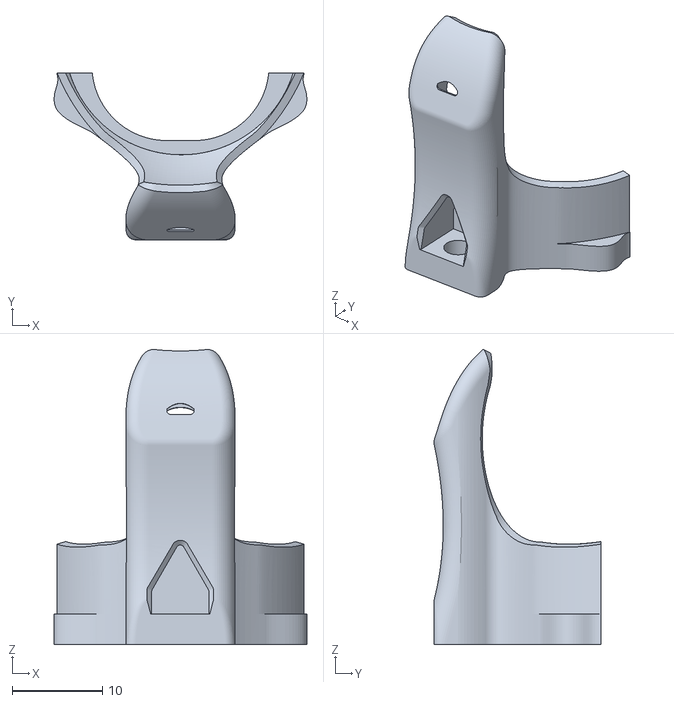
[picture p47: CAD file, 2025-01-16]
stl/Ballcase_34mm_Sphere/Separate #2.stl
28.0 x 18.5 x 32.7

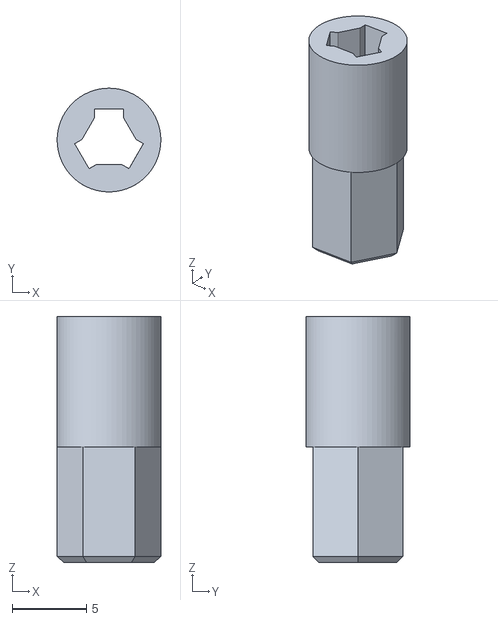
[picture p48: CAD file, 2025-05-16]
stl/Wheel/shaft2.stl
7.00 x 7.00 x 16.6

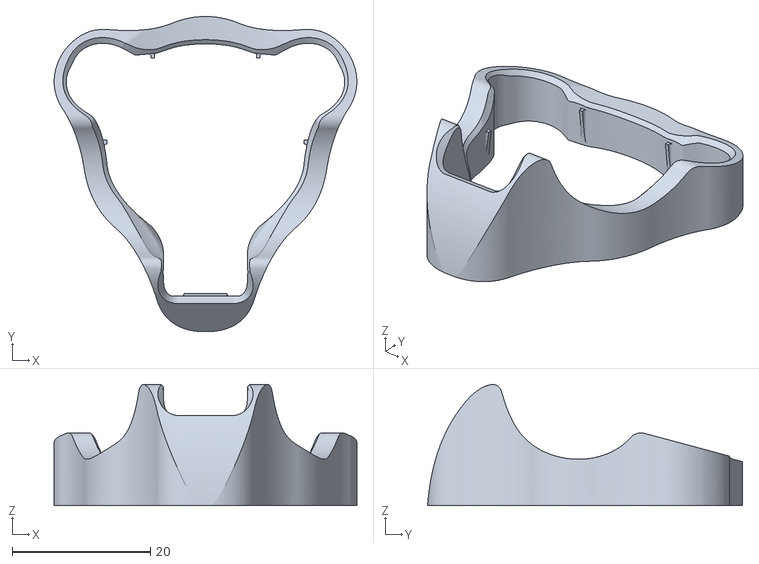
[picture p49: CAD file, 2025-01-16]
stl/Ballcase_34mm_Bearing/Cover.stl
43.8 x 45.6 x 17.5

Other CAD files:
stl/Sphere_Unit/0.3mm.stl
stl/Sphere_Unit/3.5mm 0.4mm nozzle.stl
stl/Wheel/Ring.stl
stl/Sphere_Unit/0.2mm.stl
stl/Sphere_Unit/0.3175mm.stl
stl/Wheel/Wheel2.stl

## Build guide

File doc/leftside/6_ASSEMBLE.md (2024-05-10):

# Killer Whale overall assembly LEFT Side （[RIGHT Side](../rightside/6_ASSEMBLE.md)）

1. [Start Page](../README_EN.md)
2. [BASE Unit](../leftside/2_BASE.md)
3. [SIDE Unit](../leftside/3_SIDE_TRACKBALL.md)
4. [TOP Unit](../leftside/4_TOP.md)
5. [ADD Unit](../leftside/5_ADD.md)
6. Overall assembly LEFT Side
7. [Customizations](../leftside/7_CUSTOM.md)
8. [Misc](../leftside/8_MISC.md)

## Assembly
### Assembly of the  bottom plate
Remove the bottom M3 screws, then the TOP unit by pulling out the pin headers from the pin sockets. Remove the SIDE Unit in a similar fashion.

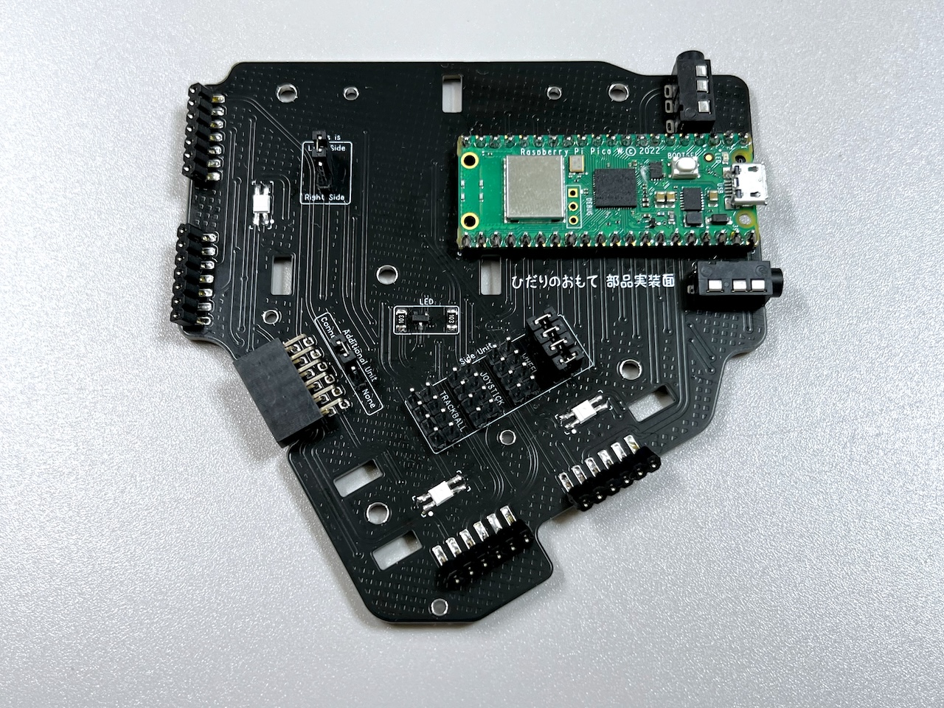
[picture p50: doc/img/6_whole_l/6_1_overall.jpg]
  

Thread 4 black washers onto 4 screws.  
  
Place the bottom plate on the back of the BASE unit, and insert the screws from the back side, and secure the screws with washers, spring washers and nuts.
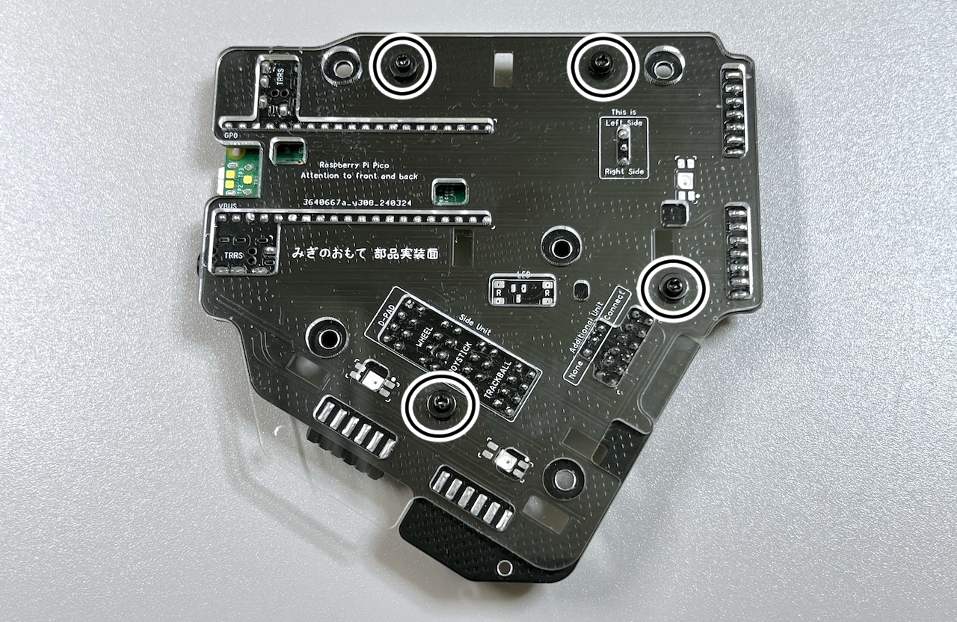
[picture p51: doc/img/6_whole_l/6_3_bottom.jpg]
  

Attach the 4 rubber feet.
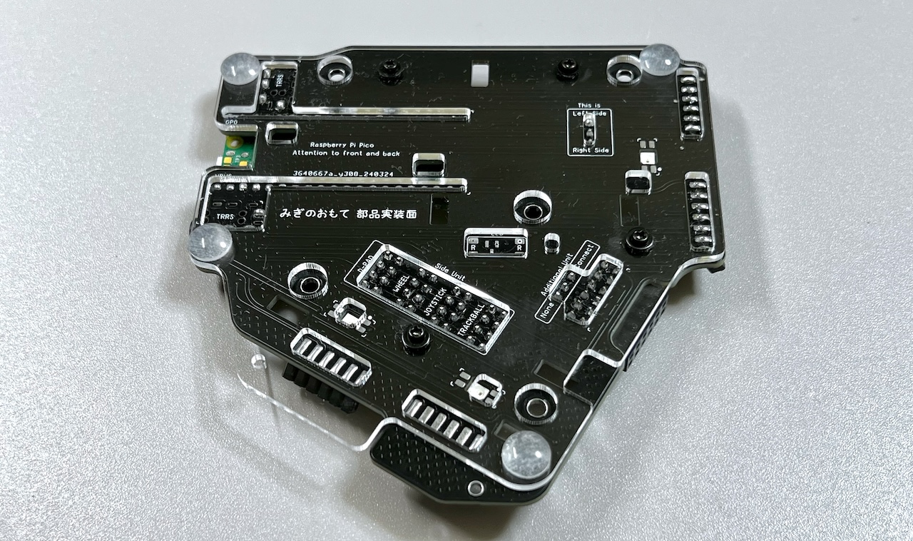
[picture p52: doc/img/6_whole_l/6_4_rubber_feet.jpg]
 

### Assembly of the ADD Unit (Optional)
Thread 3 black washers onto 3 black screws.  
  
Slide the ADD unit and insert the angle pin header into the angle pin socket.

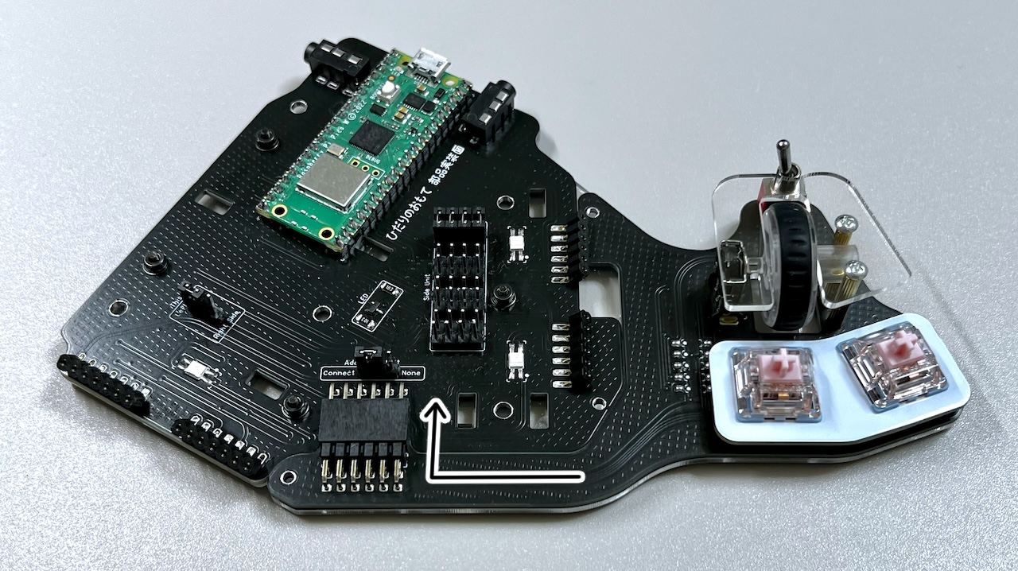
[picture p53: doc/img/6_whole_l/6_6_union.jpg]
  

Insert black M2 screws into the 3 screw holes, and secure them with washers, spring washers and nuts.

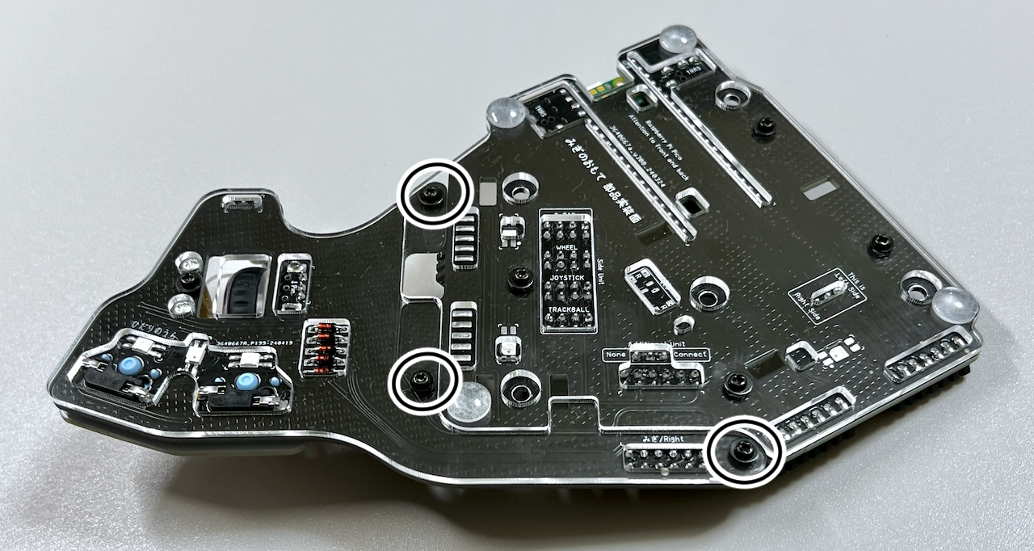
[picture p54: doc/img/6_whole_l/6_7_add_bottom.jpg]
  

Attach the rubber feet.
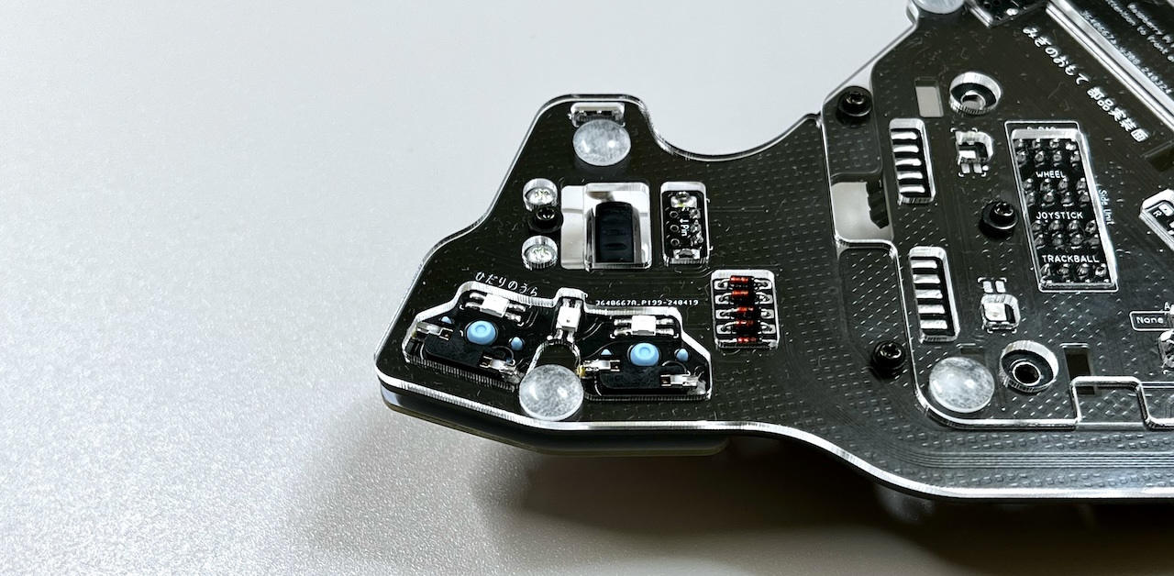
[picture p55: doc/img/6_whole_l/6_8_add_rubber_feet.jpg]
  

Confirm that everything is working by connecting the unit to a computer with a USB cable. 
> [!NOTE]
> The LEDs will only work if the TOP unit is connected.  
> The direction of the scrolling can be configured later.

### Completion
Reattach the SIDE and TOP unit to the supports.

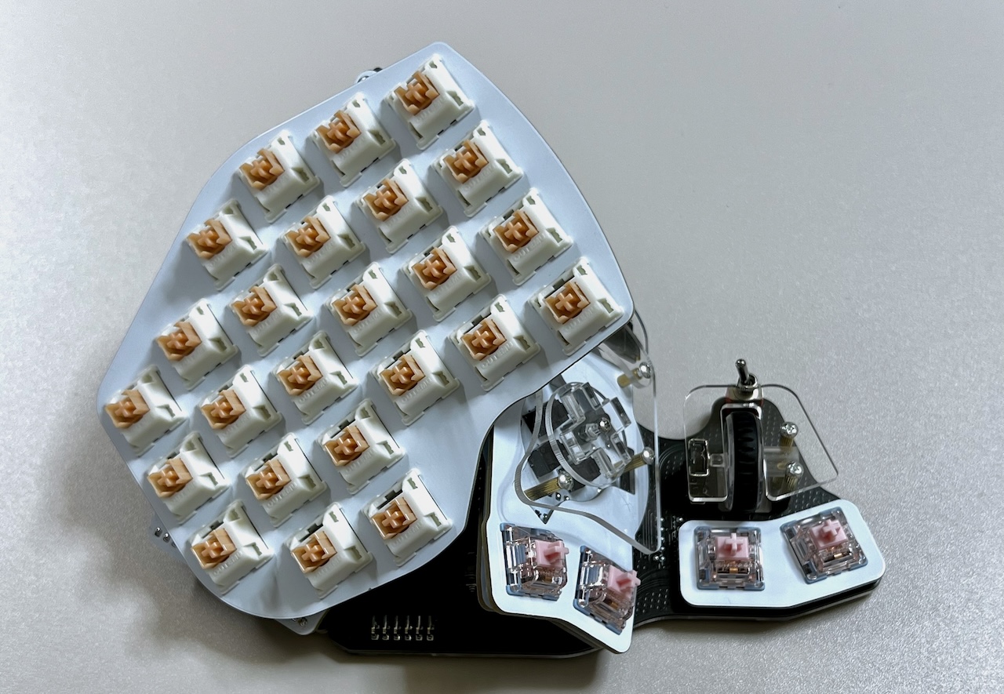
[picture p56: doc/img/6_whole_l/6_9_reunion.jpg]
  
The keyboard will be complete after placing keycaps.
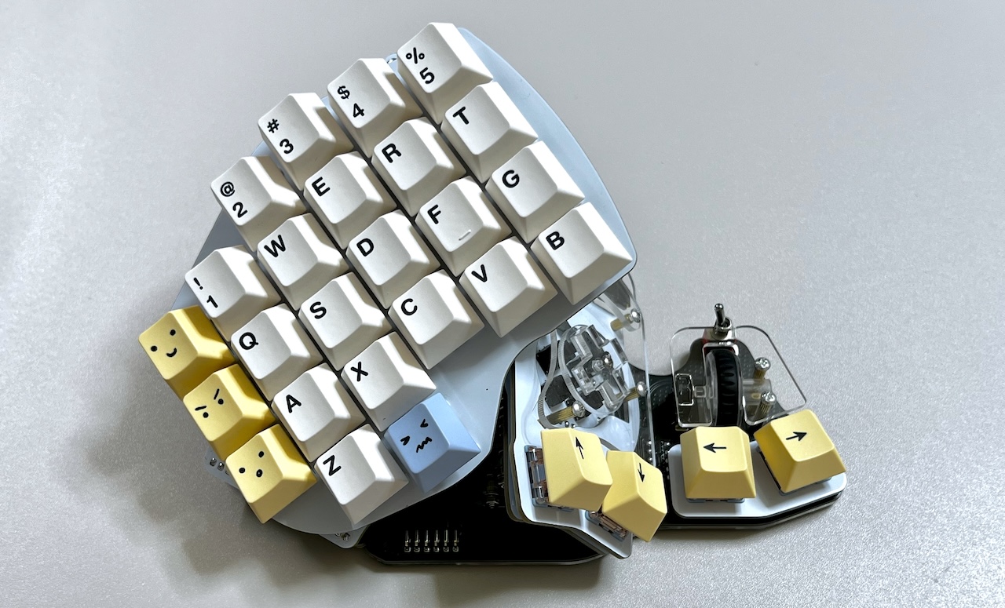
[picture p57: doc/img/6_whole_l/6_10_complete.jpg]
  
Good job!
Next, proceed to the guide for key settings.

7. [Customizations](../leftside/7_CUSTOM.md)

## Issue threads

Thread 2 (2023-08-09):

Build guide picture incorrect

ykz89, 2023-08-09:
In [this part](https://github.com/Taro-Hayashi/KillerWhale/blob/main/leftside/3_SIDE_DPAD.md#assembling) of the build guide, I believe the example is incorrect for the left hand side.
The PCB should be flipped horizontally and the acrylic part accordingly.

Taro-Hayashi, 2023-08-09:
I'm sorry. Fixed.
thanks for telling me. I hope it is not irreparable.

ykz89, 2023-08-09:
Thanks, I was able to correct it. I just wanted to point it out to remove the confusion for future builders.

Closed 2023-08-09.

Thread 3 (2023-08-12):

側面ユニット支柱の形状について

nerinanarine, 2023-08-12:
部品番号③「側面ユニット支柱」についてです。
私の購入したキットでは、側面ユニット支柱と思われるアクリルパーツが４つ入っていたのですが、よく見ると、４つの内３つが全く同じ形状で、一つだけ異なる形状のアクリルが入っていました。
※したがって、[この手順](https://github.com/Taro-Hayashi/KillerWhale/blob/main/%E5%B7%A6%E6%89%8B%E7%94%A8/2_%E3%83%99%E3%83%BC%E3%82%B9%E3%83%A6%E3%83%8B%E3%83%83%E3%83%88.md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)から先に進めていません。

ガイドの写真では、側面ユニット支柱は２種類あるように見えるため、本来であれば２種類のアクリルが２つずつ入っているのが正解かと思います。

このままだと組みあがらないため、アクリル不足しているアクリルだけ購入させていただけないでしょうか？

Taro-Hayashi, 2023-08-12:
ご不便をおかけして申し訳ありません。すぐに不足分を発送いたしますのでお手数ですがメールかTwitterのDM、BOOTHのメッセージで送付先と側面ユニットの大小どちらが1つしか入っていなかったかを教えていただけないでしょうか。よろしくお願いいたします。

nerinanarine, 2023-08-12:
早々の返信、ありがとうございます。
たった今、Twitterでフォローしました。
お手数ですが、フォローバックお願いします。

相互フォローでないと、メッセージが送れないようです。。。

Closed 2023-08-12.

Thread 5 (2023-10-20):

[🐜 Bug Report]  The Raspberry Pi post/holes are too small.

kcw-gruntsoftware, 2023-10-20:
## Problem

The instructions ask the maker to add the jumper headers prior to soldering the Raspberry Pi.  The problem is the jumper headers are **too big** for the holes in the board.

The header jumper posts are standard in size (0.64mm x 0.64mm) but even the header posts provided are too big for the board holes which are roughly 0.8mm. The hole should be:

`Radius: (640^2 + 640^2 ) ^(1/2) = 0.905mm
`

As a result, the posts are so big they managed to come out of the board

| Board Post |
| ----------- |
|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|

kcw-gruntsoftware, 2023-10-21:
cc: @Taro-Hayashi

Taro-Hayashi, 2023-10-21:
As I answered in my message to BOOTH, the hole is narrower than usual to conthrough, and I will sell you a replacement if you need one.
You have also inquired to YushaKobo, but it is not good to inquire about the same matter in many different directions.
If you don't pull it out forcibly, there should be no problem. I'll close this thread.

kcw-gruntsoftware, 2023-10-21:
Hi @Taro-Hayashi ,
I bought two halves and the problem exists with both. I think the issue is the board needs a re-design so that the RPi or the header jumper can easily fall into the holes.  All of the other contact/holes fit perfectly and the components were a delight to add to the board.

As of now, I have had to desolder and destroy 2 RPis because the contacts dont connect to the holes and don't complete the circuit.   The picture in the provided in this issue was because the post of the header was stuck in the too-small hole. Even when gently pulling the jumper and RPi, the lead came up.

Since this is a design fault, I hope you can send the replacement boards directly at no charge  as you have done so in other cases.

Closed 2023-10-21.

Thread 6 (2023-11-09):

Used the female header pins in the wrong spot...

klevermonicker, 2023-11-09:
So I sockets the RP2040 onto the BASE unit, thinking that's what was I supposed to do, and now I can no longer connect any of the modular pieces since I used that on the RP2040's (Part 19 on the base guide picture). Where can I get replacement sockets like this?

The part in question is #19: [here](https://github.com/Taro-Hayashi/KillerWhale/raw/main/img/base/IMG_4724.jpg)
I've purchased several other options and none are big enough to handle the square pins of the headers.  Can someone point me to the correct part?

Taro-Hayashi, 2023-11-10:
Hi,  this one is compatible with the pin headers included. But I cannot say with certainty that it can be used because of its different shape.
https://ja.aliexpress.com/item/1005004945845785.html
Please note that the height is 3.5mm.

Alternatively, you might use a pin header that fits your pin sockets.

I would charge you for shipping, but I could send you a bundled package, so please let me know if you need it.

klevermonicker, 2023-11-13:
Thank you, I ended up desoldering the original sets and using them and putting one of my sets of sockets in place of the original. Thank you for the help and offer!!

Closed 2023-11-11.

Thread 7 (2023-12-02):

側面ユニット支柱の形状に関して

ABC10946, 2023-12-02:
支柱部品の側面ユニット支柱の形状が、本リポジトリに添付されている画像のものと異なっていることを確認しました。
このため交換をお願いいたします。

以下リンクの部品番号3番目が異なります。
https://github.com/Taro-Hayashi/KillerWhale/blob/main/%E5%B7%A6%E6%89%8B%E7%94%A8/2_%E3%83%99%E3%83%BC%E3%82%B9%E3%83%A6%E3%83%8B%E3%83%83%E3%83%88.md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

以下がエラー品と思われる部品です。
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

ご確認よろしくお願いいたします。

ABC10946, 2023-12-02:
ご返信ありがとうございます。
現行品と形状が少し異なっていたのですね。
どこかに注記してあったのでしたら、このような問い合わせをしてしまい申し訳ありません。
同種4つということはありませんので問題ありません。
ご回答ありがとうございました。

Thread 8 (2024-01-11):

Electrostatic Discharge Damaged PCB

amknopes, 2024-01-11:
Hey! I was using my duo killer whale keyboard, and experienced a static shock on the metal toggle switch. After that, many of the keys don't work anymore. Some keys are always pressed, some don't work at all, some send the wrong keycode, and some activate multiple other keys. Can you add electrostatic discharge protection to the PCB?

Taro-Hayashi, 2024-01-12:
Hello, I hope you are not injured. I'm leaving the circuit protection to the Raspberry Pi Pico, any ideas?

amknopes, 2024-01-12:
I'm not hurt at all, thanks for your concern <3
The damage would've happened between the toggle and the Raspberry Pi Pico. I think something as simple as connecting the toggle's metal to a diode-protected ground would work. Electrostatic discharge just needs a ground path to discharge into so that all the current doesn't go into the rest of the PCB. All the other components should be alright since the toggle is the only one that gets touched with regular use

Taro-Hayashi, 2024-01-16:
The outer metal part and the foot were not conducting, so I disassembled it and found it insulated. I don't think grounding in this condition will help much.
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
There is a 5-pin part that has legs on the case, but considering that the bottom acrylic also needs to be modified, it may be difficult to change it now.
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
I apologize for not being able to meet your request. We will continue to consider the possibility.

If you need the base unit board to replace the Raspberry Pi Pico, please contact me by email or BOOTH message so I can send it to you at your expense.
Thank you.

amknopes, 2024-01-22:
Wow that's fascinating. The shock must've traveled from the casing through the air then.

I definitely want to purchase another board. Since one keypress is registering as multiple for some keys, I suspect the damage might be in the top unit. Is there electrical testing I can do to determine whether the damage is in the base unit or top unit?
Where can I find your email?

Taro-Hayashi, 2024-01-23:
here is my email. rinarinapokegogo at gmail.com. Please let me know the country name and I will calculate the shipping cost and get back to you. Payment will be made by paypal.

Registering keypresses as multiple may be found by examining the diode or path with a tester. I'll send you both the top and base PCBs, though I'll ask for more details if you need help figuring out the cause. And Please keep the switch plate and acrylic parts.

Closed 2024-01-18.

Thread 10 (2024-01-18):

ソースコードダウンロード

Rookie-999, 2024-01-18:
お世話になります。プログラム初心者です。
商品購入し、ソースコード(キーマップ)をいじりたく、qmkファームウェアをダウンロードしたいのですが、どこからダウンロードすれば良いでしょうか?
パスワードを一つのボタンに設定して、そのボタンを押されればパスワードを入力完了としたく、ダウンロード方法をご教示頂けますと幸いです。

宜しくお願い致します。

Taro-Hayashi, 2024-01-18:
ソースコードはこちらに公開しています。
https://github.com/Taro-Hayashi/qmk_firmware/tree/tarohayashi/keyboards/tarohayashi/killerwhale/
QMKにつきましてはこちらに導入手順がありますのでご覧ください。
https://docs.qmk.fm/#/ja/newbs_getting_started

Rookie-999, 2024-01-18:
お世話になっております。
試したのですが、この商品のソースコードが入っていませんでした。
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
git clone https://github.com/Taro-Hayashi/qmk_firmware.git と入力してもソースコードは無く、どのようにすれば解決出来るかわかりません。
お手数おかけし申し訳御座いませんが、ご助力頂けますと幸いです。

宜しくお願い致します。

Taro-Hayashi, 2024-01-18:
ソースコードが入っているのはtarohayashiブランチになっています。通常のcloneではmasterブランチになっておりますのでブランチを切り替えてみてください。よろしくお願いいたします。

Rookie-999, 2024-01-18:
何度も申し訳御座いません。
ブランチの切り替えがうまくいかないようで、ソースコードが入手出来ません。
プログラム初心者で理解出来ておらず申し訳御座いません。

どこで切り替えを行えば良いでしょうか?

宜しくお願い致します。

Taro-Hayashi, 2024-01-18:
cloneでダウンロードしたディレクトリに移動して「git checkout tarohayashi」で切り替わると思います。直接ZipファイルをダウンロードしていただくかGitHubデスクトップをお使いいただくこともできます。
申し訳ありませんがGitやGitHubの使い方、コンパイル方法につきましては解説しているサイトをご参照いただければと存じます。よろしくお願いいたします。

Rookie-999, 2024-01-18:
お世話になっております。
ご教示有難う御座います。切り替えが出来ました。
お手数おかけし申し訳御座いませんでした。とても助かりました。

宜しくお願い致します。

Rookie-999, 2024-01-18:
お世話になっております。
何度も申し訳ございません。
mysysでmakeしたのですが、hexファイルは作成されませんか？

Closed 2024-01-18.

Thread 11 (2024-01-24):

右手デバイス側がうまく機能しない

Okamoto0y, 2024-01-24:
初めまして、こちらのキーボード購入者です。
問題が起きているので、質問させて下さい。

■起きている事象は
右手デバイス（トラックボールVer）を接続した際に、なぜか左手デバイスを反転したキーマップになります。
有線で左手デバイスを接続しても反応しません。

左手デバイスを接続した際は、右手デバイスだけが反応しない状況です。
すべての設定や接続方法などを確かめたのですが、わからず、、、、

ちなみに、HP記載の「a」が表示されるのかの動作確認もして挙動は問題ないということはわかっております。

■解消方法について
ラズパイを初期化して改めてファームウェアをDLすれば治りますかね？
ラズパイTYPE Cのものを利用しておりどのように初期化すればも分からなかったので対応方法もご教授いただけると幸いです。

Taro-Hayashi, 2024-01-24:
>ラズパイを初期化して改めてファームウェアをDLすれば治りますかね？

わかりません。

>ラズパイTYPE Cのものを利用しておりどのように初期化すればも分からなかったので対応方法もご教授いただけると幸いです。

お使いのマイコンボードの製品情報をご確認ください。

ベースユニットのジャンパーでの左右の指定にお間違えはないですか？
また、右手に片手用のファームウェアが書き込まれている可能性もあるので両手用のものを上書きすることもお試しください。

Okamoto0y, 2024-01-25:
ご回答ありがとうございます。ご提案いただいた内容をもとに対応しますので、もしそれでも解消されなかった場合また相談させて下さい。

Okamoto0y, 2024-04-04:
こちらジャンパーを修正しましたがやはり、
・トラックボール
・TRSSケーブルの接続がうまくいきませんでした。

基盤の初期不良でしょうか？

Taro-Hayashi, 2024-04-04:
ご提示の条件からは判断いたしかねますが目に見えて傷などがない限り基板が初期不良品である確率はとても低いです。別のスレッドでもお伝えしましたが交換用の基板の販売は可能なので必要な部位があればご連絡ください。

Closed 2024-01-31.

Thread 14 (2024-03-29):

Led not working

fernando-vasconcellos, 2024-03-29:
I recently bought this product, flashed the necessary uf2 and even though the keys are working, the leds are not lighting up.
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

In there you can see that is not consistent, also the connection between the top part and the rest of the board is done by those cables to be able to test stuff, but when it was fully assembled the situation was the same.
I tested the electric connection on the leds and they are connected.

How could I fix this?
Also, I would appreciate it if you would upload the schematics, since that could give me more insight on the path to follow

Taro-Hayashi, 2024-03-29:
Hi, fernando. Thank you for purchasing.
The LED that is glowing is connected to the LED in the upper left corner. It is connected as shown in the image.
If that path, 5V, and GND are the correct voltages and it does not glow, the LED may be damaged and may work if replaced.
I've uploaded a schematic for your reference.
https://github.com/Taro-Hayashi/KillerWhale/releases/download/0.23.0/scheme_killer_whale.zip
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

NandoVasconcellos, 2024-03-29:
Thank you very much! I will definitely try this once I'm back :)
And also, big thank you for the schematics :)

NandoVasconcellos, 2024-04-01:
Hey, I wanted to follow up on this.
I've been testing with a multimeter and I didn't find a problem with any led. I've been also using the others side top piece and it only lights up the 23th.
At this point I'm a little bit desperate, Any idea? :(

NandoVasconcellos, 2024-04-02:
So, I've tried to change the firmware, reset completely the raspberry pi, I also changed the position of the jumpers just in case I made a mistake (that's why in the photo you see the jumper in "none" position).
Nothing of this worked so far.

Taro-Hayashi, 2024-04-03:
The LEDs are connected in series and the Raspberry Pi Pico decides how many LEDs to light up. Therefore, if the LEDs stop emitting light in the middle of a sequence, it means that the LEDs are not electrically connected or the number of LEDs is incorrectly specified.
If you have checked with a multimeter and there is no problem with the electrical connection, and you are using the firmware that I distribute, then the LEDs that are not glowing may be faulty. However, if the same phenomenon occurs on another top plate, it means that the LEDs in the same location have failed by chance, which is a bit unlikely.
This is not a solution, but if you need something in the form of a circuit board or parts, please contact me by DM on twitter(X) or email as I will ship it to you for about the manufactual cost and shipping.

fernando-vasconcellos, 2024-04-05:
Could you give me your email?
Or, if you prefer, this is mine fgvn18@gmail.com

I would be happy to request both top and base because neither of them are working, I've tried everything, even changing one of the raspberry pi pico with a brand new one and still, malfunctioning.

Taro-Hayashi, 2024-09-10:
Hi, I have received the amount and am working on it. I was going to contact you after it was shipped, but it is taking longer than expected. Sorry for the anxiety.
Thank you.

Closed 2024-03-29.

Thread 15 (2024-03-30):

新たな問題が、、、

Okamoto0y, 2024-03-30:
TRASSケーブルを接続してもUSBを繋いでいない方が認識しないのはどうしたらいいでしょうか？
またTrackBallが認識しないのですがどうしたら改善しますか？基盤やハンダは全て修正したのですがうまく行かず、

Taro-Hayashi, 2024-03-30:
ちょっとそれだけだとわかりませんが導入されているファームウェアが左右接続用でないということはありませんか。トラックボールが認識されないのはベースユニットのジャンパーの指定が間違っている可能性があります。あとは基板や部品の故障でしょうか
交換用の基板の販売は可能ですので必要な場合はどのユニットが必要かをメールかBOOTHのメッセージにご連絡ください

Okamoto0y, 2024-03-31:
ご回答ありがとうございます。

■ファームウェアについて
ファームウェアは、ご準備いただいている
左右分割 右手ボール [tarohayashi_killerwhale_duo_ballright.uf2](https://github.com/Taro-Hayashi/KillerWhale/releases/latest/download/tarohayashi_killerwhale_duo_ballright.uf2)
こちらをDLして割り当てております。

割り当ての際は、
・TRSSケーブルを抜いた状態でBOOTSELボタン押下した状態でケーブルを接続
・DLしたファームウェアをドラッグ。これを左右どちらにも実施で行っております。

こちらの方法は、問題はなさそうでしょうか？

ちなみにUSBでどちらも接続したらPCには認識されますね。
どうしてもTRSSを繋ぐと認識しなくなります。ケーブル買ったばかりですが、初期不良ですかね？

■トラックボールについて
基盤上にある「TARACKBALL」の箇所にジャンパーの指定はしているのでこちらも問題ないかとは思います、、、、
トラックボールがジャンパーを触ると、認識はするようになりましたが
カクカクと画面の下にジャンプしてネット環境が重いときのマウスのようになります。
これはREMAPとかで修正できたりするんでしょうか？

Taro-Hayashi, 2024-03-31:
ご利用のファームウェアや更新方法は問題ないですね。テスト用のファームウェアも使ってみてください。
ケーブルの不良かどうかはテスターで両端の導通を調べたりオーディオに繋いで音楽を聞いてみる、他のキーボードで使ってみる等で検証できます。
ジャンパーを触ると認識するようになるということはジャンパーの接触に問題があるかもしれません。その症状ですと
Remapとは無関係で、ジャンパーの接触不良で飛び飛びになっているかセンサーが故障してる可能性があります。
メイン基板やラズパイが故障した可能性もあると思います。

Okamoto0y, 2024-03-31:
承知いたしました。では下記の方法試してみます。
・初期化を行い、テスト用のファームウェアを導入して動作確認も行ってみます。
・TRSSに関してはスピーカーなどで試してみます

・上記でダメな時、ジャンパーを購入して調査
　→ これでも解消できない場合は、基盤だと考えれるので、基盤購入します。

メイン基盤の購入の場合はどのように行えばいいでしょうか？

Taro-Hayashi, 2024-03-31:
BOOTHで販売いたしますので必要になりましたらご連絡ください。

Okamoto0y, 2024-03-31:
承知いたしました！TRSSケーブルの不備はないことを確認しました

テスト用のファームフェアを導入したのですが、それでもやっぱりトラックボールの反応が悪いですね、、、、
ジャンパー購入して動作確認します

Amazonで2mm、2.54mmどちらを購入したらいいとかありますか？

Taro-Hayashi, 2024-03-31:
2.54mmです。

Okamoto0y, 2024-03-31:
承知いたしました。ありがとうございます。
では一旦こちらクローズしていただき購入が必要になった際に改めてご連絡させていただきますのでよろしくお願いします。

Closed 2024-03-31.

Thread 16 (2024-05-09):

オートマウス機能の移行、復帰の感度値の設定機能

tmyymmt, 2024-05-09:
とても良いキーボードのキット公開、ありがとうございます。この仕組みで立体にするのも凄い発想だと思いました。
左をジョイスティック側面ユニット、右をトラックボール側面ユニットで、2台を繋げて左右分割キーボードとして使用しています。
左のジョイスティックは普段は十字キー動作で、たまにマウス動作に切り替えて使っています。

さて、トラックボールを動かしたときに一時的にLayer7に切り替わるオートマウス機能について、最近のファームウェアだとF(J)キーを押してもクリックとして認識されないことが多くなり困っています。

確か、[0.23.0](https://github.com/Taro-Hayashi/KillerWhale/releases/tag/0.23.0)くらいまではトラックボールを動かした後に少し長い時間があった気がするのですが、[0.23.9.1](https://github.com/Taro-Hayashi/KillerWhale/releases/tag/0.23.9.1)では少しも時間がないようになった気がします。
また、[0.24.7](https://github.com/Taro-Hayashi/KillerWhale/releases/tag/0.24.7)では、トラックボールを動かした時にLayer7に切り替わるまでに必要な移動量（時間？）が大きくなった気もします。

オートマウス機能の、Layer7への移行と、Layer7からの復帰の、感度（移動量か時間の閾値？）を微調整できるようになりますでしょうか？

よろしくお願いいたします。m(_ _)m

Taro-Hayashi, 2024-05-10:
こんにちは、オートマウスにつきましては設定項目がいくつかあり、レイヤーを切り替える移動量、切り替える時間、レイヤーが戻った後にまた変更可能になるまでの時間、マウスに関係ないキーを使った時に切り替えが起こらないようにする時間がございます。

最適な値を模索中でバージョンによって概ねおっしゃる通りの変更内容になっています。更新に伴い切り替える時間を増やしてみましたが何かご提案があればお知らせください。

現状ではキーボードを使用中にはそれらの値を変更することができず、また利用方法や好みによる部分もあるかと存じますのでよろしければファームウェアの作成もお試しいただければ幸いです。

よろしくお願いいたします。

tmyymmt, 2024-05-11:
おぉ！早速のご対応ありがとうございます！！

F(J)キーがクリックとして認識されるようになりました！

そうなんですね。使用中に変更することができないとは。そしたら動的な調整は難しそうですね。

確かにこの部分は好みだと思いますので、ファームウェアを作成して値を色々いじってみようかと。設定値のコメントもありがとうございます。助かります！
https://github.com/Taro-Hayashi/qmk_firmware/blob/tarohayashi/keyboards/tarohayashi/killerwhale/duo/config.h

もし何か上手い策が見つかりましたらご連絡いたします。

ありがとうございます！

tmyymmt, 2024-05-11:
おぉ！早速のご対応ありがとうございます！！

F(J)キーがクリックとして認識されるようになりました！

そうなんですね。使用中に変更することができないとは。そしたら動的な調整は難しそうですね。

確かにこの部分は好みだと思いますので、ファームウェアを作成して値を色々いじってみようかと。設定値のコメントもありがとうございます。助かります！
https://github.com/Taro-Hayashi/qmk_firmware/blob/tarohayashi/keyboards/tarohayashi/killerwhale/duo/config.h

もし何か上手い策が見つかりましたらご連絡いたします。

ありがとうございます！

Closed 2024-05-11.

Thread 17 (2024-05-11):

追加ユニットの左右の手順が逆だと思われる

Nnogu568, 2024-05-11:
本ビルドガイドを使ってkillerwhaleを作成しているものです。
おそらく昨日5/11あたりで手順が差し替えがされたと思っています。(細かいcommit履歴までは追っていないです。)
追加ユニットの手順
https://github.com/Taro-Hayashi/KillerWhale/blob/main/%E5%8F%B3%E6%89%8B%E7%94%A8/5_%E8%BF%BD%E5%8A%A0%E3%83%A6%E3%83%8B%E3%83%83%E3%83%88.md
例えば上記は最新の右手の追加ユニットの手順かと思いますが、以前の手順と見比べると「みぎのうら」と書かれている面と「ひだりのうら」と書かれている面ではんだ付けしている部分が異なるようにみえます。
まだ、killerwhaleを作成中なので勘違いだったらすいません。

Taro-Hayashi, 2024-05-11:
ご指摘ありがとうございます。先ほど修正いたしました。
写真が原因で組み立てに不都合が出てしまいましたら交換品を送付いたしますのでご連絡ください。

Nnogu568, 2024-05-12:
修正ありがとうございます。
組み立てには特に影響出ていませんが、作成中のためまた何かあればご連絡させてください

Nnogu568, 2024-05-18:
本件とは関係ないですがジャンパーが一つ足りず完成できませんでした。
何かご対応お願いできますでしょうか。

Taro-Hayashi, 2024-05-19:
大変失礼しました。お手数ですがメールかBOOTHのメッセージ等で送付先をお知らせいただいてもよろしいでしょうか。

Closed 2024-05-12.

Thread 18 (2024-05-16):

Possible error in diode direction on trackball unit guide

Jorres, 2024-05-16:
Hello! I apologize for texting in English, but my Japanese isn't good yet.

I'm following the right section, trackball unit page: https://github.com/Taro-Hayashi/KillerWhale/blob/main/rightside/3_SIDE_TRACKBALL.md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

I have bought a unit very recently, 1-2 weeks ago. On my part, most of the diodes have the same direction as on the part in the guide, except for the two diodes. Please have a look at these two pictures: the first picture from the guide, the second is the photo of the part that I have.

Which one is correct? I have assembled according to the markup on the part, and the right part of the keyboard doesn't work yet. I want to rule out this diode misdirection as a possible issue. Can you please confirm which one is correct?

Here is the image from the guide, I have put an arrow where the black end of the diode should go:
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

Here is the part I bought:
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

I have double-checked all the remaining build steps, checked soldering joints with a multimeter, but everything else seems to be OK. This is the only bug\lead I have :) I hope I can make it work!

Jorres, 2024-05-16:
Apologies for the pictures of slightly bad quality, for some reason my phone stopped focusing clearly enough :( I hope this will be enough for the debug.

Taro-Hayashi, 2024-05-16:
Hi, sorry for the confusion, the PCB print is correct. Please install as per the PCB print (the diode mark is in the opposite direction to C3).

This is happening because when I recently modified the PCB and build guide, I changed the orientation of the diodes because of the wiring.

The build guide for that version is here.
https://github.com/Taro-Hayashi/KillerWhale/tree/0.24.7
Trackball SIDE Unit (right side):
https://github.com/Taro-Hayashi/KillerWhale/blob/0.24.7/rightside/3_SIDE_TRACKBALL.md
Also, here is an image that shows the orientation of the relevant diode.
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

Thank you.

Jorres, 2024-05-17:
Thank you for the quick response. I was able to find my manual mistake elsewhere, not related to these diode positions. Closing the issue!

Closed 2024-05-17.

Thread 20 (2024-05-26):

Remap用ファームウェアでエラーが出る

gla66, 2024-05-26:
Remap用ファームウェアを書き込むとキーボードが認識されず、キー配置の変更や左右分割キーボードとして使用できません。
どのようにすれば解決できますでしょうか。

テスト用ファームウェアではKiller Whale Soloとしてデバイス認識されますが、
Remap用ファームウェア単体用ではPC上でドライブエラー表示がされ、
Remap用ファームウェア左右分割用ではそもそもデバイスとして認識されません。

Taro-Hayashi, 2024-05-26:
Raspberry Pi Picoの裏表はあっていますか？
また、テスト用ファームウェアはRemapに対応しておりませんので通常はデバイス選択には出てきません。ドライブエラーが表示されるとのことで正常にファームウェアがインストール出来ていない可能性がございます。お使いのPCのUSB周りに既知の不具合がないかご確認ください。ハブを用いずに直接PCに接続する、USBの差込口を変更する等していただくと違う結果が出ることがございます。
こちらの一番下、"Resetting Flash memory"にRaspberry Pi Picoのリセット方法が書いてありますのでこちらもお試しいただくと改善する可能性がございます。
https://www.raspberrypi.com/documentation/microcontrollers/raspberry-pi-pico.html
交換用の基板がご入用の場合は販売いたしますので必要なユニットをメールかBOOTHのメッセージにご連絡ください。

gla66, 2024-05-26:
ハブを使って接続していたことが原因でした。直接接続したところ、全て問題なく機能致しました。
お手数をおかけいたしました。
迅速なご回答と素敵なキーボードありがとうございます。

Closed 2024-05-26.

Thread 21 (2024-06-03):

Question about reflashing

Jorres, 2024-06-03:
Hi! Thank you for designing such an awesome keyboard. Second week in, and I'm enjoying it very much!

I would like to ask for an advice regarding flashing the firmware.

I'm writing the code for the firmware myself using QMK. I usually reflash the keyboard multiple times per day when changing something and trying something new. Because I flash very often, I would like to not break the usb port too soon (I know it is designed for ten thousand plug\unplugs, but I'm honestly a bit paranoid, the port looks very brittle).

When I recompile just the layout, I usually don't need to re-flash the slave side (there are very little cases when the slave side must also be reflashed).

Usually, to put the Pi Zero into bootloader mode, you need to unplug the cable, hold BOOTSEL (or the special bootmagic key) and plug the cable back again. I have found a way to put the Pi Zero into bootloader mode WITHOUT unplugging and then replugging the cable (using `reset_usb_boot` function from pico library, can provide code if necessary). The only question remaining is the TRRS cable.

I know I must not plug or unplug TRRS cable while the keyboard is connected via USB, this makes sense, I can short-curcuit the board. I'm not going to do that. But, can I put the keyboard into bootloader mode and flash it WITHOUT unplugging TRRS cable? In theory this must work, because it should be equivalent to just unplugging the usb cable and plugging it back in (which is safe). But I'm not willing to experiment, this is an expensive toy for me and I don't want to risk short curcuiting something. But since you designed the board, maybe you know more definite answer to this problem?

If what I'm thinking is correct, I can reflash the master-half of my keyboard as many times as I want, without unplugging either usb or TRRS cable at all. This means maximum lifespan for both usb and TRRS ports!

As a sidenote: maybe it will be useful to add some key combination that would drop the keyboard into bootloader mode? Usually people plug and unplug the cable in the first couple of days very much, surely it will be more convenient to give the option of not unplugging the cable when reflashing?

Sorry for a very long issue! :) Hope it's not too much trouble.

Taro-Hayashi, 2024-06-04:
Hi, thanks for using Killer Whale. I'm using a USB cable with a magnetic connection and did not notice the inconvenience.

Could you get into the bootloader with QK_BOOTLOADER, it is here in Remap.
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

I don't know exactly, but I always Flash with the left and right side connected with the TRRS cable and never had a problem.

I would be glad if I could help.

Jorres, 2024-06-04:
Thank you for the reply. Since you say you don't unplug TRRS cable, I also decided gave it a try, and thankfully, everything worked, I didn't need to unplug any of my cables. And since I was only reflashing the layout, I don't need to reflash the slave. This is cool, I can basically reflash my layout infinite times without ever touching the cables :)

Also confirmed that QK_BOOTLOADER works, I didn't need any custom Pico code after all. Not a big deal but -10 redundant lines of code is always nice :)

All my questions answered, closing the issue

Closed 2024-06-04.

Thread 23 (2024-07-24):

FW Version 0.24.8 losses TRSS Comms when changing RGB Colors

shiori1425, 2024-07-24:
I built my duo killer December last year. I'm currently using two d-pads with add units on both sides.
Today I upgraded the firmware to version 0.24.8 (tarohayashi_killerwhale_duo_via.uf2) on both sides.

Immediately after the firmware update things are working fine with the default config.
I then go to remap and flash my personal keyboard layout and things continue to work fine.

The problems start when I change the RGB colors, either before remap using the keyboard itself or through remap, whenever I change the leds the TRSS communications stops working. It starts getting very laggy typing across the two sides (works fine with just the usb side) and occasionally the non-usb side will just completely stops working.

Redownloading the 0.24.8 firmware fixes the issue and I don't have a big problem with the default red color but I would like to be able to change it at some point.

Any ideas why this might be happening? I don't know how to build the uf2 files to debug this myself sadly. Might just be time to learn.

Taro-Hayashi, 2024-07-24:
Not sure why if it works correctly with older firmware, but If the firmware on both hands has been updated it could be a power problem. Try connecting directly to a PC USB port without using a hub or changing the port or cable to be connected. It could also be caused by LEDs, MOSFETs, or resistors that are not soldered perfectly.
Lighting can be set not only with Remap but also with the keys on the keyboard (RGB keys in the DEVICE tab). Try that as well, and the problem may be fixed once.

shiori1425, 2024-07-25:
I don't think it's the soldering. It was working perfectly prior to updating and I do circuit board work professionally. The keyboard is not connected through a hub but direct to a usb 3.0 port on the mobo. The issue seems to not happen as much with the keyboard controls and I'll keep messing with that to see if I can get steps to reproduce the issue without using remap.app.

The issue is pretty consistently repeatable when using remap.app:
  1. Download 0.28.4
  2. Use Remap to flash my keymap
  3. Use Remap to change LED color
  4. Non-usb side stops working.
  5. Redownload the 0.28.4 uf2 and everything is working again.

Taro-Hayashi, 2024-07-25:
I can't reproduce it on my end and don't know how else to deal with it. If anyone has the same symptoms or knows how to solve it, please let me know.

shiori1425, 2024-07-30:
I can't reproduce the issue using just the default keyboard led controls. I guess the issue is with remap.app and not the firmware.

I'll close the issue here and bring this up on the remap discord.

Closed 2024-07-30.

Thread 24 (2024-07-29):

Bad or misleading instructions

asdf23, 2024-07-29:
On the page: https://github.com/Taro-Hayashi/KillerWhale/blob/main/leftside/3_SIDE_DPAD.md

The directions say:
"Insert the diodes in the 4 locations on the back side of the PCB, and solder from the front side of the PCB, and cut the diode legs. "

The image shows 8 diodes
https://github.com/Taro-Hayashi/KillerWhale/raw/main/img/3_2_dpad_l/3_1_5_diodes.jpg

And the kit comes with 5 diodes ... ?

Do I need more diodes and the instructions/picture is incorrect?

Harshadb, 2024-07-30:
(Commenting as someone who built the KillerWhale.)
You are correct, since the instructions are partly from other side units and also translated.
The trackball & wheel side units use 4 diodes. The Joystick unit uses 5. The D-Pad unit uses 8.
(The japanese version of the D-Pad instructions has the correct number: 8)
Check the other side unit packs to confirm the number of diodes.

I am sure Hayashi-san will clarify and answer you.

Taro-Hayashi, 2024-07-30:
Thanks for telling me that instructions is wrong. 8 diodes is correct.
If a kit contains only 5 diodes, it is a packaging error. I apologize again.

Depending on where you live, it may be inefficient to send only the diodes, so may I ask you to purchase 1N4148 from elsewhere? I would pay up to $0.2 each($0.6)  plus shipping.

Thank you.

asdf23, 2024-08-04:
I am so sorry, I was looking at the wrong board. It took me a while to see it. I see now that I had opened the board for the track ball.
I did order some extra diodes and in the process of connecting these I found the mistake.

Closed 2024-08-04.

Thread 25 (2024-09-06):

TRRS ports specification

Jorres, 2024-09-06:
Hi! I would like a piece of advice about TRRS ports.

I was building a custom TRRS cable and accidentally built one with 2.5mm jacks instead of 3.5mm. (all my fault, of course, haha :)

Given that KillerWhale has two sets of TRRS ports, each side, I started thinking about whether I could replace one 3.5 port with 2.5 port on each side. So that I could use my newly built 2.5mm jacks :)

This should be theoretically possible if I manage to find the TRRS ports with exact same dimensions and pins. I started looking and found many seemingly identical ones. Could I please ask you to specify the exact name of TRRS port that you put in KillerWhale sets? Right now, both Japanese and English documentation just says "TRRS jacks":

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

Thank you so much for designing such a cool keyboard! Happily using it for almost half a year already and loving it very much!

Taro-Hayashi, 2024-09-07:
Hi, Jorres. Thank you for message.
PJ-320A or I think you could use something similar in shape.

Jorres, 2024-09-07:
Hi! Thank you very much, it seems to be it.

Closed 2024-09-07.

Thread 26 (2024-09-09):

RGB light vs RGB matrix?

Jorres, 2024-09-09:
Hello!

I'm very sorry for posting my third question already and taking much of your time.

In QMK, there are two distinct features: [RGB matrix](https://docs.qmk.fm/features/rgb_matrix) and [RGB light](https://docs.qmk.fm/features/rgblight). In KillerWhale, all RGB diodes (both under the keys, and a few ones under the keyboard) are configured as RGB light (basically, QMK treats all 66 diodes as one contiguous LED strip).

I can color different parts of the strip in my own colors, as in this example:

```
const rgblight_segment_t PROGMEM base_layer[] = RGBLIGHT_LAYER_SEGMENTS(
        {0, 3, HSV_PURPLE},
        {3, 24, HSV_RED},
        {27, 1, HSV_PURPLE},
        {28, 2, HSV_RED},
);
```

produces the following lighting on left half:

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

But it has one very inconvenient consequence: I can control only color of the diodes programmatically, [such as HSV, for example](https://docs.qmk.fm/features/rgblight#functions), but I can not change brightness and on\off status. Basically, the whole keyboard either is lit, or the whole keyboard is un-lit.

This makes a lot of interesting usecases impossible. I will try to name a few:

- light only 3 diodes in the bottom of the keyboard for a nice glow, while disabling all the remaining ones
- make a layer, where only h\j\k\l would glow, a nice vim-like feeling
- making complex animations that require turning on\off individual diodes or changing their brightness

Now, the bad part: I'm very bad at hardware, so I don't even understand if it's theoretically possible to change RGB light to RGB matrix programmatically. Maybe it even is impossible due to how wiring has been designed on Killerwhale. So my question is:

1. Maybe I'm wrong and there is a way to turn on\off diodes when using RGB light?
2. Why did you go for RGB light instead of RGB matrix? Do you think I can reprogram the keyboard to support RGB matrix, or will it require hardware modifications (and thus basically impossible)?

Taro-Hayashi, 2024-09-10:
Hi,
Although RGB Matrix can be supported, it cannot be used in the firmware to be distributed for the following reasons
- RGB Matrix is not supported by REMAP.
- Firmware for top unit with wheel must be prepared separately because the LED numbers are misaligned due to the different number of keys.

To turn off the LEDs individually, I would have to set the value of V to 0 or specify HSV_BLACK.

Thank you in advance.

Jorres, 2024-09-10:
Thank you for your response. Indeed, I didn't understand how HSV worked. For simple usecases turning leds off with HSV_BLACK worked like a charm!

Here is how lower diodes only glow in the dark, for example:
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

I will test later whether this way is fast enough for complex animations, so that the keyboard still feels responsive. But even if not, a lot of simpler cases can be solved with this workaround, so I'm happy with it.

Closed 2024-09-10.

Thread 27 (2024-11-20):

raspberry pi pico compatibility?

soemarko, 2024-11-20:
So, I bought this kit from Yushakobo, followed the instruction, flash the board. And then do the mainboard, after soldering the LED, it's not turning on when plugged in. I'm guessing that I'm somehow fried the pi.

The question is, can I use any pi pico? From pictures in local marketplace, it looked different.

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

Taro-Hayashi, 2024-11-20:
Hi, this kit is not compatible with the Raspberry Pi Pico compatible in the image. Some compatibles have lost VREF pin to increase analog IO to 4 channels and are not fully compatible with Raspberry Pi Pico.
I can sell the relevant PCB, mounting components and type-C Raspberry Pi Pico for ¥2000 plus shipping. Please contact me at my email address (rinarinapokegogo at gmail.com) with the name of the country and city I would sending it to and I'll calculate the shipping costs and get back to you with an overall quote. If you need other unit, I can sell them together.
Thanks.

soemarko, 2024-11-21:
I see. So, none of the pi pico on aliexpress, etc would be compatible?

Let me try something first, I should've socketed the pi. It's going to be hard to desolder it.

Taro-Hayashi, 2024-11-21:
These are confirmed to work.
https://ja.aliexpress.com/item/1005007299070475.html
https://ja.aliexpress.com/item/1005004937441045.html

Hope all goes well.

soemarko, 2024-11-24:
Yeah something is off. Took me awhile to desolder the pi off the pcb, but it is okay withuout the pcb.

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

I need to investigate further. Definitely need to find the socket for the pi first.

Closed 2024-11-24.

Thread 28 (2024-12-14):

Additional unit scroll wheel not scrolling?

soemarko, 2024-12-14:
I've check continuity with my multimeter, everything is connected correctly, to pin 20, 21 and GND. I've tried with another encoder (since I got two kits) also no luck. What could be the cause of this?

Taro-Hayashi, 2024-12-14:
Sorry, there seems to have been a problem with the firmware. Could you try this one?
https://github.com/Taro-Hayashi/KillerWhale/releases/tag/0.27.1

soemarko, 2024-12-15:
hmm, this is odd. a lot have changed, but the wheel scroll a little bit when first plugged. and now the trackball becomes scroll?

Taro-Hayashi, 2024-12-15:
Maybe that's how it's set up to scroll with the trackball, you can use the Mode Change key to cycle the function of operating the trackball from cursor movement to scrolling or keystrokes.
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

Or you could try resetting the Raspberry Pi Pico.
https://datasheets.raspberrypi.com/soft/flash_nuke.uf2

soemarko, 2024-12-25:
I can't figure this out. I may have shorted something, just don't have the time to keep debugging. Going to power through by building the left side and see if I can salvage the keyboard. Merry Christmas.

Taro-Hayashi, 2024-12-25:
I hope it goes well. Merry Christmas.

Closed 2024-12-25.

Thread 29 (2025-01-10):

USER 13	QK_USER_13	押している間だけ十字キー入力モードについて

mako3313, 2025-01-10:
いつもお世話になっております。
タイトルですが
duo用
common_killerwhale.c内を
/* キースキャン */
// マウスキー登録
bool is_mouse_record_kb(uint16_t keycode, keyrecord_t* record) {
    switch(keycode) {
        case MOD_SCRL: // 一時的にスクロール
            return true;
        case QK_USER_4: // 一時的に減速
            return true;
        case QK_USER_9: // マウス1 / 長押しスロー
            return true;
        case QK_USER_10: // マウス2 / 長押しスロー
            return true;
        case QK_USER_11: // マウス3 / 長押しスロー
            return true;
        case QK_USER_12: // 一時的にカーソル移動
            return true;
        case QK_USER_13: // 押している間だけ十字キー入力モード
            return true;
        default:
            return false;
    }

    return  is_mouse_record_user(keycode, record);
}　
現状上記の様に変更して使用させていたただいています。
 case QK_USER_13: // 押している間だけ十字キー入力モード
            return true;
を追加したことによって問題になることはありますでしょうか？
ご確認のほどよろしくお願いします。

Taro-Hayashi, 2025-01-10:
お世話になっております。
QK_USER_13を押すことでオートマウスが反応するようになりますがそれを問題と捉えるかどうかかと存じます。
他に影響が出ることは今のところ思い当たりません。
よろしくお願いいたします。

mako3313, 2025-01-10:
ご確認ありがとうございました。
今後もよろしくお願いします。

Closed 2025-01-10.

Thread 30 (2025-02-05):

側面ユニットが反応しない

sensyuu025, 2025-02-05:
初めまして、こちらのキーボード購入者です。
問題が起きているので、質問させて下さい。

2台使用して左右の分割キーボードとして使用しています。
左右分割として使用しても単体として使用しても左右の側面ユニットが反応しません。
左は十字、右はトラックボールを使用しています。

こちらのユニットは何かドライバー等をインストールしなければ使えない代物ですか？
ビルドガイドを見直しましたが、制作手順に不備などは見当たらず（自分では）、どうしたらよいかわかりません。

何かてがかりや対応方法をご教授いただけると幸いです。
よろしくお願いします。

Taro-Hayashi, 2025-02-05:
はじめまして、USBのキーボードが動く環境であれば特にドライバー等のインストールは不要です。

側面ユニット以外は動作されますか？
両手共に側面ユニットのみ動作しないということであればベースユニットの側面ユニット側のピンソケットのはんだの量が足りない可能性がございます。キースイッチは反応するという場合はジャンパーの設定もご確認ください。
左右で側面ユニットを入れ替えてみたり、単品でのご購入でなければ組み立てていない十字キー、トラックボールも組み立ててお試しいただけますとより原因を特定しやすいと存じます。

よろしくお願いいたします。

Closed 2025-02-11.

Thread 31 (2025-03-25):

Some LEDs do not light up on top part

mariusursache, 2025-03-25:
@Taro-Hayashi, as you can see, only few of the LEDs light up. From a previous closed issue on this topic, I assume that an LED is broken and they are in series. However, after desoldering and replacing half of the LEDs surrounding the area, the issue still persists. The keys work flawlessly.

1. Can you share the order of the LEDs, on the board so that I can replace the exact dead LED?
2. What are the voltages that should be present on each LED and the pins connecting the top with the base?

Thanks!

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

Taro-Hayashi, 2025-03-25:
Hi, this is the order of the LEDs, it looks like there is a problem with 7 or 8.

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

The voltage of the LEDs is 5V. The marked leg of the LED is 0V at GND and the diagonal leg is 5V.
Regards,

mariusursache, 2025-03-25:
Thank you, that was fast! ;-)

mariusursache, 2025-03-26:
Works great now! First half is built!

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

Taro-Hayashi, 2025-03-26:
It's so cool. I've actually never seen that case and printed ball case combination before.

mariusursache, 2025-03-26:
Yes it is, I love it! Now I am trying to find some good keycaps (not a fan of this profile, will try some XDA/DSA profiles because it's easier to mix the keycaps, while for Cherry/SDA I am restricted by the varying profile).

Closed 2025-03-26.

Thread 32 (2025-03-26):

Trackball as mouse

mariusursache, 2025-03-26:
I am a bit confused about the trackball functionality. I thought it would work as a mouse (to move the mouse cursor)... but cannot get it to do this. It works for scrolling when the lowest key is pressed.

Is this a missing feature? Can it be implemented in the firmware? Or am I doing something wrong (the jumpers are properly set for trackball).

mariusursache, 2025-03-26:
PS—I am using MacOS.

Taro-Hayashi, 2025-03-27:
It would not be a hardware problem as it works as a scroll.
Please try using the mode change key as the mode of operation may have changed in some way.
By default it is set to a key here and you can assign the Mode Change Left/Right key in Remap to it.

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

Alternatively, you can use this uf2 to return the Raspberry Pi Pico to its initial state once.
https://datasheets.raspberrypi.com/soft/flash_nuke.uf2

Thank you.

Closed 2025-04-01.

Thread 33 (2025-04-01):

Left OLED not working

mariusursache, 2025-04-01:
Finalized both halves and everything works great (waiting for my resin-printed DES keycaps).

The left-side OLED screen does not show everything (the right side does). Is this normal? The OLED screen works, so it's not an issue with it.

Taro-Hayashi, 2025-04-01:
What is the status of not showing everything?
The side with USB connected can switch between layer and stats display, but the side without USB connected can only display layers.
Thanks,

mariusursache, 2025-04-01:
Left-side screen is blank (off), does not show anything. It is part of the trackball assembly.

1. I connected only left side - problem persists
2. I flashed with nuke firmware, then again with duo firmware - problem persists
3. Soldering is fine

mariusursache, 2025-04-03:
Built a separate trackball and it works.

Closed 2025-04-03.

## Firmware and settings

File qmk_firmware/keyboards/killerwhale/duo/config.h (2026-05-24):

// Copyright 2021 Hayashi (@w_vwbw)
// SPDX-License-Identifier: GPL-2.0-or-later

#pragma once
#define KEY_INPUT 0
#define CURSOR_MODE 1
#define SCROLL_MODE 2
#define GAME_MODE 3

//////////////////////
/*    ユーザー設定    */
//////////////////////

// 入力モードデフォルト
// KEY_INPUT / CURSOR_MODE / SCROLL_MODE
#define MODE_DEFAULT_LEFT CURSOR_MODE
#define MODE_DEFAULT_RIGHT CURSOR_MODE

// CPI = 400 + spd * 200 / AMP = 16.0 + (double)spd * 3.0
#define SPD_OPTION_MAX    7 // 固定: 最大値
#define SPD_DEFAULT_LEFT  3
#define SPD_DEFAULT_RIGHT 3

// 角度 = angle * 12
#define ANGLE_OPTION_MAX    29 // 固定: 最大値
#define ANGLE_DEFAULT_LEFT  8
#define ANGLE_DEFAULT_RIGHT 7

#define INVERT_LEFT_DEFAULT true            // X軸の反転
#define INVERT_RIGHT_DEFAULT true
#define INVERT_SCROLL_DEFAULT false          // スクロールの反転

// 移動量が小さい時の調節
#define SENSITIVITY_MULTIPLIER 1.1 // 一時的倍率
#define SENSITIVITY_DIVISOR 0.5   // 最終的な感度調整
#define SMOOTHING_FACTOR 0.7 // 前の動きの影響度

// スローモード時カーソル速度
#define CPI_SLOW 300
#define AMP_SLOW 4.0

// オートマウスの設定
#define AUTO_MOUSE_DEFAULT true     // デフォルトのオン/オフ
#define AUTO_MOUSE_DEFAULT_LAYER 7  // 使用レイヤー
#define AUTO_MOUSE_THRESHOLD 80     // オートマウスが反応する移動量
#define AUTO_MOUSE_TIME  750        // レイヤー切り替え時間
#define AUTO_MOUSE_DEBOUNCE 40      // 再度オートマウスさせるまでの時間
#define AUTO_MOUSE_DELAY 750        // 一般ボタン使用時のオートマウスオフ時間

// ジョイスティク用定数
#define NO_JOYSTICK_VAL 100         // JSの有無判定閾値
#define KEY_OFFSET 5                // キー入力閾値
#define TIMEOUT_KEY 50              // キー入力間隔

#define JOYSTICK_OFFSET_MIN_DEFAULT 70 // ジョイスティックの小さい値を無視する範囲 最大200
#define JOYSTICK_OFFSET_MAX_DEFAULT 0 // ジョイスティックの大きい値を無視する範囲 最大200

#define SCROLL_DIVISOR 100.0        // スクロール用数値調整
#define JOYSTICK_DIVISOR 40.0       // ジョイスティック用調整用

// OLED設定
#define OLED_DEFAULT true           // true: レイヤー表示, false: 数値表示
#define INTERRUPT_TIME 600          // OLED割り込み時間

// RGBレイヤーデフォルト
#define RGB_LAYER_DEFAULT true

// 一時的モード変更タップ判定ms
#define TERM_TEMP 100

// 斜め入力防止のデフォルト
#define DPAD_EX_DEFAULT true







/* ハードウェア設定（変更不要） */
// SPI SETTINGS
#define PMW33XX_CS_PIN  GP0
#define SPI_SCK_PIN GP18
#define SPI_MISO_PIN GP16
#define SPI_MOSI_PIN GP19
// I2C SETTINGS
#define I2C_DRIVER I2CD0
#define I2C1_SCL_PIN        GP9
#define I2C1_SDA_PIN        GP8
#define OLED_FONT_H "./lib/glcdfont.c"
// AUTO MOUSE
#define POINTING_DEVICE_AUTO_MOUSE_ENABLE
// SPLIT SETTINGS
#define SPLIT_HAND_PIN GP10
#define SPLIT_HAND_PIN_LOW_IS_LEFT
#define SPLIT_POINTING_ENABLE
#define SPLIT_WATCHDOG_ENABLE
#define POINTING_DEVICE_COMBINED
#define SPLIT_LAYER_STATE_ENABLE
#define POINTING_DEVICE_TASK_THROTTLE_MS 4
// RGBLIGHT LAYERS
#define RGBLIGHT_LAYERS_RETAIN_VAL

// JOYSTICK
#define JOYSTICK_AXIS_COUNT 2
#define JOYSTICK_AXIS_RESOLUTION 10

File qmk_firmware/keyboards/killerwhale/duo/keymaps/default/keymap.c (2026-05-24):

// Copyright 2021 Hayashi (@w_vwbw)
// SPDX-License-Identifier: GPL-2.0-or-later

#include QMK_KEYBOARD_H
#include "lib/add_keycodes.h"

// レイヤー名
enum layer_number {
    BASE = 0,
    ONOFF, OFFON, ONON,                       // トグルスイッチで変更するレイヤー
    LOWER, UPPER, UTIL,                       // 長押しで変更するレイヤー
    MOUSE, BALL_SETTINGS, MISC // 自動マウスレイヤー切り替えや設定用のレイヤー
};

// キーマップの設定
const uint16_t PROGMEM keymaps[][MATRIX_ROWS][MATRIX_COLS] = {
  [BASE] = LAYOUT(
        // 左手
        // 天面スイッチ
        KC_ESC,  KC_1,         KC_2,            KC_3, LT(BALL_SETTINGS, KC_4), KC_5,
        KC_TAB,  KC_Q,         KC_W,            KC_E, KC_R, KC_T,
        CMD_CTL, KC_A,         LT(MOUSE, KC_S), KC_D, KC_F, KC_G,
                 LSFT_T(KC_Z), KC_X,            KC_C, KC_V, KC_B,
                               MOD_SCRL,
        // 側面スイッチ
        KC_LNG2, KC_SPC,
        // 十字キーorジョイスティック                // ジョイスティックスイッチ
        KC_UP, KC_DOWN, KC_LEFT, KC_RIGHT,         L_CHMOD,
        // 追加スイッチ                             // トグルスイッチ
        MS_BTN2, MS_BTN1,                    MO(ONOFF),
        // 右手
        KC_6, LT(BALL_SETTINGS, KC_7), KC_8, KC_9, KC_0, KC_BSPC,
        KC_Y, KC_U, KC_I,    KC_O,             KC_P,    KC_ENT,
        KC_H, KC_J, KC_K,    LT(MOUSE, KC_L),  KC_SCLN, KC_RSFT,
        KC_N, KC_M, KC_COMM, KC_DOT,           KC_SLSH,
                             MOD_SCRL,
        KC_SPACE, KC_LNG1,
        KC_UP, KC_DOWN, KC_LEFT, KC_RIGHT,         R_CHMOD,
        MS_BTN1, MS_BTN2,                    MO(OFFON)
    ),
    [ONOFF] = LAYOUT(
        // 左手
        _______, _______, _______, _______, _______, _______,
        _______, _______, _______, _______, _______, _______,
        _______, _______, _______, _______, _______, _______,
                 _______, _______, _______, _______, _______,
                          _______,
        _______, _______,
        _______, _______, _______, _______,          _______,
        _______, _______,                            _______,
        // 右手
        _______, _______, _______, _______, _______, _______,
        _______, _______, _______, _______, _______, _______,
        _______, _______, _______, _______, _______, _______,
        _______, _______, _______, _______, _______,
                                   _______,
        _______, _______,
        _______, _______, _______, _______,          _______,
        _______, _______,                            _______
    ),
    [OFFON] = LAYOUT(
        // 左手
        _______, _______, _______, _______, _______, _______,
        _______, _______, _______, _______, _______, _______,
        _______, _______, _______, _______, _______, _______,
                 _______, _______, _______, _______, _______,
                          _______,
        _______, _______,
        _______, _______, _______, _______,          _______,
        _______, _______,                            _______,
        // 右手
        _______, _______, _______, _______, _______, _______,
        _______, _______, _______, _______, _______, _______,
        _______, _______, _______, _______, _______, _______,
        _______, _______, _______, _______, _______,
                                   _______,
        _______, _______,
        _______, _______, _______, _______,          _______,
        _______, _______,                            _______
    ),
    [ONON] = LAYOUT(
        // 左手
        _______, _______, _______, _______, _______, _______,
        _______, _______, _______, _______, _______, _______,
        _______, _______, _______, _______, _______, _______,
                 _______, _______, _______, _______, _______,
                          _______,
        _______, _______,
        _______, _______, _______, _______,          _______,
        _______, _______,                            _______,
        // 右手
        _______, _______, _______, _______, _______, _______,
        _______, _______, _______, _______, _______, _______,
        _______, _______, _______, _______, _______, _______,
        _______, _______, _______, _______, _______,
                                   _______,
        _______, _______,
        _______, _______, _______, _______,          _______,
        _______, _______,                            _______
    ),
    [MOUSE] = LAYOUT(
        // 左手
        _______, _______, _______, _______, _______,    _______,
        _______, _______, _______, _______, _______,    _______,
        _______, _______, _______, MS_BTN2, MS_BTN1, MOD_SCRL,
                 QK_USER_4, _______, _______, _______, _______,
                          MOD_SCRL,
        _______, _______,
        _______, _______, _______, _______,          _______,
        _______, _______,                            _______,
        // 右手
        _______, _______, _______, _______, _______, _______,
        _______, _______, _______, _______, _______, _______,
        MOD_SCRL, MS_BTN1, MS_BTN2, _______, _______, _______,
        _______, _______, _______, _______, QK_USER_4,
                                   MOD_SCRL,
        _______, _______,
        _______, _______, _______, _______,          _______,
        _______, _______,                            _______
    ),
    [BALL_SETTINGS] = LAYOUT(
        // 左手
        XXXXXXX,    XXXXXXX, XXXXXXX, QK_USER_14, _______, L_CHMOD,
        XXXXXXX,    XXXXXXX, XXXXXXX, XXXXXXX, L_SPD_I, XXXXXXX,
        AUTO_MOUSE, XXXXXXX, XXXXXXX, L_ANG_D, L_INV,   L_ANG_I,
                    XXXXXXX, XXXXXXX,XXXXXXX, L_SPD_D, XXXXXXX,
                             INV_SCRL,
        XXXXXXX, XXXXXXX,
        XXXXXXX, XXXXXXX, XXXXXXX, XXXXXXX,          XXXXXXX,
        XXXXXXX, INV_SCRL,                           XXXXXXX,
        // 右手
        R_CHMOD, _______, QK_USER_14, XXXXXXX, XXXXXXX, XXXXXXX,
        XXXXXXX, R_SPD_I,   XXXXXXX, XXXXXXX, XXXXXXX, XXXXXXX,
        R_ANG_D, R_INV,   R_ANG_I, XXXXXXX, XXXXXXX, AUTO_MOUSE,
        XXXXXXX, R_SPD_D,   XXXXXXX, XXXXXXX, XXXXXXX,
                                     INV_SCRL,
        XXXXXXX, XXXXXXX,
        XXXXXXX, XXXXXXX, XXXXXXX, XXXXXXX,          XXXXXXX,
        XXXXXXX, XXXXXXX,                            XXXXXXX
    ),
    [MISC] = LAYOUT(
        // 左手
        _______, _______, _______, _______, _______, _______,
        _______, _______, _______, _______, _______, _______,
        _______, _______, _______, _______, _______, _______,
                 _______, _______, _______, _______, _______,
                          _______,
        _______, _______,
        _______, _______, _______, _______,          _______,
        _______, _______,                            _______,
        // 右手
        _______, _______, _______, _______, _______, _______,
        _______, _______, _______, _______, _______, _______,
        _______, _______, _______, _______, _______, _______,
        _______, _______, _______, _______, _______,
                                   _______,
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

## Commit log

2023-06-06 Rename 説明書.md to 左手 ベースユニット.md
2023-06-06 Create ベースユニット
2023-06-06 Create 追加ユニット
2023-06-07 Update 追加ユニット
2023-06-07 Create ホイール
2023-06-07 Create 天面ユニット_ホイール
2023-06-28 ねじtoネジ
2023-07-14 次の資料のリンクが右手用にリンクされている
2023-09-01 両手ボールのファームウェアのリンクを修正
2023-09-01 ダウンロードリンクを常に最新のリリースを取ってくるように変更
2024-03-06 Translated assembly guide
2024-03-09 fix screw color
2024-09-30 add raspberry pi pico
2025-12-27 Update customization instructions in 7_カスタマイズ.md
    Removed section on LED settings and updated key mapping customization instructions.
2025-12-27 Remove LED settings from 7_CUSTOM.md
    Removed LED settings section from the documentation.
2026-01-31 Change sensor and lens part number to PMW3360DM-T2QU
    Updated the sensor and lens part number for clarity.
2026-11-07 Update instructions for 3D printer parts confirmation
2026-11-07 Fix image link for 3D printer components
    Updated image reference in README for 3D printer parts.
